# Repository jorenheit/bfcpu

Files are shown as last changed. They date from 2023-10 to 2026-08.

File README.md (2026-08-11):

# Synapse-191: A Native Brainf*ck Computer 
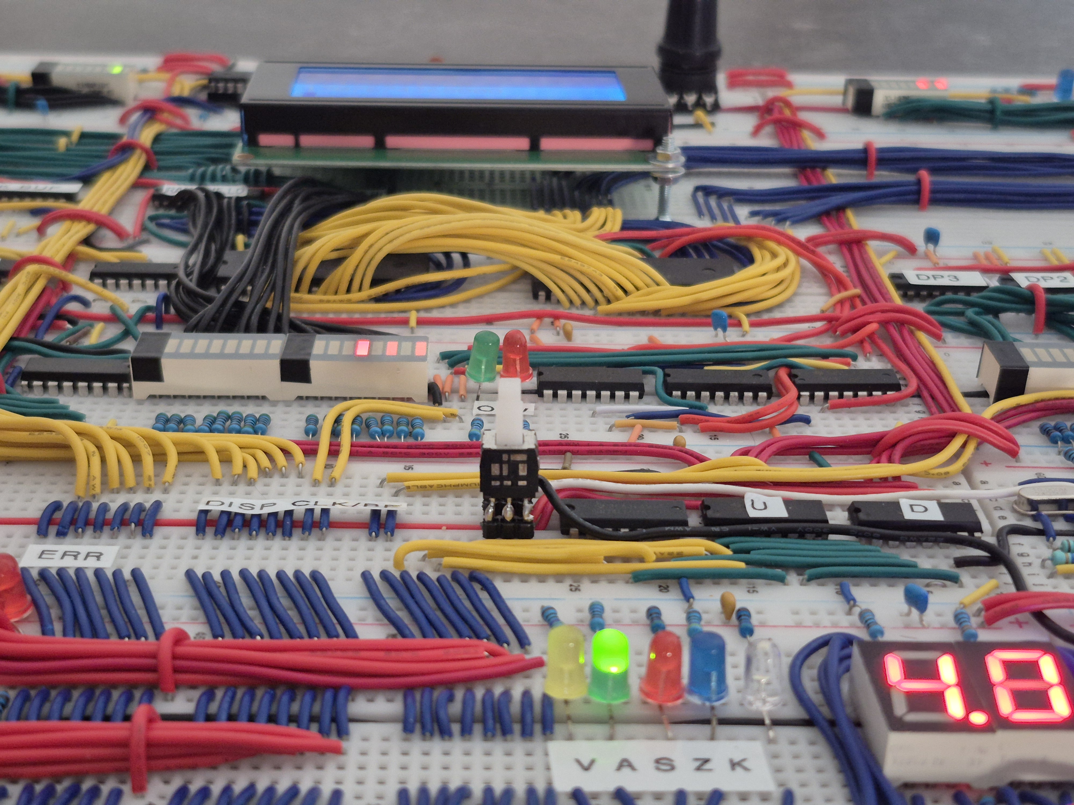
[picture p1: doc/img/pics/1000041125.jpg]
<p align="center"><kbd></kbd></p>

## Overview

**Synapse-191** is a fully functional 8-bit computer that executes Brainf\*ck (BF) programs *natively* on a breadboard CPU built entirely from TTL logic. The system is capable of running canonical Brainf*ck code directly from ROM and includes a supporting toolchain, including:
1. a compiler backend (Acus) for generating BF,
2. a microcode compiler (Mugen) for generating microcode ROM images,
3. a ROM flash utility and Arduino firmware to flash specifically the AT28C64B EEPROM chips.

For detailed design information, schematics, and background, refer to the accompanying document or website:
- **[Full Project Report (PDF)](./doc/synapse.pdf)**
- **[Web version of the report](https://jorenheit.github.io/bfcpu)**

The documentation is split in two parts: 
1. Part 1 is about building Synapse-191, including parts of the software toolchain that made this possible or easier (like the flashing utility and microcode generator). 
2. Part 2 is specifically about Acus: the software library that was developed to serve as a compiler backend for a - yet to develop - frontend. This part goes into detail about all the layers of abstraction that were developped in order to translate high-level programming concepts into the raw BF instructions.

---

## Project Goals

### Goals for Synapse-191
The initial goal of this project was to implement a working CPU that runs Brainf*ck programs *directly in hardware* — without any compilation or interpretation layers — using only discrete logic components.

- Implemented on **solderless breadboards**.
- Built entirely from **74LS-series TTL logic**.
- Only one **microcontroller** (Atmega328P) is used — exclusively for **I/O management** (LCD, keyboard, RNG).
- **Minimal preprocessing:** each Brainf*ck instruction maps directly to a hardware opcode; additional non-BF instructions generated by the assembler are used only for **initialization and system control** (NOP, INIT, WAIT\_EXT, ERR, HLT).
- **No loop-address preprocessing:** loop behavior is handled natively by the CPU logic.

### Goals for Acus
After Synapse-191 was built, a new project to build a BF compiler arose. Rather than inventing a new language and build a compiler for it, the project aimed to build a backend only. This allows for vastly different frontend implementations to re-use the same backend. The backend therefore has to be versatile and flexible. These were its design goals:

- Suitable for statically typed programming languages, supporting 8 and 16 bit signed and unsigned integers, strings and user-defined structs.
- Support for arrays of (arrays of) any of the above. Arrays must be indexable with runtime indices.
- Functions (including recursive ones).
- Pointers and function pointers.
- Global data.

**[Visit the Acus repository here.](https://github.com/jorenheit/acus)**

---

## System Features

- Supports up to **16K Brainf*ck instructions** in program memory.
- **64K-cell data tape** with **256-byte stack** for loop-address storage.
- **Advanced I/O system** supporting:
  - Keyboard input and LCD output.
  - Random number generation.
  - Multiple output and input modes (ASCII, hexadecimal, etc).
- **Adjustable clock** frequency from single-step to ~250 kHz.
- **Live frequency display** showing both clock rate and executed BF instructions per second.

<p align="center"><kbd></kbd></p>

---

## Repository Contents

### Core Tools

| Tool | Description |
|---|---|
| **bfasm** | Assembler for Brainf*ck programs. Translates BF source code into a binary image for the Synapse-191 CPU. |
| **bflash\.py** | EEPROM programming utility used to flash assembled binaries onto physical ROM chips; communicates over serial with an Arduino Nano. |
| **programmer firmware** | Firmware for the Arduino Nano that is used to program the EEPROM chips; communicates over serial with the **bflash\.py** script. |
| **io firmware** | Firmware for the Atmega328P-based I/O module. Handles the LCD display, PS/2 keyboard, random number generation, and I/O protocol. |

### External Repositories

| Repository | Description |
|---|---|
| **[Rinku](https://github.com/jorenheit/rinku)** | C++ library used to emulate and test hardware modules and microcode logic during development. |
| **[Mugen](https://github.com/jorenheit/mugen)** | Microcode compiler used to generate the control ROM images for the CPU. These are programmed once during construction. |
| **[Acus](https://github.com/jorenheit/acus)** | Compiler backend for generating BF (under construction). |

---

## Typical Workflow

1. Write a program in Brainf*ck (`.bf` file).
2. Assemble it using **bfasm** to produce a binary image.
3. Flash the binary to a ROM chip (using **bflash** or any other utility to program EEPROM chips).
4. Insert the ROM into the computer and execute the program.

### Watch the Process
Click to watch (https://www.youtube.com/watch?v=KEQ2o_t6Cj4)
---

© 2025 Joren Heit — Synapse-191 Project

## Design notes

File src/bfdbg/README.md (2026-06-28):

# `bfdbg` — terminal Brainfuck debugger

`bfdbg.py` is a self-contained Python terminal application for running and debugging Brainfuck programs. It uses the standard-library `curses` module, so on Linux/macOS it does not need extra packages.

```bash
python3 bfdbg.py program.bf
```

On Windows, install the `windows-curses` package first or run it inside WSL.

## Layout

The interface has four panes:

1. **Program** — a horizontally scrolling instruction tape. The centered instruction is highlighted, and the current instruction pointer is marked with `IP`.
2. **Memory tape** — a horizontally scrolling sparse tape with decimal, hex, and printable-character views.
3. **Output** — a virtual output screen with scrollback and ASCII/hex/decimal modes.
4. **Input terminal** — a line-buffered input pane. Lines submitted here are queued for Brainfuck `,` instructions.

## Main keys

### Execution

| Key | Action |
|---|---|
| `Right`, `Space`, `n` | Step forward one Brainfuck instruction |
| `Left`, `Backspace` | Reverse one executed instruction or cell edit using the undo log |
| `r` | Animated debug-run; redraws while running and logs compact per-instruction undo records |
| `R` | Cooperative fast-run until halt, input, or limit; redraws periodically and still logs compact per-instruction undo records |
| `x` | Reset program state: `ip=0`, `dp=0`, memory/output/input queue cleared, undo history cleared |
| `q` | Quit |
| `R` or `Esc` while running | Pause a cooperative run |
| `?` | Show help overlay |

Fast run is much quicker because it avoids redrawing after every instruction. It now yields to curses periodically, so output is flushed during long runs and keys such as `R`/`Esc`, `q`, `x`, `v`, and output scrolling remain responsive. It still records a compact inverse operation for every executed instruction, so pressing `Left` after a fast run rewinds one Brainfuck instruction at a time rather than jumping over the whole run.

### Run-to-bracket and run-to-I/O

| Key | Action |
|---|---|
| `o` | Debug-run until the next opening bracket `[` is about to execute |
| `O` | Cooperative fast-run until the next opening bracket `[` is about to execute |
| `c` | Debug-run until the next closing bracket `]` is about to execute |
| `C` | Cooperative fast-run until the next closing bracket `]` is about to execute |
| `b` | Debug-run to the current loop boundary when the instruction pointer is on `[` or `]` |
| `B` | Cooperative fast-run to the current loop boundary when the instruction pointer is on `[` or `]` |
| `.` | Debug-run until the next output instruction `.` is about to execute |
| `>` | Cooperative fast-run until the next output instruction `.` is about to execute |
| `,` | Debug-run until the next input instruction `,` is about to execute |
| `<` | Cooperative fast-run until the next input instruction `,` is about to execute |

Both debug and fast run-to commands keep compact per-instruction undo records. Debug commands redraw after each instruction and use the smaller `--run-limit`. Fast commands use the larger `--fast-run-limit` and redraw only at chunk boundaries, which keeps them responsive without destroying the speed-up.

### Program view

These are source-navigation controls; they move the program view, not the execution state.

| Key | Action |
|---|---|
| `[` | Jump view to the next opening bracket `[` |
| `]` | Jump view to the next closing bracket `]` |
| `m` | Jump view to the matching bracket, when centered on `[` or `]` |
| `{` / `}` | Scroll program view left/right by one instruction |
| `(` / `)` | Scroll program view left/right by ten instructions |
| `p` | Recenter and follow the current instruction pointer |

### Memory tape

| Key | Action |
|---|---|
| `h` / `l` | Scroll memory left/right by one cell |
| `H` / `L` | Scroll memory left/right by ten cells |
| `g` | Go to a memory address; accepts decimal or `0x...` |
| `d` | Jump back to the data pointer and follow it |
| `f` | Toggle automatic data-pointer follow |
| `e` | Edit the centered memory cell |

### Output and input

| Key | Action |
|---|---|
| `v` | Cycle output mode: ASCII, hex, decimal |
| `PgUp`, `u` | Scroll output history up |
| `PgDn`, `j` | Scroll output history down |
| `End` | Follow the bottom of the output |
| `i` | Enter input mode |
| `Enter` in input mode | Queue the current line plus a newline |
| `Esc` in input mode | Cancel input mode |

## Command-line options

```bash
python3 bfdbg.py program.bf --delay 0.01 --run-limit 100000 --fast-run-limit 10000000
```

| Option | Meaning |
|---|---|
| `--cell-bits N` | Cell width in bits. Default: `8`. Use `0` for unbounded integer cells. |
| `--delay SECONDS` | Delay between instructions during animated debug-run. Default: `0.02`. |
| `--run-limit N` | Safety cap for one debug run-to-bracket command. Default: `100000`. |
| `--fast-run-limit N` | Safety cap for one fast run command. Default: `10000000`. |

## Notes

- The Brainfuck source is filtered to the eight command characters `><+-.,[]`; comments and whitespace are ignored.
- Cells wrap at 8 bits by default. Use `--cell-bits 0` for unbounded integer cells, or another positive bit width for a different wrapping size.
- The tape is sparse and supports negative addresses, which is convenient while debugging programs that move left of zero.
- Reverse stepping uses compact per-instruction undo records rather than full snapshots. Each record stores the previous `ip`, `dp`, status flags, tick count, and only the tiny piece of state changed by the command: at most one cell value, one emitted output byte, or the input line source used by a `,`.
- Fast mode no longer creates undo gaps. It is fast because it avoids per-instruction screen redraws, not because it skips history. During long fast runs, the UI redraws periodically and polls keys, so output keeps appearing and the run can be paused or reset.
- Reset with `x` clears the machine state and undo history. It does not reload the file from disk; it restarts the already-loaded filtered program.
- Rewinding over an input command `,` treats terminal input as interactive: it restores the machine state before the command, then discards the queued line that supplied the consumed byte. This prevents a rewound `,` from silently receiving the same input again.

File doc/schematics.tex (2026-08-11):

\chapter{Schematics} \label{sec:appendix:schematics}

This appendix contains the full hardware schematics for the Synapse-191 computer. Each schematic corresponds to a specific module described in Chapter \ref{sec:implementation} of this report, including the Control Unit, Register Driver, IO Module, and various registers and memory components.

The schematics have been included as full pages for clarity and resolution. They provide a detailed view of the wiring, chip connections, and signal routing used in the physical implementation, but often do not include things like decoupling capacitors or LED indicators. The diagrams are intended to complement the modular descriptions in the main text and serve as a reference for replication, debugging, or further development.

All schematics were created during the final build phase and reflect the working configuration of the system as tested.

\includepdf[landscape=true]{schematics/masterclock.pdf}
\includepdf[landscape=true]{schematics/frequencydisplay.pdf}
\includepdf[landscape=true]{schematics/registerdriver.pdf}
\includepdf[landscape=true]{schematics/datapointerregister.pdf}
\includepdf[landscape=true]{schematics/dataregister.pdf}
\includepdf[landscape=true]{schematics/instructionpointerregister.pdf}
\includepdf[landscape=true]{schematics/stackpointerregister.pdf}
\includepdf[landscape=true]{schematics/loopskipregister.pdf}
\includepdf[landscape=true]{schematics/flagregisters.pdf}
\includepdf[landscape=true]{schematics/rammodule.pdf}
\includepdf[landscape=true]{schematics/controlunit.pdf}
\includepdf[landscape=true]{schematics/iomodule.pdf}
\includepdf[landscape=true]{schematics/eeprom_programmer.pdf}

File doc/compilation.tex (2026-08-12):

\chapter{Introduction to Acus}
\label{sec:compilation:introduction}

\section{What This is Not}
\label{sec:compilation:not}
Acus\footnote{Latin for \emph{needle}, referring to the pointer in the BF computation model.} is not a BF compiler: it is a C++ library for the development of such compilers. This chapter is \emph{not} a guide on how to use Acus. For examples and extensive API details, please visit the GitHub repository at \cite{acus}. Instead, this chapter goes through the most important concepts, methods and abstractions that allow for the translation of high-level programming concepts (like function calls and flow control) into BF.

\begin{figure}[H]
  \centering
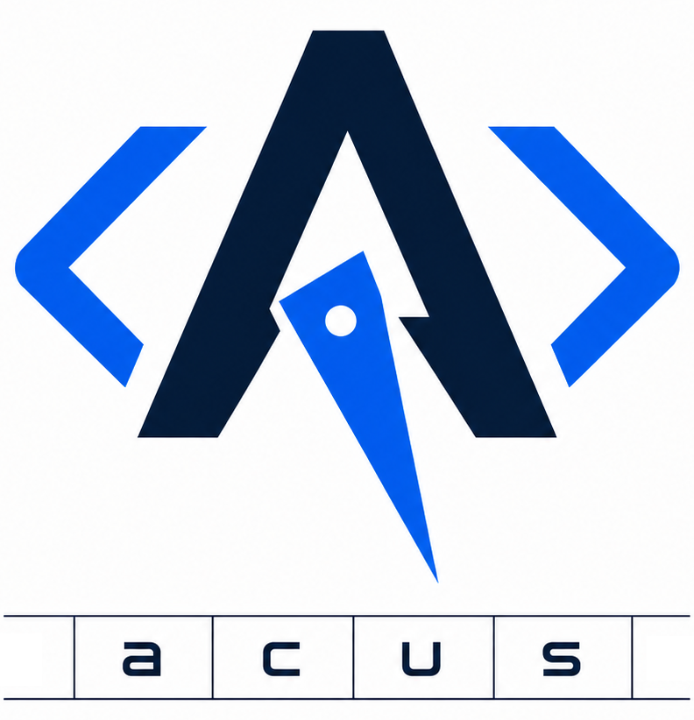
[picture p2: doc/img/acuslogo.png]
  
\end{figure}

\section{Motivation and History}
\label{sec:compilation:motivation}
Up to this point, almost every BF program used to test the computer was found online and used verbatim. On some occasions, simple BF routines were written to test very specific functions of the computer, but these were borderline trivial to produce. The next goal, therefore, was to create a compiler that takes human-readable source code and turns that into BF, which in turn can be assembled into the binary format understood by Synapse-191.

The author has attempted to create such a language and compiler in the past: \emph{BrainFix} \cite{brainfix} is a compiler that takes a C-style language and turns it into BF. This compiler works reasonably well but has some serious limitations:
\begin{itemize}\itemsep0em 
\item No (true) function calls: all functions are inlined. Recursion is therefore \emph{not} possible.
\item Dynamic array accesses were implemented in a way that limits the maximum array size to 256 elements.
\item Only 8-bit numbers are supported (assuming the BF tape stores 8-bit integers in its cells).
\item No signed integers.
\item No pointers or function pointers.
\end{itemize}
%
These limitations derive from naive choices during early development of the compiler, where the focus was on parsing and language design: features were bolted on rather than planned for in the early stages of development. In this second, more mature attempt to build a compiler, we started out by building a backend rather than a full compiler: \emph{Acus}. Acus is a C++ library that exposes a set of elementary assembly-like instructions (like arithmetic operations, conditional expressions and jumps) that are compiled into BF. Acus is meant to be used as a compiler backend: a layer that accepts higher-level operations and emits BF code. A frontend can then link with Acus, parse an actual programming language, call the necessary Acus functions and produce the corresponding BF. Acus can also be used on its own, since its library functions were designed to feel a bit like an actual language, as can be seen from the \emph{Hello World} snippet of Listing \ref{lst:acushello}\footnote{Note that using Acus in this way is unintended and inconvenient: the resulting binary is a program that, when run, prints a string of BF commands to the output. That string of commands then has to be written to a file, which can then be executed by a BF computer or interpreter. When the program is modified, the C++ source has to be recompiled and the resulting executable rerun to produce the updated BF source.}

\begin{lstfloat}[H]
  \begin{lstlisting}[style=cpp]
    #include <iostream>
    #include "acus/assembler/assembler.h"
    using namespace acus;

    int main() {
      Assembler a;

      a.program("hello", "main").begin(); {

        a.function("main").begin(); {
          a.print(literal::string("Hello, World!\n"));
          a.returnFromFunction();
        } a.endFunction();

      } a.endProgram();
      
      std::cout << a.brainfuck("hello") << '\n';
    }
  \end{lstlisting}
  \caption{C++ code that calls into the Acus-library to produce an executable that outputs BF source code for a \emph{Hello World} program.}
  \label{lst:acushello}
\end{lstfloat}

\section{Challenges and Design Goals}
\label{sec:compilation:designgoals}
The main goal was to make Acus capable enough that a frontend for a language like C would have no problem implementing most of its features. These include:
%
\begin{enumerate} \itemsep0em 
\item 8-bit and 16-bit integer data types;
\item signed integers (both 8-bit and 16-bit);
\item arrays and strings;
\item user-defined structured types (structs);
\item arithmetic operators (\texttt{+, -, *, /, \%});
\item logic operators (\texttt{and, or, not, xor});
\item function calls and recursion;
\item pointers and pointer arithmetic;
\item labels and conditional jumps (\texttt{goto});
\item global data.
\end{enumerate}
%
Familiar features that were \emph{not} implemented include:
\begin{enumerate} \itemsep0em 
\item floating/fixed-point numbers;
\item bitwise operators;
\item member functions;
\item control-flow mechanisms like \texttt{for, while, switch, if}.
\end{enumerate}
%
Many of the above can be implemented in terms of the features provided by Acus; it was a deliberate choice not to make these part of the library in order for the library to remain as fundamental as possible.

\chapter{Acus Program Model}
\label{sec:compilation:programmodel}

\section{Basic Block Scheduling}
\label{sec:compilation:program}
In the Acus model, a program consists of a series of basic blocks, sequences of code that are always executed in order, and jumps between those blocks. Each basic block ($B_i$) is compiled into its corresponding BF instructions and wrapped in a BF loop pair (i.e.~between \texttt{[} and \texttt{]}) whose entry is controlled by generated guard code $G_i$. The complete sequence of blocks is enclosed in a main loop, conditional on the value in a special BF cell, the \emph{Run} cell, which can be reset by any block when the program should be terminated. Prior to entering the main loop, a \emph{head} section $H$ is responsible for the initial setup of the data tape and the tail code $T$ is responsible for resetting the pointer to the \emph{Run} cell before the closing bracket of the main loop is encountered:

\begin{center}
  
\end{center}

The aforementioned guard code $G_i$ compares the block index $i$ to the value stored in another predefined cell: the \emph{TargetBlock} cell. Only when this cell contains the exact index of the block \emph{and} the \emph{Run} cell is still nonzero is the loop entered and its code executed. Therefore, each block should at some point set the index of the next block to be executed to keep the program going (not setting a different \emph{TargetBlock} will cause the same block to be executed ad infinitum). This approach basically implements a state machine that can be expressed in pseudocode as shown in Listing \ref{lst:acusprogram}. Note that, on each iteration of the main loop, all blocks are scanned until the scheduled block is encountered. In a worst-case scenario, when block \texttt{i} is scheduled by block \texttt{i+1} (the currently executed block), the system will first need to check all blocks from \texttt{i+2} up to \texttt{N} before looping back to block 1 and eventually block \texttt{i}.

\begin{lstfloat}[H]
  \begin{lstlisting}[style=pseudocode]
    B = {B1, B2, ..., Bn}

    Run = 1
    TargetBlock = 1 # not necessarily block 1

    while Run:
      for i = 1 ... N:
        if Run AND TargetBlock == i:
          execute B[i] 
  \end{lstlisting}
  \caption{Pseudocode of an Acus-generated program.}
  \label{lst:acusprogram}
\end{lstfloat}

\section{Frames and Initialization}
\label{sec:compilation:framesinit}
Each function has its own chunk of memory that it operates on, called a frame. Calling a function has the effect of advancing the data pointer one cell beyond the end of the current function's frame. When a BF program is executed, the pointer starts at cell 0 in frame 0, which is dedicated to holding the global data (Section \ref{sec:compilation:globalframe}). Frame 1 starts just beyond the end of frame 0; the exact offset depends on the number of global variables and their sizes. The initialization code that runs prior to entering the main loop needs to set up both frame 0 and frame 1:
%
\begin{enumerate}
\item Set a marker (the \texttt{SeekMarker}, Section \ref{sec:compilation:seekmarker}) at the start of the data-tape (cell 0). This marker can be used as a stop-sign during dynamic pointer movements to locate the start of the global data frame (and to prevent the pointer from moving into the (undefined) negative address-space).
\item Set another marker (the \texttt{FrameMarker}) that marks the start of frame 0 (the global data frame, Section \ref{sec:compilation:globalframe}). This might seem redundant as we already marked the start of this frame with a \texttt{SeekMarker}, but since every frame has a \texttt{FrameMarker}, the global frame needs it as well for generalized algorithms to work.
\item Calculate the size of frame 0 and move the pointer to the start of frame 1 (the frame that will be used by the function that is set as the entrypoint for the program). 
\item Mark the start of frame 1 by setting the \texttt{FrameMarker} here as well.
\item Move the data pointer to the \emph{Run} cell of frame 1 and set its value to 1.
\item While the data pointer points to the \emph{Run} cell of frame 1, open the main loop (guaranteed to be entered as we just set this cell to 1).
\end{enumerate}

\section{Block Guards}
\label{sec:compilation:blockguards}
The guards $G_i$ compare the value stored in the \texttt{TargetBlock} cell to their index and check if the \emph{Run} flag is still set. The results of these comparisons are ANDed together and used as the loop condition for the block that follows immediately after. Because the block index is known at compile time, it can simply be subtracted from (a copy of) the \texttt{TargetBlock} value. If the result is 0, this means we should enter the block given that the \emph{Run} cell contains a nonzero (true) value. The logic necessary to implement these checks is discussed in more detail in Section \ref{sec:compilation:logic}. A simplified BF algorithm that implements this logic could look like the snippet of Listing \ref{lst:guard}; the real algorithm is more complicated because it needs to support 16-bit block indices (otherwise each program would be limited to only 255 code blocks), which requires 16-bit arithmetic and logic routines (Section \ref{sec:compilation:arithmetic}).

\begin{lstfloat}[H]
\begin{lstlisting}[style=brainfuck]
  # Guard code G3: computes ``r AND i == 3''
  # r: cell that contains a copy of the run-flag
  # i: cell that contains a copy of the target-index
  # f: cell that will contain the guard-flag (result of r AND i == 3)

  f [-]                  # reset f
  r [                    # if run
    f +                  # set guard-flag to 1
    i --- [              # subtract 3 from i, check if nonzero
      f -                # still nonzero -> set flag to zero
      i [-]              # exit i-loop
    ]
    r -                  # exit r-loop
  ]

  # At this point, f is set only when r was set and i == 3  
  f [                    # move pointer to guard-flag
    ...                  # user code (block 3)
  ]

\end{lstlisting}
\caption{Simplified guard code for block 3 ($G_3$). The contents of block 3 will be executed only if \texttt{f} is nonzero.}
\label{lst:guard}
\end{lstfloat}

\section{Example: Fibonacci}
\label{sec:compilation:fibonacci}
To illustrate how a program is divided into basic blocks, a simple Fibonacci number generator is shown in Figure \ref{fig:fibexample}. It consists of three functions, each of which contains multiple basic blocks. The block IDs are shown in square brackets at the start of each block. Blocks end at control boundaries, i.e.~places in the code where potential jumps take place, or explicitly at predefined labels.

The program starts execution in block 10, which is set as the entry point by the initialization code (note that the initialization code of Listing \ref{lst:acusprogram} sets the entry point to block 1; the specific example below requires the initialization sequence to set this value to 10 instead). A function call is immediately encountered, ending the current block. After initializing a new stack frame (this will be covered later, in Section \ref{sec:compilation:frames}), the \emph{TargetBlock} is set to block 1: the entry block index of the callee. This will cause control flow to skip over block 11 and loop back to block 1, which will then be entered. When control hits the conditional statement of block 3, either block 4 or 5 will be set as the next target block, depending on the result of evaluating \texttt{i < n}. In this case, both the \texttt{if} and \texttt{else} bodies contain only a single block that immediately terminates in a jump. When control eventually reaches the end of \texttt{main}, the \emph{Run} cell is set to zero, causing flow to exit the main loop and terminate the program.

\begin{figure}[H]
  \centering
  \begin{subfigure}{0.4\linewidth}
    \centering
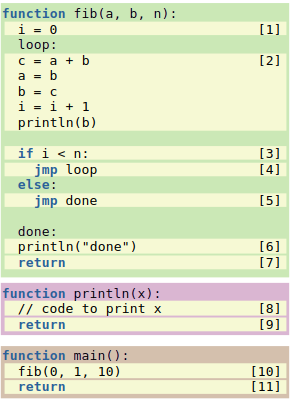
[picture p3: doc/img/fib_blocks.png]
    
    \caption{Fibonacci program}
    \label{fig:fibblocks}
  \end{subfigure}
  \hspace{1cm}
  \begin{subfigure}{0.4\linewidth}
    \centering
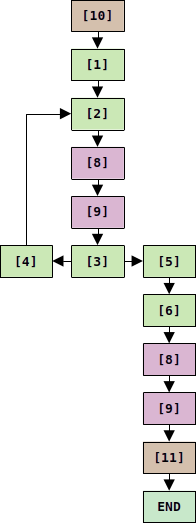
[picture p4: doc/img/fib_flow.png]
    
    \caption{Control flow}
    \label{fig:fibflow}
  \end{subfigure}
  \caption{Figure (a) shows a simple Fibonacci program (unspecified syntax) and how that program is split into blocks. Figure (b) shows how control flows from one block to another.}
  \label{fig:fibexample}
\end{figure}

\chapter{Tape Abstractions}
\label{sec:compilation:tape}
\section{Overview}
\label{sec:compilation:tapeoverview}
The data-tape is considered a stack, where each function owns a stack frame. Each frame is composed of slots: a return-slot (if the function returns a value), argument-slots (if the function takes arguments) and local data-slots (variables and temporaries used in the function). A slot is a series of (logical) cells that contains a variable of some data-type, used by the function. The size of a slot depends on the number of cells required to represent the type of the variable. Instead of using single BF-cells to compose slots, logical cells or macro-cells are used. Each macro-cell contains 9 actual BF-cells, referred to as \emph{fields} from now on, each of which serves a different purpose.
\[
\text{BF Cell}
\longrightarrow
\text{MacroCell}
\longrightarrow
\text{Slot}
\longrightarrow
\text{Frame}
\longrightarrow
\text{Tape}
\]
A macro-cell contains the following fields (in arbitrary order), each of which will be discussed in more detail in Section \ref{sec:compilation:macrocells}.
\begin{enumerate}\itemsep0em 
\item \texttt{Value0}: Low-byte of the semantic value of the macro-cell.
\item \texttt{Value1}: High-byte of the semantic value of the macro-cell.
\item \texttt{Scratch0}: General-purpose scratch-cell.
\item \texttt{Scratch1}: General-purpose scratch-cell.
\item \texttt{Payload0}: Low-byte of a payload (or another scratch-cell).
\item \texttt{Payload1}: High-byte of a payload (or another scratch-cell).  
\item \texttt{Flag}: Dedicated flag cell to guard BF-loops.
\item \texttt{FrameMarker}: Dedicated cell to mark the start of a new frame.
\item \texttt{SeekMarker}: Dedicated cell to mark arbitrary locations on the tape.
\end{enumerate}

Central to the macro-cells are the two value-fields that hold the actual value of the logical cell. By having two value fields, we allow for 16-bit data types to be implemented within the same logical-cell, rather than having to allocate two macro-cells for a single 16-bit variable. The other fields hold temporary data or metadata required to perform higher level functions like arithmetic, flow control and dynamic pointer movement. When the compiler needs to generate code that moves the BF-pointer to location known only at runtime (for example when dereferencing pointers or accessing array elements by a dynamic index), these fields can hold temporary values or metadata necessary to perform the move. Other non-value fields include temporary scratch-pads (heavily used when performing arithmetic operations), payload-fields (used to transport data to locations known only at runtime) and a flag cell that is dedicated to the evaluation of loop-conditions. Having all these fields near one another on the BF-tape has the nice consequence of BF-algorithms being relatively short due to tight pointer-move-sequences.

\subsection*{Example: Fibonacci (continued)}
Figure \ref{fig:tapehierarchy} shows the tape hierarchy described above, applied to the Fibonacci example from before and evaluated immediately after \texttt{fib} was first called. Even though this program made no use of any global data, this frame is still depicted for completeness' sake. Zooming in on Frame 2, used by the \texttt{fib} function, we see how a frame starts with the slots we previously encountered in Section \ref{sec:compilation:program}: the \texttt{TargetBlock} and \texttt{Run} slots, which are used to determine where to jump next and whether to continue execution at all. Since \texttt{fib} does not return anything, no return slot has been allocated to this frame. Instead, the local data immediately follows: first the arguments passed to the function (initialized by the caller), then the local data used within the function. Only the variables \texttt{c} and \texttt{i} have been explicitly allocated by the programmer, but temporary slots have been created by the compiler to store the result of \texttt{a + b} and \texttt{i < n}.

Zooming in further on two of the slots, we see that they both contain only a single macro-cell and its 9 constituents. The first slot of the frame (\texttt{TargetBlock}), which still holds ID 1 (the block-ID of the first block of the function) in its value-field, also has its \texttt{FrameMarker} field set, indicating that this is where a new frame starts on the data-tape. The \texttt{b}-slot has its value-field set to 1 as well, corresponding to the value of \texttt{b} that was passed to \texttt{fib} from \texttt{main}. 

The sections below go into more detail about each of the layers of abstraction.

\begin{figure}[H]
  \centering
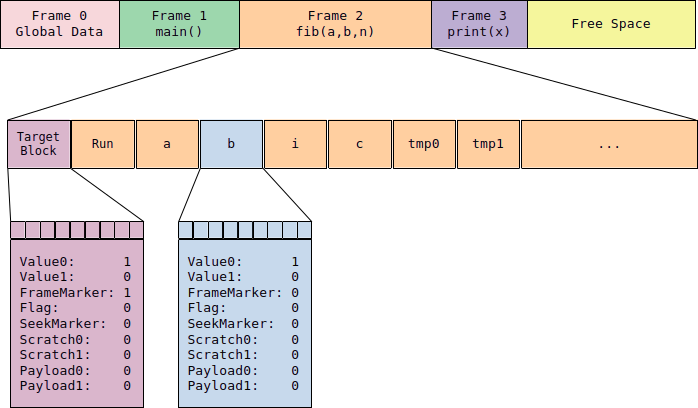
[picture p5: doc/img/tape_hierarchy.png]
  
  \caption{Acus tape hierarchy: the tape is divided into frames, which are divided into slots, which consist of macro-cells containing 9 fields (BF-cells).}
  \label{fig:tapehierarchy}
\end{figure}

\section{Cells and Macro-Cells}
\label{sec:compilation:macrocells}
BF operates on the most fundamental level of raw cells. Each consecutive sequence of 9 such cells constitutes a logical macro-cell as mentioned before in Chapter \ref{sec:compilation:tape}. In this section, we will cover each of the 9 fields of a macro-cell in more detail and cover some of their use cases.

\subsection{\texttt{Value0} and \texttt{Value1}}
\label{sec:compilation:valuefields}
The value fields together hold the semantic value of the macro-cell. The \texttt{Value0} field contains the low byte and the \texttt{Value1} field holds the high byte of an integer of at most 16 bits. Acus implements four integer data types using these two fields: unsigned 8-bit (\texttt{u8}), unsigned 16-bit (\texttt{u16}), signed 8-bit (\texttt{s8}) and signed 16-bit (\texttt{s16}). When referring to 8-bit values, the \texttt{Value1} field is simply ignored. Signed integers are represented using two's complement; some algorithms need to do some additional work (like evaluating the sign bit) before applying the usual operations.

\subsection{\texttt{Scratch0} and \texttt{Scratch1}}
\label{sec:compilation:scratchfields}
Many BF algorithms need temporary cells as scratch-pads. These cells can be temporarily claimed by an algorithm and must be left behind empty for the next algorithm to use. An example of a simple algorithm that makes use of these values is the non-destructive addition. Say we want to add the contents of cell \texttt{x} to those of cell \texttt{y} without destroying \texttt{x} in the process. We can achieve this by decrementing \texttt{x} while at the same time incrementing \texttt{y} until \texttt{x} becomes zero. However, in order to restore \texttt{x} to its original value, we need to use a scratch-pad to construct a copy of \texttt{x} which is moved back after the addition has been completed. This algorithm is shown in Listing \ref{lst:bfadd}, where instead of denoting pointer-movement with sequences of \texttt{<} and \texttt{>}, we simply write the name of the variable/slot to indicate a move to that (known) location on the tape.

\begin{lstfloat}[H]
\begin{lstlisting}[style=brainfuck]
  # Algorithm for y += x
  # tmp is a scratch-cell assumed 0

  # Step 1: add x to both y and tmp, destroying x
  x[- y+ tmp+ x]

  # Step 2: add tmp back to the now empty x
  tmp[- x+ tmp]
\end{lstlisting}
\caption{Non-destructive addition of one cell to another, using a temporary scratch cell.}
\label{lst:bfadd}
\end{lstfloat}

\subsection{\texttt{Flag}}
\label{sec:compilation:flag}
The \texttt{Flag} field is reserved to store a value that determines whether or not a BF-loop should be entered. An algorithm can store an intermediate, temporary, value in the flag-cell and use that as a branch or loop-condition. Whereas scratch-cells are general purpose temporary storage locations, the flag-cell is meant to be used for this purpose alone to avoid confusion. The subsection below includes an example that also utilizes this field in Listing \ref{lst:bfseekframe}.

\subsection{\texttt{FrameMarker}}
\label{sec:compilation:framemarker}
The \texttt{FrameMarker} field is only set when the macrocell marks the start of a new frame. When performing dynamic pointer movements, a marker like this (the \texttt{SeekMarker} is used in a similar way) can be used to move from a still unknown to a known location on the tape. Let's say we know the data-pointer is somewhere in Frame 2, but we don't know where because we just performed some (dynamic) movement (i.e. an algorithm that moves the pointer by an amount that depends on runtime data). We know that the start of the frame is to the left of the current position, so we can perform the algorithm below and be sure that we're pointing at the start of the frame when the algorithm is finished. This algorithm is shown in the pseudo-BF of Listing \ref{lst:bfseekframe}. This works because every macro-cell has the same width and because exactly one FrameMarker is set at the start of the active frame.

\begin{enumerate}
\item Move the pointer to the \texttt{FrameMarker} field of the current cell. Even though the current offset is unknown, the current field \emph{is} known so we are able to switch between fields reliably.
\item Construct the logical \texttt{NOT} of the \texttt{FrameMarker} and store the result in the \texttt{Flag} field, then move the pointer to the \texttt{Flag} field.
\item Enter a loop, conditioned on the flag, where the pointer is moved 9 cells to the left on each iteration until a non-zero \texttt{FrameMarker} is encountered. In each iteration, the logical \texttt{NOT} has to be constructed and stored in the \texttt{Flag} field as before. Note that when inside a loop (meaning the flag was nonzero), the flag needs to be cleared before moving to the adjacent cell.
\end{enumerate}

\begin{lstfloat}[H]
  \begin{lstlisting}[style=brainfuck]
    # Algorithm to move the pointer back to the start of the frame
    # Current macro-cell offset is unknown; all moves are relative
    # field-switches within the same macro-cell, except for the
    # 9 left-moves, which take us exactly one macro-cell to the left.

    # Assumed: there are already implementations for assignment and
    #          the logical NOT operator.
    
    ASSIGN(Flag, NOT(FrameMarker))
    Flag [-                            # Reset flag before moving away from it
      FrameMarker  <<<<<<<<<           # Move to the frame-marker field of
                                       #   neighboring macro-cell
      ASSIGN(Flag, NOT(FrameMarker))   # Compute exit-condition
      Flag                             # Check exit-condition
    ]

    # Out of the loop: pointer is at the start of the frame
  \end{lstlisting}
  \caption{Algorithm to seek left to the start of the current frame from an unknown initial position.}
  \label{lst:bfseekframe}
\end{lstfloat}

\subsection{\texttt{SeekMarker}}
\label{sec:compilation:seekmarker}
The purpose of the \texttt{SeekMarker} field is very similar to that of the \texttt{FrameMarker} field, in the sense that it is used to mark certain cells to make dynamic movement possible. For example, a known location can be marked before performing a dynamic move, in order to be able to move back to that known location using an algorithm similar to that of Listing \ref{lst:bfseekframe}. Also, when a dynamic move has been completed, its location can be marked to make future excursions to this location more efficient. Contrary to the \texttt{FrameMarker}, which is specifically used to mark the start of a frame, the \texttt{SeekMarker} field may be set for any macro-cell on the tape.

\subsection{\texttt{Payload0} and \texttt{Payload1}}
\label{sec:compilation:payloadfields}
The payload fields are used to store values that need to be transported along to dynamically determined locations. Algorithms that move the pointer to such locations can be trivially extended to move data along using these fields: one for the low byte and one for the high byte of the value. Additionally (but this is not the intended use-case), a payload cell may be used as a scratch-pad (when an algorithm has exhausted the available scratch cells), provided it is not being used to transport any values at that time.

\section{Slots}
\label{sec:compilation:slots}
A slot is a storage location for one object. Single 8 or 16-bit integers occupy a single macro-cell, while larger objects like arrays or structs occupy a sequence of macro-cells. A slot is bound to a stack frame; its offset is defined as the index of its first macro-cell with respect to the start of the frame, not the start of the actual BF data-tape.

In addition to a name and offset, a slot holds information about its scope (to determine access, allow for name-shadowing and keep track of lifetime) and its \emph{kind}. Most slots are of the \emph{local} kind, representing data local to the current function, but slots can also be tagged \emph{global}, \emph{available} (representing a free block of memory that was previously occupied), \emph{temp} (for temporary slots that should be freed after use) and \emph{cache} (Chapter \ref{sec:compilation:cache}). Figure \ref{fig:slots} shows a section of a frame and how local slots could be organized given their data-types and sizes. Note that the size of a slot is expressed in terms of the number of macro-cells rather than raw BF cells.

\begin{figure}[H]
  \centering
  
  \caption{Slots represent variables, which may span multiple macro-cells.}
  \label{fig:slots}
\end{figure}

\subsection{Data Types}
\label{sec:compilation:datatypes}
Slots reserve space on the tape, but the compiler also needs to know how that space should be interpreted. This is the role of data types. A data type determines how many macro-cells are needed to store a value, which sub-slots exist inside that value, and which algorithms may be used to copy, compare, increment or otherwise manipulate it.

Primitive integer types (such as \texttt{u8} or \texttt{s16}) are stored directly in the value fields of a single macro-cell (even 16-bit integers fit in a single logical cell). Compound types (arrays and structures) are constructed from these primitives. An array is represented as a sequence of equally sized elements, while a structure is represented as a sequence of fields at fixed offsets. As a result, the compiler can compute the size of every type and the offset of every field at compile-time.

\begin{table}[H]
\centering
\begin{tabularx}{\textwidth}{r c X}
\hline
\textbf{Type} & \textbf{Size (\# macro-cells)} & \textbf{Description} \\
\hline
\texttt{u8} &
1 &
Unsigned 8-bit integer stored in one value field. \\

\texttt{s8} &
1 &
Signed 8-bit integer, stored using the same physical layout as \texttt{u8}. \\

\texttt{u16} &
1 &
Unsigned 16-bit integer stored across both value fields of a macro-cell. \\

\texttt{s16} &
1 &
Signed 16-bit integer, stored using the same physical layout as \texttt{u16}. \\

\texttt{array<T, N>} &
$N \cdot \mathrm{sizeof}(T)$ &
Fixed-size sequence of \texttt{N} values of type \texttt{T}, stored contiguously. \\

\texttt{string<N>} &
$N$ &
Fixed-size character buffer, equivalent in layout to an array of \texttt{N} byte-sized characters. \\

\texttt{ptr<T>} &
2 &
Pointer to a value of type \texttt{T}. The type parameter determines how dereferenced storage is interpreted. The first cell contains the \texttt{FrameDepth} of the pointer, i.e. how many frames back the pointee is actually stored. The second cell stores the offset of the pointee within its frame. Refer to Section \ref{sec:compilation:pointers} for more details on pointers. \\

\texttt{struct}-defined type &
sum of field sizes &
User-defined aggregate type. Fields are stored consecutively at statically known offsets. \\
\hline
\end{tabularx}
\caption{Overview of the data types supported by Acus. Sizes are measured in macro-cells rather than raw Brainfuck cells.}
\label{tab:acus-types}
\end{table}

\subsection{Slot Proxies and Materialization}
\label{sec:compilation:slotproxies}
Most expressions encountered by the compiler can be resolved directly into a slot. For example, assume \texttt{x} is an array of structs that contain an \texttt{age} field, e.g. 

\begin{lstlisting}
  struct Person {
    id:  u16
    age: u8
  };

  let x: array<Person, 5>;
\end{lstlisting}

In this context, the expressions \texttt{x}, \texttt{x[2]} and \texttt{x[2].age} all refer to known slots or sub-slots (assuming square brackets represent array indexing and a dot represents field access for struct objects). The compiler knows in which slot the array \texttt{x} is stored, how to find the offset of element 2 and how to find the offset of the \texttt{age} field.

However, when the index is not a compile-time constant, things change. The expression \texttt{x[i].age} has the same shape as \texttt{x[2].age} (they might even refer to the same data), but now the compiler has no way to compute the desired offset at compile-time. At this point, the expression can no longer be represented by a single statically known slot. The array itself still has a known base location, and the layout of each \texttt{Person} object is still known, but the particular element that should be accessed depends on a value computed at runtime. In Brainfuck terms, the compiler must now generate code that moves through the tape dynamically, using the value of \texttt{i} to reach the correct element before applying the fixed offset of the \texttt{age} field.

This is where Acus introduces the notion of a \emph{slot proxy}. A slot proxy is not necessarily a slot by itself, but a description of how a value can be accessed. Some proxies are direct: they simply refer to an already known slot. Others are indirect: they describe an access path that must be resolved at runtime. The expression \texttt{x[2].age} can be reduced to a direct sub-slot, while \texttt{x[i].age} becomes a proxy that says, in effect: start from the slot occupied by \texttt{x}, use the runtime value of \texttt{i} to select an element, and then access the \texttt{age} field within that element. In general, modifications made to that element (e.g. \texttt{x[i].age += n}) will need a read-modify-write cycle where the element is first \emph{materialized} into a known, temporary slot (much like a hardware register), modified and written back using a dynamic write-algorithm. This process of materialization and write-back is shown conceptually in Figure \ref{fig:materialization}.

\begin{figure}[H]
  \centering
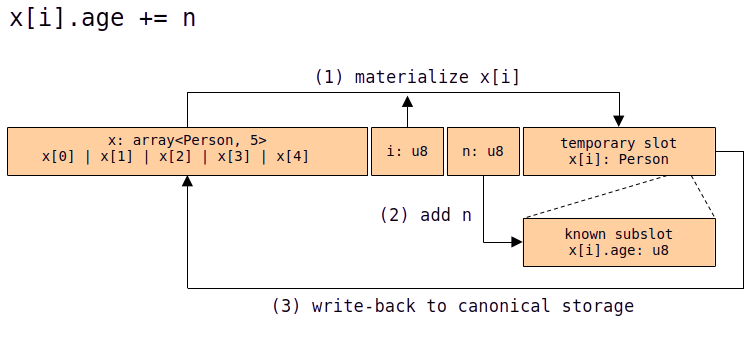
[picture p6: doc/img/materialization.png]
  
  \caption{Materialization process for a modification to a dynamically indexed array.}
  \label{fig:materialization}
\end{figure}

The distinction between actual slots and proxies that represent them allows the compiler to treat simple variables, struct fields, array elements and pointer dereferences in a uniform way. Code that needs to read from or write to an expression does not have to know immediately whether the target is a fixed slot or a dynamically computed location. It can ask the proxy to materialize the value into a concrete slot, or to write a concrete value back through the described access path.

For the purposes of this chapter, slot proxies should therefore be understood as compiler-level access paths. They bridge the gap between the static memory layout known at compile-time and the dynamic addresses that sometimes have to be computed at runtime. This idea becomes especially important in the caching system (Chapter \ref{sec:compilation:cache}), which is designed to limit unnecessary materialization and synchronization events.

\subsection{Local Memory Management}
\label{sec:compilation:localmemory}
Declaring a local variable means reserving a slot inside the current function frame. The slot is assigned a type, a size and an offset relative to the start of the frame. From that point onward, the variable name refers to this slot until it goes out of scope. Since the offset is fixed, accessing a local variable does not require a runtime search through the tape.

Temporary slots are allocated in the same frame when the compiler needs short-lived storage. This happens, for example, when evaluating intermediate expressions, materializing a slot proxy, or running algorithms that require additional scratch space. Unlike named locals, temporaries are not part of the source-level program and may be released as soon as the generated code no longer depends on their contents.

When a slot is freed, either because a local variable leaves scope or because a temporary can be dismissed, its region is marked as available. The contents of the underlying macro-cells are not necessarily cleared immediately; freeing a slot only means that the compiler is allowed to reuse that region for later storage. When a new slot is allocated, a sufficiently large available region may be split into an occupied part and a smaller remaining available part. Conversely, when a slot is freed, neighbouring available regions are merged back together. This prevents the local frame from becoming unnecessarily fragmented and allows larger slots to be allocated later when enough adjacent macro-cells have become free. This management system is discussed in more detail in Chapter \ref{sec:compilation:memorymanagement}.

\section{Frames and Calls}
\label{sec:compilation:frames}
A frame groups all data belonging to one function activation. Each frame contains the local control cells, optional return storage, arguments, named locals and compiler-generated temporaries (and cached values). Function calls can then be viewed as transitions between frames: the caller prepares the callee frame, moves the data-pointer to the start of the frame and sets the \texttt{TargetBlock} value to the callee's entry block. When a function returns, the data-pointer is moved back to the caller's frame and execution continues at the first block beyond the call. Each of these steps will be described in more detail in the sections below.

\subsection{Reference Frames}
\label{sec:compilation:referenceframes}
Each stack frame acts as a frame of reference, or coordinate system, to the data-pointer. Since function calls happen dynamically, stack frames are allocated dynamically as well. This means that the compiler has no way of knowing where the data-pointer is located in an absolute sense (i.e. with respect to the start of the BF-tape). Instead, it keeps track of the pointer-location with respect to the start of the current frame. Pushing a new frame on top of the stack and moving the pointer to the start of this frame can then be seen as performing a coordinate transformation---or rebase---of the pointer: the origin is now in the frame of the callee rather than the caller.

\subsection{Global Data Frame}
\label{sec:compilation:globalframe}
Global data is allocated in its own frame at the very start of the data-tape, i.e. frame 0. This frame is not owned by any function and is accessible from any other frame to fetch data from or write to. Like dynamic array accesses or pointer dereferences, a global slot is accessed through a slot-proxy and will be materialized locally before any work can be done on it. This introduces synchronization issues across call boundaries, which will be addressed in Chapter \ref{sec:compilation:cache}. In the sections below, the concept of (stack) frames refers to frames actually tied to the functions being executed, not the global frame.

\subsection{Frame Layout}
\label{sec:compilation:framelayout}
The exact layout of a frame depends on the nature of the function that it belongs to, depending on the return-type and number of arguments it takes. However, each instance of a function-call will cause an identical frame-layout to be generated as a result. In general, a frame is laid out as follows (in terms of macro-cells):
\begin{enumerate}
\item \texttt{TargetBlock}: a macro-cell whose \texttt{Value} fields are set to the index of the next block scheduled for execution and whose \texttt{FrameMarker} is set to 1, indicating the start of a new frame.
\item \texttt{Run}: a macro-cell dedicated to storing a local copy of the program's \emph{run}-state. As soon as this flag is set to 0 (from any frame), none of the blocks will execute and the main loop will be aborted.
\item \texttt{ReturnSlot}: Depending on the return-type of the function, a slot is allocated to hold the return-value. Note that this slot is located at a fixed offset, so it can be reached easily even from within the caller's frame in order to fetch the return-value. If the function returns \texttt{void}, this slot does not exist at all.
\item \texttt{Locals}: Data local to the frame, which can be categorized further:
  \begin{enumerate}
  \item local variables (including function arguments), organised in slots as discussed before in Section \ref{sec:compilation:slots}.
  \item compiler-generated temporaries
  \item cached materializations
  \end{enumerate}
\end{enumerate}

\subsection{Calls, Returns and Meta-Blocks}
\label{sec:compilation:metablocks}
\paragraph{Calls} To call a function, the caller has to perform the following actions:
\begin{enumerate}
\item Set the caller's \texttt{TargetBlock} to the ID of a compiler-generated meta-block. This is the continuation that will run after the callee returns (described in the next paragraph).
\item Copy or materialize the function arguments into the argument slots of the next frame. The offsets are known relative to the caller's frame, so this does not require a runtime search.
\item Initialize the control cells of the callee frame: its \texttt{Run} cell is set and its \texttt{TargetBlock} is set to the callee's entry block.
\item Move the data pointer to the start of the callee frame and treat this position as the new origin.
\end{enumerate}
After these steps, the runtime naturally dispatches to the block whose ID is now stored in the \texttt{TargetBlock} cell of the freshly initialized stack frame.

\paragraph{Meta-blocks} These are compiler-generated code-blocks that are scheduled at the time of the call, while still in the caller's frame. When the pointer is popped back to this frame after the callee returns, this is the value that is observed and used to determine the next block to be executed. This block is then responsible for making sure that
\begin{enumerate}
\item the return value is fetched from the callee's frame and copied into the return-slot of the caller (if provided; it may also be ignored),
\item the state of the \emph{run}-flag is copied back into the caller's frame (to propagate its state in case the callee changed it), and 
\item the \texttt{TargetBlock} cell is set to the ID of the block following the call.
\end{enumerate}

Propagating the \emph{run}-flag like this makes early termination compositional: if a callee stops the program, the caller observes the same stopped state after the return metablock has run. This allows a (builtin) function like \texttt{abort()} to be implemented.

\paragraph{Returns} To return control to the caller, we only need to make sure that the return-slot is populated appropriately and pop the data-pointer back to the frame below. The meta-block has already been scheduled and will take control immediately, finishing the transaction as described above.

Figure \ref{fig:call_return} shows data transfers and the setup that occurs while performing a call and returning from it. At the call-site, the target-blocks are set and arguments are copied over to the next frame. When returning and control has been passed to the meta-block, return-data is copied back from the callee's frame into the current one.

\begin{figure}[H]
  \centering
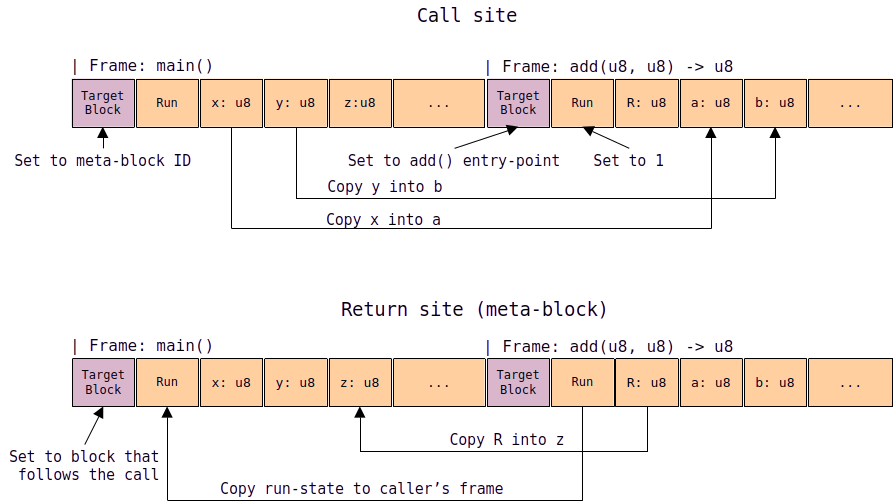
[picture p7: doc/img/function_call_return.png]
  
  \caption{Conceptual overview of data-tape manipulations that occur when calling a function and returning from it. This graphic assumes that in between these two moments, the \texttt{add} function has populated the return-slot (\texttt{R}).}
  \label{fig:call_return}
\end{figure}

Notice that the return address is not stored on a hardware stack. It is encoded as a block ID in the caller’s \texttt{TargetBlock} cell. Returning to the caller therefore means restoring the caller frame; the scheduler will then execute the metablock whose ID was already waiting there.

\chapter{Memory Management}\label{sec:compilation:memorymanagement}
\section{Overview}
Whenever a variable is declared in Acus, the allocator will look for available space in the current stack-frame. From the allocator's point of view, named locals, compiler temporaries and cache slots are all typed slots inside the current frame. They differ only in who requests them and when they are released.

This allocation can always succeed in the compiler model, because Acus assumes an unbounded Brainfuck tape and therefore allows frames to grow as needed. Frame sizes are only evaluated when the program has been fully defined and algorithms are retroactively adjusted to fit the final configuration. However, slots may also be recycled to keep the frames as tightly packed as possible; this is important to reduce the number of pointer movements. To accomplish this, the management system provides the following features:

\begin{enumerate}\itemsep0em
\item Freed slots are marked \texttt{Available} and can be reused.
\item Declarations can be scoped to reduce the lifetime of variables. Variable slots will become \texttt{Available} when the variable goes out of scope.
\item Temporary slots declared by the compiler are freed immediately after use.
\item Adjacent \texttt{Available} slots are merged to accommodate larger data types.
\item \texttt{Available} slots will split into smaller parts when a variable with a size smaller than that of the slot is allocated to it.
\end{enumerate}

\subsection{Relative Offsets}
The memory management system assigns each slot an offset relative to the start of its stack-frame. Absolute tape positions are not known at compile-time, because the same function frame may appear at different runtime locations on the tape. The compiler only needs to know the layout of one frame; generated movement algorithms are later adjusted to the final frame size.

\subsection{Free vs Clear}
When a slot is freed, its contents are not cleared. This means that no algorithm may assume that a newly allocated slot contains zero, even if that slot has just been created from previously available space. In particular, the \texttt{Value} fields of a slot must be treated as unknown until explicitly initialized. Freeing a slot is therefore purely a compiler-side bookkeeping operation and does not incur any runtime cost.

\subsection{Heap Allocation}
While technically possible, Acus does not support heap allocation. This would require a separate heap frame and a runtime system that keeps track of the memory layout in that frame (including deallocation, block splitting and block merging). The runtime overhead that would arise from managing the heap at runtime would be so costly that it was decided not to implement this as a feature. However, a front-end might emulate heap allocation using the global frame. One could certainly write algorithms on top of Acus to reserve a specific amount of raw data in the global frame and manage it using existing features.

\section{Splitting and Merging}
\subsection{Slot Splitting}
When a variable of type \texttt{T} is allocated, Acus looks for the first slot that is marked \texttt{Available} and is of size $\ge$ the size of \texttt{T} (first fit strategy, \cite{firstfit}). If the sizes match perfectly, the process ends here. If the available slot's size exceeds the variable size, the remaining part of the slot is split off into its own available slot (Figure \ref{fig:splitting}). If no available slots can be found at all, a new slot is allocated at the end of the current frame (increasing the eventual frame-size).

 \begin{figure}[H]
  \centering
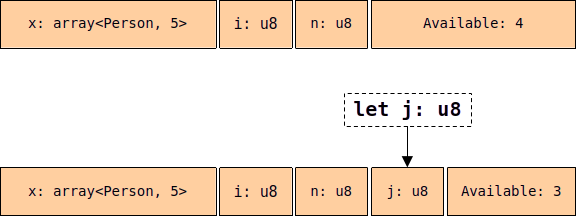
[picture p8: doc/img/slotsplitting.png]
  
  \caption{Available slots are split when a smaller variable is allocated to them.}
  \label{fig:splitting}
\end{figure}

\subsection{Slot Merging}
Named local variables live until the end of their lexical scope. Temporaries usually live only for the duration of one generated algorithm. Cache slots live until their cache entries are flushed, invalidated, or discarded at a boundary. All three are returned to the same pool of available slots. In each of these scenarios, the slot is marked \texttt{Available} by the memory management system and can be used to accommodate other data. Often, this will result in adjacent \texttt{Available} slots, which can be merged as shown in Figure \ref{fig:merging}.

\begin{figure}[H]
  \centering
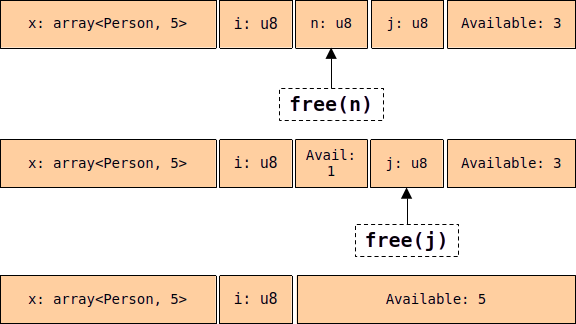
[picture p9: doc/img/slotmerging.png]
  
  \caption{Adjacent available slots are merged.}
  \label{fig:merging}
\end{figure}

\chapter{Code Generation}
\label{sec:compilation:codegen}
Before discussing larger compiler structures such as caching and dynamic access, it is useful to look at the small Brainfuck idioms from which Acus builds its generated code. Many of the algorithms in this chapter are simple in isolation, but together they form the vocabulary used to express higher-level operations on the tape. Moving or copying values, constructing constants or adding numbers together are all small patterns that appear repeatedly in the generated output.

This chapter is therefore not meant to be a complete catalogue of every algorithm implemented by Acus. Instead, it presents a representative selection: the basic destructive operations that make Brainfuck programming work, a few arithmetic operations, and the dynamic pointer-movement techniques that are most specific to compiling higher-level code to Brainfuck. 

\section{Clearing, Moving and Copying Values}
\label{sec:compilation:movecopy}
One of the simplest useful BF idioms is destructive movement: consume one cell while adding its value somewhere else. From that, one can build addition and non-destructive copying by introducing temporary storage. Basically all other algorithms rely on repeated applications of these idioms.

\subsection{Clearing Cells}
A cell can be cleared simply by moving the pointer onto it and repeatedly decrementing its value until it becomes zero: \texttt{[-]}. If the value is known to be larger than 128, \texttt{[+]} may be faster at runtime, since the cell reaches zero by overflowing rather than by decrementing all the way down.

\subsection{Moving Data}
The contents of a cell can be moved to another by decrementing its contents while incrementing that of the other. For example, to move the contents of cell \texttt{x} into cell \texttt{y} (leaving \texttt{x} empty):

\vspace{0.5cm}\noindent\begin{minipage}{\textwidth}
\begin{lstlisting}[style=brainfuck]
  # MOVE(x, y)
  y[-]
  x[- y+ x]
\end{lstlisting}
\end{minipage}

\subsection{Copying Data}
When the contents of a cell must be copied rather than moved, we need a temporary cell. The value stored in \texttt{x} is then simultaneously moved into both \texttt{y} and the temporary scratch cell \texttt{s}. When the move completes, \texttt{s} is moved back into \texttt{x} to restore its value. The scratch cell \texttt{s} is assumed to be zero before and after the operation.

\vspace{0.5cm}\noindent\begin{minipage}{\textwidth}
\begin{lstlisting}[style=brainfuck]
  # COPY(x, y)
  # Assumes s is an empty scratch cell
  
  y[-]
  x[- y+ s+ x]
  s[- x+ s]
\end{lstlisting}
\end{minipage}

\section{Constant Factories}
\label{sec:compilation:constants}
Constructing known values is fundamental to creating meaningful programs. Even a simple \emph{Hello World} requires the compiler to construct those characters somewhere in memory. The simplest and most naive way of setting a BF cell to some known value, e.g. \texttt{n}, is to concatenate \texttt{n} plus-commands. For example, the expression \texttt{x = 20} can be compiled to:
\begin{lstlisting}[style=brainfuck]
  # SET(x, 20)
  x [-] ++++++++++ ++++++++++ # 23 characters + initial move sequence
\end{lstlisting}
Notice that the cell containing \texttt{x} is first cleared using \texttt{[-]}, since we generally cannot assume that it already contains zero (even if it was freshly allocated). This particular example adds 23 characters to the generated BF output (excluding the initial move); larger values obviously produce more characters. The number of characters needed to set a cell to some constant value $c$ is simply:
\begin{align}
  N_1(x\leftarrow c) = 3 + c + m(x)
  \label{eq:n1}
\end{align}
where $m(x)$ is the number of move-commands necessary to reach the slot of \texttt{x} from the current pointer position.

To reduce code-size, we can use a scratch-cell to implement a multiplication of two smaller numbers instead. For example, instead of a series of 20 plus-commands, we can have the compiler multiply 4 and 5 to get the same result at the expense of having to use a scratch-cell \texttt{s}. Since scratch cells are allocated in a known-zero state and restored to zero after use, there is no need to clear \texttt{s} before this sequence.

\vspace{0.5cm}\noindent\begin{minipage}{\linewidth}
\begin{lstlisting}[style=brainfuck]
  # SET(x, 20)
  # Assumes s is an empty scratch cell
  
  x [-]         
  s ++++ [      
    x +++++     
    s -        
  ]
\end{lstlisting}
\end{minipage}
%
Instead of 23 characters, this algorithm adds only 15 non-movement characters to the program. In general, when $c$ can be factored into $a$ and $b$, the number of BF characters necessary to construct this value is:
\begin{align}
  N_2(x\leftarrow ab, s) = 6 + a + b + m(x) + 3m(x, s)
  \label{eq:n2}
\end{align}
where $m(x,s)$ is the number of move-commands necessary to move between the scratch-cell \texttt{s} and the target cell \texttt{x}. This value depends on the exact layout of a macro-cell but can be as low as 2 when the scratch-fields are right next to the value-fields. In the case where $m(x,s)=2$, the difference between both methods for this specific example is
\begin{align}
  N_1 - N_2 &= 3 + 20 + m(x) - (6 + 4 + 5 + m(x) + 3\cdot 2) \\
            &= 23 - 21 = 2.
\end{align}
In this small example the saving is only two characters, while the runtime cost increases because the generated loop must be executed. Luckily the benefit from the second method increases along with the value of $c$. Acus has a precomputed table of factors for all numbers up to 128 (listed in Appendix \ref{sec:appendix:factorytable}). Larger values can be reached by decrementing using the minus command to come down from 255 rather than up from 0 (BF cells wrap around after being decremented beyond 0). Each factorization $a\times b$ is chosen in such a way that it minimizes the sum $a+b$ (and consequently the number of output characters). In some cases (e.g. when $c$ itself is prime), it is better to factor a number close to $c$ and correct for the difference after doing the multiplication. For example, the optimal way to construct the value 31 is to first construct 30, then add 1, i.e. $31 = 5\times6 + 1$ for a total cost of 24 characters (as opposed to 34) for a gain of 10 characters per construction. Figure \ref{fig:constants} shows the number of characters generated for every constant up to 128 (the graph would be symmetric around this number when going from 129 to 255), for both methods. Acus implements both the naive and factorizing method and picks whichever produces the least amount of code.

\begin{figure}[H]
  \centering
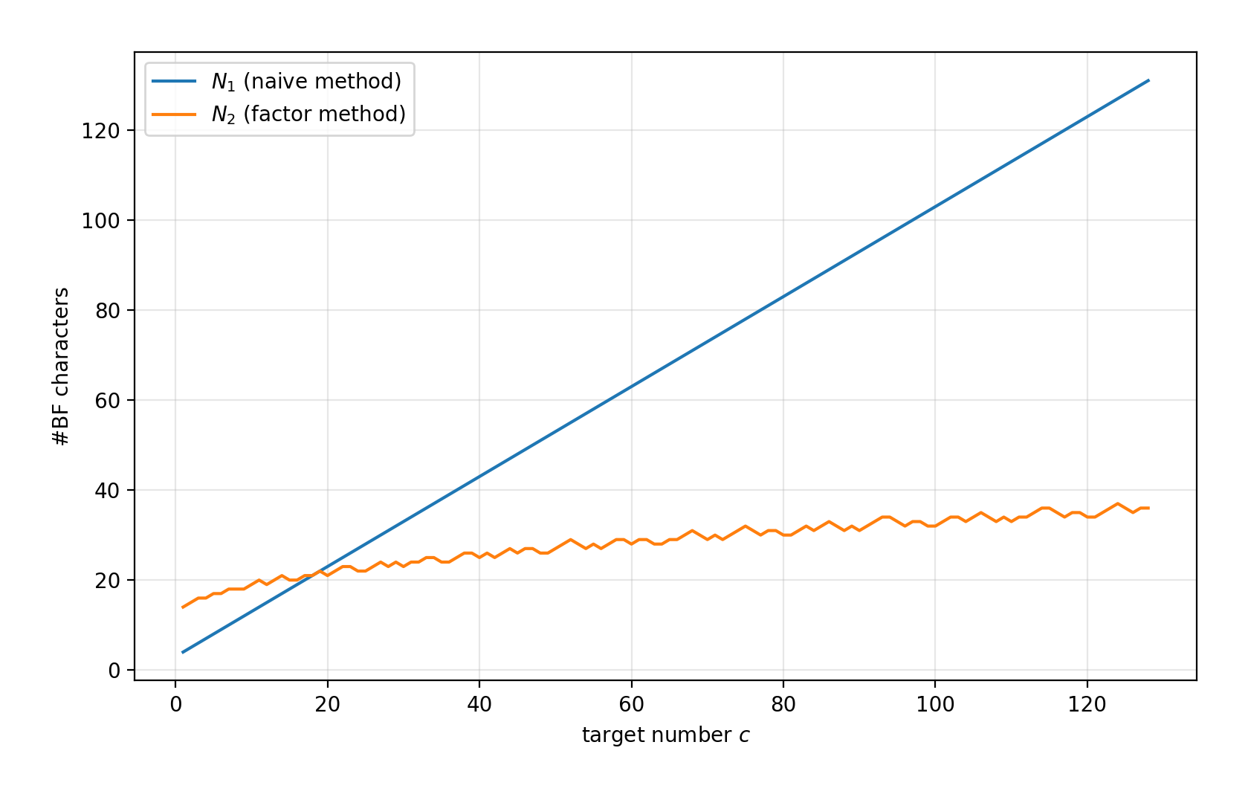
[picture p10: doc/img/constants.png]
  
  \caption{Cost of generating constants for both methods, expressed as the number of generated BF characters, as a function of their values. The common term $m(x)$ from equations \ref{eq:n1} and \ref{eq:n2} is set to zero for the purpose of this comparison.}
  \label{fig:constants}
\end{figure}

\section{Addition and Subtraction}
\label{sec:compilation:arithmetic}
\subsection{Addition (8-bit)}
\label{sec:compilation:add8}
The algorithm for addition is much like that of copying, the difference being that the target cell is never cleared in advance. When the right-hand side (rhs) of an expression of the form \texttt{x += y} may be destroyed, the algorithm is very short and efficient:

\vspace{0.5cm}\noindent\begin{minipage}{\linewidth}
\begin{lstlisting}[style=brainfuck]
  # DESTR_ADD_TO(x, y)
  y[- x+ y]
\end{lstlisting}
\end{minipage}
%
The non-destructive version requires a scratch cell to hold a copy of the rhs operand, which can then be destroyed in the process.

\vspace{0.5cm}\noindent\begin{minipage}{\linewidth}
\begin{lstlisting}[style=brainfuck]
  # ADD_TO(x, y), preserving y
  # Assumes s is an empty scratch cell
  
  COPY(y, s)
  DESTR_ADD_TO(x, s)
\end{lstlisting}
\end{minipage}

\subsection{Addition (16-bit)}
\label{sec:compilation:add16}
Adding 16-bit numbers together is much more involved and no BF pseudocode will be listed for this reason. Instead the higher-level pseudocode of Listing \ref{lst:16bitadd} illustrates the process. First, the low bytes are added together as usual. If the resulting value is less than its original value, this means that the cell has overflowed and we need to carry a 1 to the high byte. This requires multiple scratch-cells to hold temporary copies and helpers. Moreover, we need to be able to do a less-than comparison and branch on the result to carry if necessary. The implementation of this operator is discussed below in Section \ref{sec:compilation:less}.

\begin{lstfloat}[H]
\begin{lstlisting}[style=pseudocode]
  # 16-bit version of x += y
  xLowBefore = low(x)
  low(x) += low(y)          # normal 8-bit add
  if low(x) < xLowBefore:
    high(x) += 1            # carry on overflow
  high(x) += high(y)        # normal 8-bit add
\end{lstlisting}
\caption{High-level pseudocode for 16-bit addition with carry propagation.}
\label{lst:16bitadd}
\end{lstfloat}

\subsection{Subtraction}
\label{sec:compilation:subtraction}
The subtraction algorithms are symmetric to the ones for addition, where increments are substituted for decrement operations and instead of checking for overflow, we check for underflow in the 16-bit case (i.e. whether the result has grown after doing the 8-bit subtraction on the low byte).

\subsection{Signed Integers}
\label{sec:compilation:signedintegers}
For signed integers, no special algorithms have to be used at all. Since signedness is encoded using two's complement representation, addition and subtraction already work out of the box. Signedness becomes more important for comparisons, where the same bit pattern may represent a different ordering depending on how it is interpreted (as signed or unsigned).

\section{Multiplication and Division}
\label{sec:compilation:muldiv}
\subsection{Multiplication (8-bit)}\label{sec:compilation:mul8} Multiplication can be implemented in terms of repeated addition, much like we already did in the constant factory optimization. To evaluate the expression \texttt{x *= y}, we do the following:
\begin{enumerate}
\item Make a copy of the operand \texttt{x}.
\item Clear \texttt{x}.
\item Repeatedly decrease \texttt{y} while adding the original value of \texttt{x}, stored in the copy, to \texttt{x} itself.
\end{enumerate}
The steps above are the generalized version of the algorithm, which can be optimized further for edge cases where \texttt{y = 0}, \texttt{y = 1} or even for powers of 2.

\vspace{0.5cm}\noindent\begin{minipage}{\linewidth}
\begin{lstlisting}[style=brainfuck]
  # DESTR_MUL_BY(x, y)
  # Assumes s is an empty scratch cell
  
  COPY(x, s)
  x [-]
  y [-
    ADD_TO(x, s)
  ]
\end{lstlisting}
\end{minipage}
%
Like before, this algorithm destroys the rhs operand in the process. A non-destructive version can be written in terms of the destructive version:

\vspace{0.5cm}\noindent\begin{minipage}{\linewidth}
\begin{lstlisting}[style=brainfuck]
  # MUL_BY(x, y)
  # Assumes s is an empty scratch cell
  
  COPY(y, s)
  DESTR_MUL_BY(x, s)
\end{lstlisting}
\end{minipage}

\subsection{Multiplication (16-bit)}\label{sec:compilation:mul16} A naive 16-bit algorithm can simply follow the exact same procedure by relying on 16-bit addition. However, this leads to a lot of additions for large factors, which can slow down the runtime significantly. Instead, we can perform a small series of 8-bit multiplications and additions to get the same result, realizing that the 16-bit number is stored as a 2-digit base-256 number. That is, every 16-bit integer $x$ can be written as
%
\begin{align}
  x = x_0 + 256\cdot x_1,
\end{align}
%
where $x_0$ and $x_1$ are the low and high bytes of $x$ respectively. Multiplication then becomes:
%
\begin{align}
  z = x \times y &= (x_0 + 256x_1)(y_0 + 256y_1) \\
                 &= x_0y_0 + 256\cdot(x_1y_0 + x_0y_1) + 256^2\cdot(x_1y_1)
\end{align}
%
The final term only contributes to bits beyond the lowest 16 bits, so it can be discarded when the result is stored as a 16-bit value. This means that the low and high byte of the product $z$ can be expressed as
%
\begin{align}
z_0 &= x_0 y_0 \bmod 256 \\
z_1 &= \left(x_0 y_1 + x_1 y_0 + \left\lfloor \frac{x_0 y_0}{256} \right\rfloor \right) \bmod 256 
\end{align}
%
Therefore, the 16-bit product can be computed using three 8-bit multiplications. The low byte of the result comes from the low byte of $x_0y_0$, while the high byte receives the carry from this product together with the low bytes of the two cross-products.

\vspace{0.5cm}\noindent\begin{minipage}{\linewidth}
\begin{lstlisting}[style=pseudocode]
  p0 = low(x)  * low(y)
  p1 = low(x)  * high(y)
  p2 = high(x) * low(y)

  low(z)  = low(p0)
  high(z) = low(p1 + p2 + high(p0))
\end{lstlisting}
\end{minipage}

\subsection{Division (8-bit and 16-bit)}
\label{sec:compilation:division}
Unsigned division is implemented using repeated subtraction. Given two values \texttt{x} and nonzero \texttt{y}, the goal is to compute a quotient \texttt{q} and remainder \texttt{r} such that
%
\begin{align}
x = qy + r, \qquad 0 \leq r < y.
\end{align}
%
The simplest way to do this is to repeatedly subtract \texttt{y} from a running remainder until doing so would make it negative. The number of successful subtractions is the quotient, while the value left behind is the remainder.

For 8-bit unsigned values, this can be expressed by first copying the dividend into \texttt{r} and clearing \texttt{q}. Then, as long as \texttt{r} is greater than or equal to the divisor, the divisor is subtracted from \texttt{r} and \texttt{q} is incremented. In high-level pseudocode:

\vspace{0.5cm}\noindent\begin{minipage}{\linewidth}
\begin{lstlisting}[style=pseudocode]
  # unsigned 8-bit division: x / y
  q = 0
  r = x

  while r >= y:
    r -= y
    q += 1
\end{lstlisting}
\end{minipage}

The actual BF implementation cannot test \texttt{r >= y} directly. Instead, this comparison is implemented using scratch cells: temporary copies of \texttt{r} and \texttt{y} are decremented together until one of them reaches zero. If the copy of \texttt{y} reaches zero first or at the same time as \texttt{r}, the subtraction is safe and the loop may continue. If the copy of \texttt{r} reaches zero first, the next subtraction would underflow and the algorithm terminates. The original values must either be preserved during this test or reconstructed afterwards, which makes division considerably more expensive than addition or multiplication.

The same idea also applies to 16-bit unsigned division. The quotient is repeatedly incremented while the divisor is subtracted from a 16-bit remainder. The only difference is that the comparison and subtraction are now multi-byte operations, using the borrow and comparison mechanisms described earlier. This makes the algorithm correct but relatively slow for large quotients, since the number of loop iterations is proportional to the resulting quotient.

The generated implementation handles a zero divisor separately according to the rules in Section \ref{sec:compilation:divby0}.

\subsection{Signed Multiplication and Division}
\label{sec:compilation:signedmuldiv}
Signed multiplication and division are implemented as thin layers around the corresponding unsigned algorithms. First, the sign bit of the left-hand side is inspected. If it is set, the value is negated in place and a temporary flag is set to indicate that the final result should be negative. The right-hand side is copied into temporary storage before its sign is inspected, so the original divisor or multiplier does not have to be modified. If this copy is negative, it is negated as well and the result-sign flag is toggled. At this point, both operands have been converted to positive values, while the temporary flag records whether the original operands had opposite signs.

The actual multiplication or division can then be performed using the unsigned algorithm. After this operation has completed, the result-sign flag is checked. If it is set, the result is negated back into two's complement form. This approach avoids having to implement separate signed versions of the core multiplication and division algorithms; signedness is handled only by pre-processing the operands and post-processing the result.

When division also produces a remainder, Acus follows the same convention as C++ integer division: the quotient is truncated toward zero and the remainder has the same sign as the dividend. In other words, for \texttt{x / y} and \texttt{x \% y}, the generated code preserves the relation
%
\begin{align}
  x = (x / y)\cdot y + (x\%y),
\end{align}
%
where \texttt{x \% y} follows the sign of \texttt{x}. This convention was chosen because it is familiar from C++ and maps naturally onto the implementation: expressions evaluated at compile-time (constant-folding) using the C++ \texttt{\%} operator will therefore produce the same result as the runtime.

\subsection{Division by Zero}\label{sec:compilation:divby0}
To deal with division by zero, Acus will simply fill the result with the maximum value allowed by the width of the type: 255 for \texttt{u8} or 65535 for \texttt{u16} unsigned integers. For signed integers, the same bit-representation will be used, resulting in (a somewhat confusing) value of -1. The exception to this rule is when the numerator is 0 as well, in which case the result will become 0. Modulo operations where the denominator is 0 will always result in a value of 0.

\section{Boolean Operations}
\label{sec:compilation:logic}
All of the usual logic and comparison operators have been implemented in Acus, which allow the programmer to build complex logical expressions. Some of these logical building blocks will be explained below.

\subsection{Conversion to Bool}
\label{sec:compilation:boolconversion}
The simplest boolean conversion is one where an integer is transformed into either a 0 or 1, depending on its truth-value (any non-zero is considered \emph{true}). To accomplish this, the value of the operand \texttt{x} is moved into a scratch cell, leaving \texttt{x} empty. We then branch off the value of \texttt{s}: if non-zero, \texttt{x} is set back to 1. If the conditional block is not entered, \texttt{x} remains 0.

\vspace{0.5cm}\noindent\begin{minipage}{\linewidth}
\begin{lstlisting}[style=brainfuck]
  # BOOL(x)
  # Assumes s is an empty scratch cell
  
  MOVE(x, s)
  s [[-] x+ s]
\end{lstlisting}
\end{minipage}

\subsection{Logical Not}
\label{sec:compilation:logicalnot}
The not-operator does the exact opposite of a boolean conversion. It transforms its operand into 1 when its value equals 0 and vice versa for any non-zero values. The algorithm is almost identical to that of \texttt{BOOL(x)}: instead of setting \texttt{x} to 0 and incrementing it in the loop-block, we set it to 1 and decrement it inside the loop.

\vspace{0.5cm}\noindent\begin{minipage}{\linewidth}
\begin{lstlisting}[style=brainfuck]
  # NOT(x)
  # Assumes s is an empty scratch cell
  
  MOVE(x, s)
  x +
  s [[-] x- s]
\end{lstlisting}
\end{minipage}

\subsection{Logical And}
\label{sec:compilation:logicaland}
The \texttt{AND} operator is implemented using a nested BF-loop block. The operands are used to decide if those blocks should be entered. The result is then set in the inner loop, which can only be reached if both operands evaluate to \emph{true}.

\vspace{0.5cm}\noindent\begin{minipage}{\linewidth}
\begin{lstlisting}[style=brainfuck]
  # DESTR_AND(x, y)
  # Assumes s is an empty scratch cell

  MOVE(x, s)
  s [[-]
    y [[-] x+ y]
    s
  ]
\end{lstlisting}
\end{minipage}
%
Note that the algorithm above destroys the contents of \texttt{y} and replaces the original value of \texttt{x} by the result of the operation. A non-destructive version can be implemented simply by letting the destructive version operate on copies of the operands.

\subsection{Logical Or}
\label{sec:compilation:logicalor}
If we compare the logical \texttt{AND} algorithm to two switches wired in series, where current can only flow if both switches are turned on, the \texttt{OR} algorithm is its parallel counterpart. Each of the operands guards a loop and if either one of them is entered, the result is set to \emph{true}.

\vspace{0.5cm}\noindent\begin{minipage}{\linewidth}
\begin{lstlisting}[style=brainfuck]
  # DESTR_OR(x, y)
  # Assumes s is an empty scratch cell
  
  MOVE(x, s)
  s [[-]
    x+
    s
  ]
  y [[-]
    x[-]+
    y
  ]
\end{lstlisting}
\end{minipage}
%
Again, this algorithm destroys the rhs of the expression but this is easily managed by operating on a copy if necessary. Note as well that in the second loop, \texttt{x} has to be reduced to 0 first in case the first branch was entered as well (a short-circuiting algorithm would only increase the complexity and runtime rather than cutting down on it).

\subsection{Equality}
\label{sec:compilation:equality}
In testing for equality, we rely on the fact that $x-y=0$ when $x=y$ to implement a routine that calculates \texttt{NOT(x - y)}.

\vspace{0.5cm}\noindent\begin{minipage}{\linewidth}
\begin{lstlisting}[style=brainfuck]
  # EQ(x, y)
  
  SUB_FROM(x, y)
  NOT(x)
\end{lstlisting}
\end{minipage}

\subsection{Less Than}
\label{sec:compilation:less}
This operator was already used before in the implementation of 16-bit addition, to determine the value of the carry-bit. It is implemented by reducing both of its operands simultaneously, until either one of them reaches zero. If the rhs is still non-zero when this happens, the lhs must have been the smaller of the two. This turns out to be a pretty tedious algorithm when expressed in BF, so instead it is presented in pseudocode below. Other comparison operators are implemented similarly.

\vspace{0.5cm}\noindent\begin{minipage}{\linewidth}
\begin{lstlisting}[style=pseudocode]
  # LT(x, y)

  while x AND y:
    --x
    --y

  x = NOT(y)
\end{lstlisting}
\end{minipage}

\subsection{Signed Comparisons}
\label{sec:compilation:signedcomparisons}
Comparisons on signed integers cannot use the unsigned implementations discussed before. Instead, the exact form of the algorithm depends on the sign bits of both arguments. A runtime check has to be done to determine which one of four branches must be taken. For example, for the less-than operator, if its operands are both signed:

\begin{enumerate}
\item If both are nonnegative, use the unsigned algorithm.
\item If the lhs is negative and the rhs is positive (or zero), return 1 immediately.
\item If the lhs is nonnegative and the rhs is negative, return 0 immediately.
\item If both are negative, use the unsigned greater-than algorithm on their absolute values.
\end{enumerate}

This requires an algorithm to evaluate the sign of an integer and one to take its absolute value. To get the sign bit of an 8-bit value $x$ (1 if negative, 0 otherwise), we simply compute the result of $x >= 128$ (using the unsigned greater-equal operator). Values with bit patterns identical to unsigned values from 128 on are interpreted as negative numbers (i.e. have their highest bit set) in two's complement representation.

To calculate the absolute value of a signed integer, its sign bit is first calculated. If not set, the value can remain unmodified since it is already positive. If the sign bit \emph{is} set, it can be negated simply by subtracting it from 0.

\vspace{0.5cm}\noindent\begin{minipage}{\linewidth}
\begin{lstlisting}[style=pseudocode]
  # ABS(x)
  # Assumes s to be an empty scratch-cell

  if SIGN_BIT(x):
    # x = 0 - x
    SUB_FROM(s, x)
    MOVE(s, x)
\end{lstlisting}
\end{minipage}

\section{Pointer Movement}
\label{sec:compilation:pointers}
BF has no random memory access instruction; the only way to reach a cell is to move the data-pointer (simply referred to as the \emph{pointer} from now on) step by step, which requires the compiler to keep track of the pointer at all times. This poses a challenge for situations where the pointer has to move dynamically, i.e.~to tape-locations not known at compile-time. This occurs for example when dereferencing pointers or when interacting with runtime indices into arrays.

\subsection{Static Pointer Movement}
\label{sec:compilation:staticmove}
In most scenarios, when the source and destination locations are known at compile time, pointer movement is straightforward: emit the required number of \texttt{<} or \texttt{>} commands. This is the common case for local slot operations within a frame, where the compiler can keep track of the current pointer position relative to the frame origin.

\subsection{Dynamic Pointer Movement}
\label{sec:compilation:dynamicmove}
The most interesting pointer-movement algorithms are the ones where the target is not known until runtime. Examples include array access by a runtime index and pointer dereferencing. These algorithms rely on metadata stored in macro-cells: markers, counters and payload fields are used so that the BF pointer can search through structured tape data and stop at the correct logical cell. We can distinguish between two different classes of dynamic pointer movement: \emph{marker-based} and \emph{offset-based} moves. In marker-based moves, the pointer moves along the tape until it hits some pre-set marker. In offset-based moves, the offset is stored in the payload cells and dragged along with the pointer while being reduced; when the payload becomes zero, the destination has been reached.

\subsubsection{Marker-Based}
\label{sec:compilation:dynamicmove:marker}
This method relies on a marker-field, the \texttt{FrameMarker} or \texttt{SeekMarker}, being set beforehand. We can then move the pointer into the corresponding field of the current cell and move in some direction until the marker is hit.

\vspace{0.5cm}\noindent\begin{minipage}{\linewidth}
\begin{lstlisting}[style=brainfuck]
  # SEEK_LEFT()
  # Assumes s to be an empty scratch-field

  COPY(SeekMarker, s)
  NOT(s)
  s [[-]
    <<<<<<<<<            # skip to left-adjacent macro-cell
    COPY(SeekMarker, s)
    NOT(s)
    s
  ]
\end{lstlisting}
\end{minipage}

Because the pointer ends up at some unknown location, we commonly set another marker that can be used to bring the pointer back afterwards.

\subsubsection{Offset-Based}
\label{sec:compilation:dynamicmove:offset}
The second class of dynamic pointer movement relies on a runtime value representing the offset being stored on the tape itself. For example, in the expression \texttt{x[i]}, \texttt{i} is a variable stored on the tape that contains the element index with respect to the start of the array \texttt{x}. This index is converted into a macro-cell offset based on the size of the element type. To reach a specific offset, the pointer is moved to the start of the array (known at compile-time) and the offset-value is copied or moved into its payload-fields (a single one for 8-bit values and both of them for 16-bit values). The pointer is then moved to the right while the payload is moved along and decremented. When the payload hits zero, the required offset has been reached.

\vspace{0.5cm}\noindent\begin{minipage}{\linewidth}
\begin{lstlisting}[style=brainfuck]
  # TO_OFFSET(b, i)
  # b = base address
  # i = macro-cell offset wrt base

  COPY(i, b.payload)
  b.payload [-
    MOVE(b.payload, 9)    # move payload one macro-cell to the right
    >>>>>>>>>             # follow with data-pointer
  ]
  # Pointer now points at the (empty) payload field of the target-element.
\end{lstlisting}
\end{minipage}

Note that, depending on the element-type of the array, the index does not always equal the actual offset in terms of the number of macro-cells. Some preprocessing needs to be done on arrays of type \texttt{T} when \texttt{sizeof(T)} is larger than 1, by multiplying the index by that size to get the actual offset.

\subsection{Payload Transport}
\label{sec:compilation:payloadtransport}
Dynamic writes are harder than dynamic reads because data has to be carried to a location that is not statically known. Acus solves this by moving values through designated payload fields. The payload travels along with the dynamic traversal and is deposited when the target macro-cell is found.

For marker-based movements, the payload can simply be moved along with the pointer because the payload fields are not used to perform the move itself. For offset-based movements, the payload fields already serve the purpose of containing the offset itself and cannot be used to transport the new value. Instead, the usual offset-based method described in Section \ref{sec:compilation:dynamicmove:offset} is used to find the element, where a marker is planted. Then, the marker-based method is used to move the payload to that position and overwrite its value field(s).

\chapter{Caching} \label{sec:compilation:cache}
Slot proxies (Section \ref{sec:compilation:slotproxies}) allow expressions to remain abstract until their value is needed. However, repeatedly materializing the same proxy can duplicate work. For example, accessing the same array element several times in a block should not require materializing the element locally each time. Instead, multiple accesses can be cached and a writeback occurs only when necessary, for example at control-flow boundaries.

\vspace{0.5cm}\noindent\begin{minipage}{\textwidth}
\begin{lstlisting}[style=pseudocode]
  let x: array<u8, 5>
  let i: u8
  ...

  let y: u8 = x[i]  # materializes x[i] in a local cache before assigning to y
  x[i] = 42         # operates on the same cached value and marks it dirty
  x[i] *= 2         # operates directly on the dirty entry
  let y: u8 = f(x)  # before passing x to f(), x[i] is written
                    # back to canonical storage
\end{lstlisting}
\end{minipage}

To implement this caching system, dependencies between proxies need to be carefully maintained. During compilation, a dependency graph is built and used to determine which cache entries have become dirty and which ones need to be flushed back into their actual storage location. This chapter will go over the different techniques and compromises that were made in their implementation.

\section{Cache Graphs}\label{sec:compilation:cachegraphs}
A cache entry connects a logical proxy to a concrete slot that currently holds its materialized value. Entries can be marked dirty when modified or invalidated/removed when there is no guarantee that their values still represent the actual referred-to data.

Figure \ref{fig:cachegraph} shows a simplified representation of a cache graph, where each entry (node) contains information about the proxy that it represents, the physical location of the cached slot, and its parent and child nodes. A proxy \texttt{A} is considered a parent of proxy \texttt{B} if the canonical storage location of \texttt{B} is a subset of that of \texttt{A}. For example, given the expression \texttt{x[i][j]}, the expression \texttt{x[i]} is represented by a proxy that itself will be cached (assuming \texttt{i} is not known at compile time). Therefore, to materialize the element \texttt{x[i][j]}, we first need to materialize \texttt{x[i]}, and their cache entries are in a parent-child relation: \texttt{x[i]} is the parent of \texttt{x[i][j]} because the storage slot of \texttt{x[i]} encloses that of \texttt{x[i][j]}.

In the example of Figure \ref{fig:cachegraph}, the $3\times 3$ matrix \texttt{x} is indexed by the index variables \texttt{i}, \texttt{j}, \texttt{k} and \texttt{l} through the expressions at the top. The first line causes the left branch of the tree to be generated: in order to materialize \texttt{x[i][j]}, its parent \texttt{x[i]} is materialized in a cache slot, which can be generated from the statically known starting address of its parent \texttt{x} (which does not have to be cached). In this example, \texttt{x[i]} is materialized right after its parent \texttt{x} (as can be confirmed from the offsets and size data) but this does not necessarily have to be the case.

The second expression causes a second cache-branch to be generated because the proxies \texttt{x[i]} and \texttt{x[k]} have different proxy-identities (even though they could be referring to the same objects at runtime, when \texttt{i == k}).

\begin{figure}[H]
  \centering
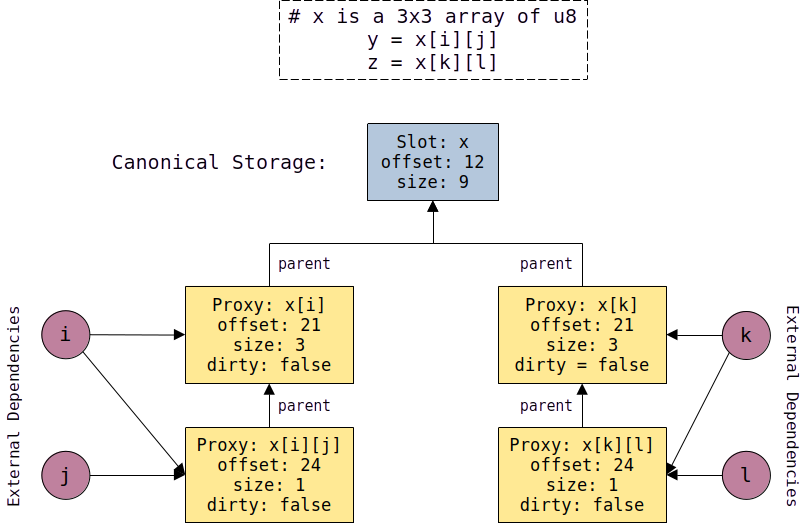
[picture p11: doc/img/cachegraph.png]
  
  \caption{Resulting cache graph after materializing \texttt{x[i][j]} and \texttt{x[k][l]}. The blue box represents the canonical slot containing \texttt{x}, whereas the yellow boxes represent cached subslots (at unknown offsets with respect to the canonical storage) that have been materialized in known locations.}
  \label{fig:cachegraph}
\end{figure}

\section{Flushing and Invalidation}
\label{sec:compilation:flushinvalidate}

\subsection{Dirty Entries}\label{sec:compilation:dirtyentries}
In the example of Figure \ref{fig:cachegraph}, all entries are \emph{clean} (i.e. not \emph{dirty}), since none of the expressions involving them modified their contents. The expression \texttt{x[i][j] = 3} would have the effect of writing the value 3 to the cache slot and marking its corresponding entry as dirty. Dirty entries must at some point be flushed into their parent to make sure that all changes applied to a cached object eventually propagate into canonical storage. 

\subsection{Flushing}\label{sec:compilation:flushing}
Flushing an entry means writing its contents back into its parent (either another cached slot or canonical storage). An entry needs to be flushed in the following scenarios:
%
\begin{enumerate}
\item The entry is marked \emph{dirty} and a parent somewhere up in the cache hierarchy is materialized. If the dirty entry is multiple parents removed, this causes all intermediate parents to be flushed as well. For example, if \texttt{x[i][j]} is dirty and \texttt{x} is materialized, the dirty \texttt{x[i][j]} is flushed into \texttt{x[i]}, which then becomes dirty and is subsequently flushed into \texttt{x} itself. The entire path from \texttt{x[i][j]} to \texttt{x} is now clean.
\item Whenever a control-flow boundary is crossed. For example, at jumps or function calls, the entire cache is cleared by flushing all entries (starting at the deepest child nodes) back into their canonical storage. This makes sure that all flow paths see the correct data.
\item Whenever a pointer is dereferenced. Because pointers can refer to anything (of some type) at runtime, the entire cache is cleared to make sure that the pointee is up-to-date when fetched by the dereferencing algorithm.
\item Before cache invalidation. In scenarios where a cache entry is invalidated (removed from the tree), it is flushed back before doing so. Cache invalidation is discussed in more detail below.
\end{enumerate}

At a return boundary, local cache entries can be discarded because their frame is about to disappear. Entries referring to storage that outlives the frame, such as globals and dereferenced pointers, must first be flushed. Return values are transferred separately by the return mechanism described earlier.

\subsection{Invalidation}\label{sec:compilation:invalidation}
Entries can be invalidated when an external dependency or (indirect) parent is modified or freed by the memory management system. In the example of Figure \ref{fig:cachegraph}, the entries \texttt{x[i]} and \texttt{x[i][j]} have been materialized in cache using the value stored in slot \texttt{i} at that time. When the value of \texttt{i} is modified, the proxy refers to a new object and the entry has become invalid. When this is about to happen, the invalidated proxy has to be flushed (if dirty) \emph{before} modifying the dependency, after which it (and its descendants) can be removed from the cache tree.

\subsection{Writes}
\label{sec:compilation:cachewrites}
Writing to a proxy will, as mentioned before, cause its cached entry to be marked \emph{dirty}. When the object is overwritten independently of its original value, there is no need to materialize that value at all. For example, when compiling the expression \texttt{x[i][j] = 3}, the value stored initially in \texttt{x[i][j]} is completely irrelevant. In such cases, a new entry for the proxy \texttt{x[i][j]} is created and marked dirty immediately and no materialization algorithm has to be executed.

\subsection{Example}\label{sec:compilation:cacheexample} The listing below shows a more complete version of code that leads to the cache hierarchy of Figure \ref{fig:cachegraph}. At the lines marked \texttt{(a)} and \texttt{(b)}, the graph from Figure \ref{fig:cachegraph} is generated. Then, at line \texttt{(c)}, a new value is assigned to \texttt{x[i][j]}. This assignment expression will write the value \texttt{3} directly to the already cached slot for the proxy \texttt{x[i][j]} and mark this entry as \emph{dirty}. At the next expression (line \texttt{(d)}), a new proxy (\texttt{x[i][k]}) is materialized, which shares a parent (\texttt{x[i]}) with the now dirty entry \texttt{x[i][j]}. Therefore, before materializing \texttt{x[i][k]}, the dirty entry is flushed upwards into \texttt{x[i]}, after which its dirty state is cleared and \texttt{x[i][k]} can be materialized. Finally, at line \texttt{(e)}, the value of \texttt{i} is modified. All cache entries that depend on \texttt{i} (the left branch of the graph) therefore need to be invalidated. In this example, these entries have just been flushed and are still clean, so there is no need to flush them prior to deletion.

\vspace{0.5cm}\noindent\begin{minipage}{\textwidth}
\begin{lstlisting}[style=pseudocode]
  using Vec3 = array<u8, 3>
  using Mat  = array<Vec3, 3>
  let x: Mat

  # Indices (not known at compile-time)
  let i: u8
  let j: u8
  let k: u8
  let l: u8
  ...

  # Materialization and caching
  let y: u8 = x[i][j]    # (a)
  let z: u8 = x[k][l]    # (b)

  # Flushing and invalidating
  x[i][j] = 3            # (c)
  let q: u8 = x[i][k]    # (d)
  i = 0                  # (e)
  ...
\end{lstlisting}
\end{minipage}

\chapter{Other Optimizations}
The caching system is one of the optimizations used by Acus to try to somewhat limit the number of generated BF instructions, which tends to grow very fast for complex programs. Even though it was never a goal to produce highly optimized BF, several other optimizations have been implemented to fight the explosive nature of the generated output. Each of these techniques will be briefly outlined in this chapter.

\section{Move Semantics}
The algorithms for moving and copying BF cells are very similar: copying means we simultaneously move to the target cell and a scratch cell, only for the scratch cell to be emptied back into the source location. Obviously, we should move and avoid the full copy algorithm whenever possible. Therefore, if we can prove that the source is expendable, we can just move its contents out of it to a new location. Acus tries to find as many opportunities as possible to move instead of copy. For example, this is possible in the following situations:
\begin{enumerate}\itemsep0em
\item Assignment from a temporary expression. e.g. \texttt{x = y + z}, where \texttt{y + z} is a temporary which does not outlive the statement anyway. 
\item Flushing cache entries that are about to be deleted. When a cache tree is flushed prior to it being deleted, we can move instead of copy towards the root.
\end{enumerate}

\section{Literal Evaluation}
\subsection{Constant Folding}
While Acus does \emph{not} implement advanced constant-expression evaluation (it does not keep track of known values of runtime variables), it \emph{will} apply constant folding to literal expressions. For example, consider the expression \texttt{3 + 4}. In a naive implementation, the compiler might need to allocate 2 temporary slots for the literal expressions \texttt{3} and \texttt{4} and call a runtime algorithm on those slots to compute the value 7. Acus will simply collapse this to the literal expression \texttt{7} without generating any runtime code.

\subsection{Specialized Constant Algorithms}
All operators come in 2 flavors: one to apply its effect to two slots and one to apply its effect to a slot paired with a constant. For example, the expressions \texttt{x * y} and \texttt{x * 8} might be evaluated differently. In the latter case, the constant can be evaluated to determine if the algorithm can be simplified or optimized. Multiplication by 0 will instantly result in the cell being zeroed out, whereas multiplication by 1 can return without any modifications at all. Similar optimizations have been implemented for other arithmetic and logical operators.
\begin{enumerate}\itemsep0em
\item Addition and subtraction by 0 result in a no-op.
\item Multiplication by 0 results in immediate 0.
\item Multiplication by 1 results in a no-op.
\item Division by 0 rules are hard-coded (see \ref{sec:compilation:divby0}).
\item Unsigned comparisons to 0 only need to check if the value is 0 (can't be less than 0 anyway).
\item Signed comparisons to 0 can use the sign-bit algorithms.
\end{enumerate}

\section{Primitive and BF Merging}
\subsection{Merging Primitives}
Before generating actual BF characters, Acus will produce a series of primitives, each of which represents a relatively simple sequence of BF instructions on a slightly higher level (Table \ref{tab:primitives}). Sequences of primitives can sometimes be merged into shorter sequences or even no-ops. For example, if the primitive \texttt{MovePointerRelative(3)} is immediately followed by the primitive \texttt{MovePointerRelative(6)}, they can be merged into a single \texttt{MovePointerRelative(9)}. This leads to a series of merge-rules, listed in Table \ref{tab:mergerules}. By applying these rules iteratively to the generated sequence of primitives, the program can be shrunk significantly in post-processing.

\begin{longtable}{T{0.30\textwidth}|L{0.62\textwidth}}
  \hline
  \normalfont\textbf{Primitive} & \textbf{Description} \\
  \hline
  \endfirsthead
  \hline
  \normalfont\textbf{Primitive} & \textbf{Description} \\
  \hline
  \endhead

  \texttt{LoopOpen} & Open a BF loop, compiles to simply \texttt{[}. \\
  \texttt{LoopClose} & Close a BF loop, compiles to simply \texttt{]}. \\
  \texttt{MovePointerRelative(x)} & Move the pointer by \texttt{x} cells (positive means to the right). \\
  \texttt{ChangeValue(c)} & Change the current value by an amount \texttt{c}. \\
  \texttt{ZeroCell} & Set the current value to \texttt{0} using \texttt{[-]}. \\
  \texttt{ZeroCellPlus} & Set the current value to \texttt{0} using \texttt{[+]}. \\
  \texttt{ConstructConstant(c)} & Construct the value \texttt{c} in the current cell. \\
  \texttt{MoveData(x)} & Move the contents of the current cell to relative position \texttt{x}. \\
  \texttt{CopyData(x)} & Copy the contents of the current cell to relative position \texttt{x}. \\
  \texttt{Add(x)} & Add the value of the cell at relative position \texttt{x} to the value of the current cell. \\
  \texttt{Subtract(x)} & Subtract the value of the cell at relative position \texttt{x} from the value of the current cell. \\
  \texttt{Boolean} & Set the current cell to its boolean value. \\
  \texttt{Not} & Set the current cell to its logical not value. \\
  \texttt{Or(x)} & Set the current value to the logical OR of this value and the value inside the cell at relative offset \texttt{x}. \\
  \texttt{And(x)} & Set the current value to the logical AND of this value and the value inside the cell at relative offset \texttt{x}. \\
  \texttt{Xor(x)} & Set the current value to the logical XOR of this value and the value inside the cell at relative offset \texttt{x}. \\
  \texttt{Equal(x)} & Set the current value to 1 if it is equal to the value in the cell at relative offset \texttt{x}, 0 otherwise. \\
  \texttt{Less(x)} & Set the current value to 1 if it is less than the value in the cell at relative offset \texttt{x}, 0 otherwise. \\
  \texttt{LessOrEqual(x)} & Set the current value to 1 if it is less than or equal to the value in the cell at relative offset \texttt{x}, 0 otherwise. \\
  \texttt{Greater(x)} & Set the current value to 1 if it is greater than the value in the cell at relative offset \texttt{x}, 0 otherwise. \\
  \texttt{GreaterOrEqual(x)} & Set the current value to 1 if it is greater than or equal to the value in the cell at relative offset \texttt{x}, 0 otherwise. \\
  \texttt{Cmp(c)} & Set the current value to 1 if it is equal to the compile-time constant \texttt{c}, 0 otherwise. \\
  \hline
  \caption{Acus primitives.}
  \label{tab:primitives}   
\end{longtable}

\begin{longtable}{R{0.27\textwidth}|L{0.27\textwidth}|Q{0.34\textwidth}}
\hline
\textbf{Primitive} & \textbf{Followed By} & \textbf{Merged Into} \\
\hline
\endfirsthead
\hline
\textbf{Primitive} & \textbf{Followed By} & \textbf{Merged Into} \\
\hline
\endhead
\endlastfoot

\texttt{ZeroCell} & \texttt{ZeroCell} & \texttt{ZeroCell} \\
\texttt{ZeroCell} & \texttt{ZeroCellPlus} & \texttt{ZeroCell} \\
\hline

\texttt{ZeroCellPlus} & \texttt{ZeroCellPlus} & \texttt{ZeroCellPlus} \\
\texttt{ZeroCellPlus} & \texttt{ZeroCell} & \texttt{ZeroCellPlus} \\
\hline

\texttt{LoopClose} & \texttt{ZeroCell} & \texttt{LoopClose} \\
\texttt{LoopClose} & \texttt{ZeroCellPlus} & \texttt{LoopClose} \\
\hline
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

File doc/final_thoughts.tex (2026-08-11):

\chapter{Reflection} \label{sec:finalthoughts}

\section{Conclusion} \label{sec:conclusion}
This project set out as a ``What if?'' for which expectations were deliberately kept low. A functional system was the goal; not a fast one. We had no idea what kinds of speeds we could expect, how stable the system would be and frankly whether we would even end up with anything functional. The only goal was simply to get something going. Given those goals, this project has certainly delivered to an unexpected extent.
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

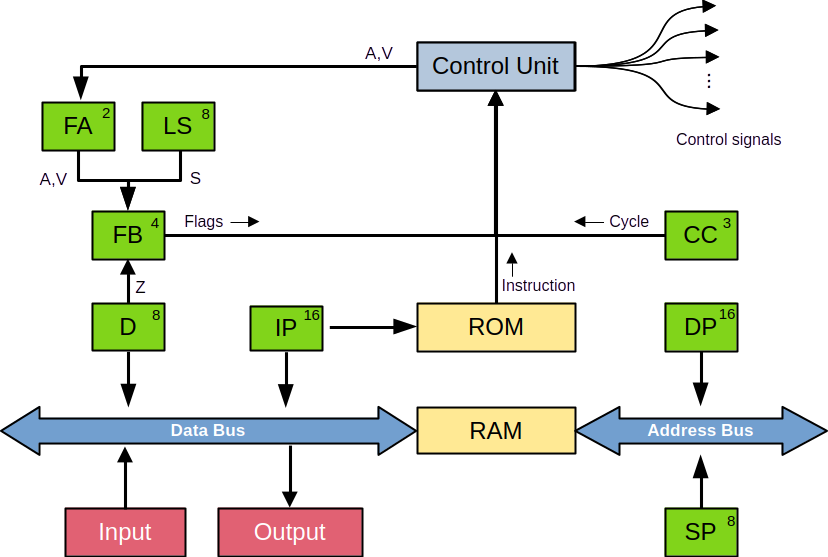
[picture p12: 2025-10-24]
doc/img/bfcpu_architecture.png

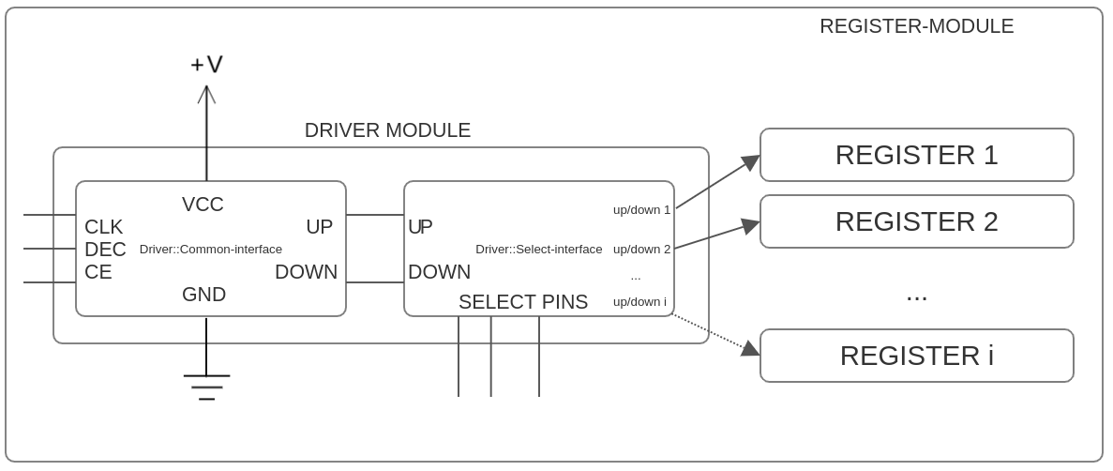
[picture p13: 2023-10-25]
doc/img/register_module_overview.png

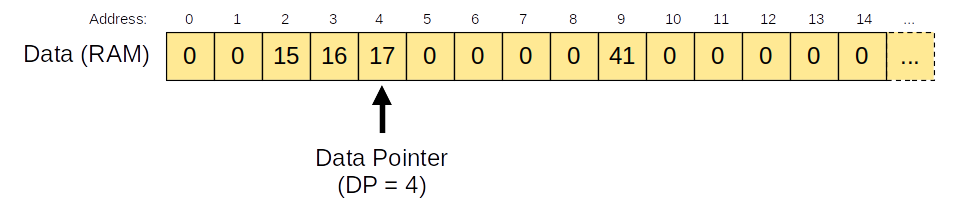
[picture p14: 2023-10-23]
doc/img/simple_representation.png

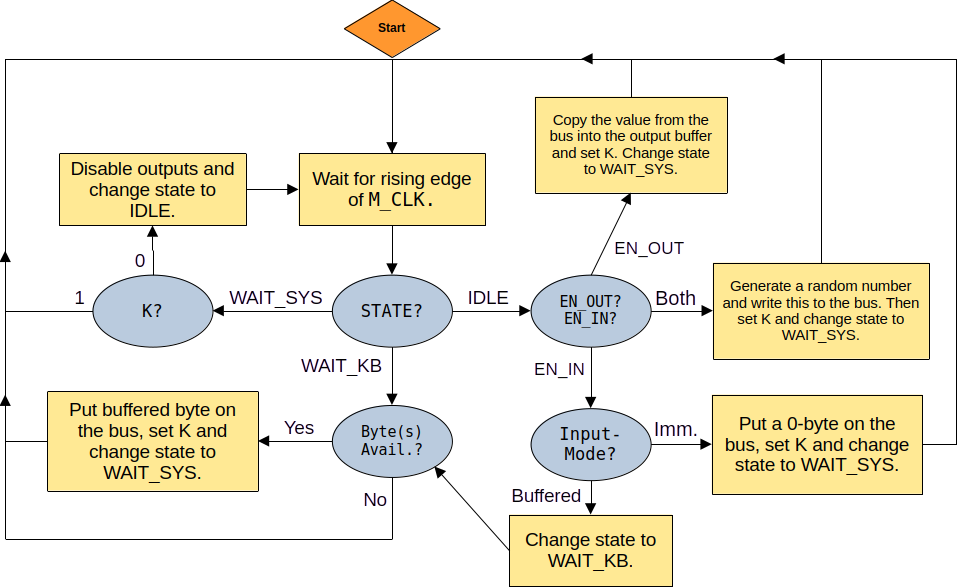
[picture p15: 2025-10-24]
doc/img/iomodule_flowchart.png

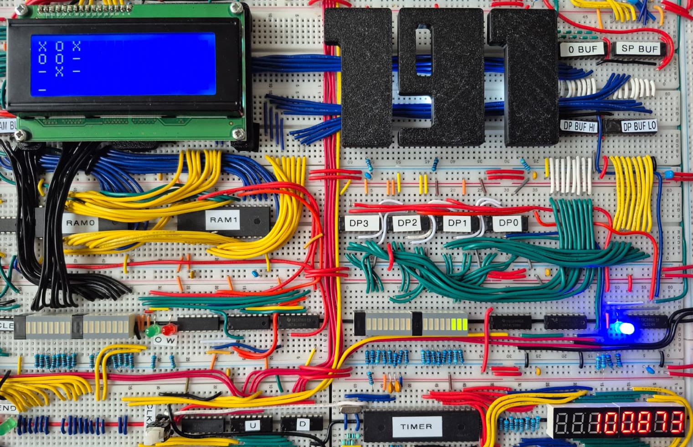
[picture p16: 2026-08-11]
doc/img/tictactoe.jpeg

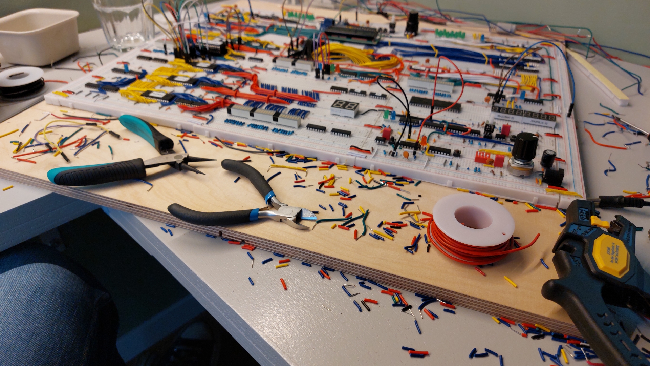
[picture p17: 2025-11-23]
doc/img/pics/IMG-20250208-WA0007.jpeg

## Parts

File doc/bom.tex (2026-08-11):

\chapter{Bill of Materials} \label{sec:bom}
The following chapter lists all components required to build the Synapse-191 computer, including
integrated circuits, passive components, and other hardware parts.  
The system was constructed entirely on solderless breadboards using standard through-hole
TTL logic and readily available electronic parts.  
Component quantities reflect the final, fully assembled configuration of the system,
including the control unit, data path, clock circuitry, and I/O modules.

Note that in several cases, alternative or suboptimal parts were used based on component
availability at the time of construction.  
These lists are therefore intended as a reference for replication and documentation purposes,
not as precise shopping lists.  
Anyone attempting to build a similar system should expect to keep a stock of spare parts and
make appropriate substitutions where necessary.

\section{Integrated Circuits}
\begin{table}[H]
  \centering
  \begin{tabular}{r|c|l}
    Part                     & Quantity & Description \\\hline
    74LS00                   & 3 & 4x NAND \\
    74LS02                   & 1 & 4x NOR \\
    74LS04                   & 6 & 6x NOT \\
    74LS08                   & 2 & 4x AND \\
    74LS14                   & 1 & 6x Schmitt-Trigger \\
    74LS32                   & 2 & 4x OR \\
    74LS48                   & 2 & 7-Segment Driver  \\
    74LS74                   & 1 & 2x D-Flip-Flop  \\
    74LS76                   & 1 & 2x JK-Flip-Flop  \\
    74LS86                   & 1 & 4x XOR  \\
    74LS123                  & 2 & 2x Monostable Multivibrator  \\
    74LS138                  & 2 & 3-to-8 Decoder  \\
    74LS157                  & 1 & 4-bit Data Selector \\
    74LS161                  & 2 & 4-Bit Counter  \\
    74LS173                  & 9 & 4-Bit Register  \\
    74LS193                  & 14 & 4-Bit U/D Counter  \\
    74LS245                  & 10 & 8-Bit Bus Transceiver  \\
    74HC595                  & 1 & 8-Bit Shift Register  \\
    MC14078B                 & 2 & 8-Input NOR  \\
    NE555                    & 4 & 555-Timer \\
    AT28C64B                 & 4 & 64-Kbit ($8\text{K}\times8$) EEPROM  \\
    AS6C4008                 & 2 & $512\text{K}\times8$ SRAM  \\
    ICM7226B                 & 1 & Frequency Timer  \\
  \end{tabular}
  \caption{ICs used in the project.}
  \label{tab:parts}
\end{table}

\section{Passive Components}

\begin{table}[H]
  \centering
  \begin{subtable}[t]{0.3\textwidth}
    \vspace{0pt}
    \begin{tabular}{r|l}
      Value                    & Quantity \\ \hline
      220 $\Omega$              & 1  \\
      330 $\Omega$              & 8  \\
      470 $\Omega$              & 80 \\
      1 $k\Omega$               & 5  \\
      2 $k\Omega$               & 1  \\
      4.7 $k\Omega$             & 10 \\
      5 $k\Omega$               & 3  \\
      10 $k\Omega$              & 5  \\
      100 $k\Omega$             & 2  \\
      220 $k\Omega$             & 1  \\
      470 $k\Omega$             & 1  \\
      10 $M\Omega$              & 2  \\
    \end{tabular}
    \caption{Resistors}
  \end{subtable}
  \hfill
  \begin{subtable}[t]{0.3\textwidth}
    \vspace{0pt}
    \begin{tabular}{r|l}
      Value                    & Quantity \\ \hline
      470 $\mu F$              & 1 \\    
      10 $\mu F$               & 1 \\    
      4.7 $\mu F$              & 1 \\    
      1 $\mu F$                & 3 \\    
      100 nF (104)             & 50\\    
      10 nF (103)              & 5 \\    
      2.2 nF (222)             & 1 \\
      1 nF (102)               & 4 \\
      470 pF (471)             & 1 \\
      220 pF (221)             & 1 \\
      100 pF (101)             & 1 \\    
      47 pF                    & 2  \\    
      22 pF                    & 2  \\    
    \end{tabular}
    \caption{Capacitors}
  \end{subtable}
  \hfill
  \begin{subtable}[t]{0.3\textwidth}
    \vspace{0pt}
    \begin{tabular}{r|l}
      Value                      & Quantity \\ \hline
      10 MHz crystal             & 1 \\    
      16 MHz crystal             & 1 \\
      10 k$\Omega$ potentiometer & 2 \\
      Toggle switch              & 2 \\
      DIP switch (x8)            & 1 \\
      Tactile button             & 5 \\
      20-22AWG wire              & ? \\
    \end{tabular}
    \caption{Other passive components}
  \end{subtable}

  \caption{Resistors, capacitors and other passive components used in the project.}
  \label{tab:rcbom}
\end{table}

\section{Other Parts}
\begin{table}[H]
  \centering
  \begin{tabular}{r|c|l}
    Part                     & Quantity & Description \\\hline
    Breadboard               & $\sim$25 & 830-hole  \\
    Single 7-Segment Display & 2 &    \\
    Quad 7-Segment Display   & 2 &    \\
    Single LED               & 15 & Various colors \\
    Bar LED strip            & 11 & 10 LEDs per strip  \\
    HD44780-Compatible LCD   & 1 & $20\times4$ characters  \\
  \end{tabular}
  \caption{Other parts used in the project.}
  \label{tab:otherparts}
\end{table}

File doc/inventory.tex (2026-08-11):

\section{Inventory} \label{sec:inventory}
For the creation of the processor we used a vast inventory of tools and elements, like resistors, LEDs, and capacitors. However, other components are, mostly, digital chips created by different manufacturers and have also been utilized. In this section, we provide the reader with an approximate list of all tools and components utilized or used during the process.

\subsection{Electronic components}
\begin{itemize}
	\item LEDs with different colors (white, yellow, red, blue, and green);
	\item Capacitors of a wide range (from 0.1~nF up to 4000~$\mu$F);
	\item Resistors of a wide range (from 10~$\Omega$ up to 1~M$\Omega$);
	\item Seven-segment displays;
	\item Ribbon cables;
	\item Diodes;
	\item Voltage sources (batteries and AC to DC converters);
	\item Arduino Uno/Nano;
	\item ESP32;
	\item NAND (00 series);
	\item NOR (02 series);
	\item NOT (04 series);
	\item AND (08 series);
	\item OR (32 series);
	\item XOR (86 series);
	\item Seven-segment display decoders (48 series);
	\item JK Flip-flops (76 series);
	\item 4-bit binary counters (74LS161);
	\item 4-bit registers (74LS173);
	\item 4-bit up/down counters (74LS193);
	\item 8-bit shift registers (595 series);
	\item 8-bit bus transceivers (245 series);
	\item 555 timers;
	\item 3-to-8 demultiplexers (138 series);
	\item Dual 4-input NAND gates (20 series);
	\item Dual 4-input AND gates (21 series);
	\item 8-to-1 multiplexers (151 series);
	\item ROM;
	\item RAM (AS6C4008);
	\item et cetera. 
\end{itemize}

\subsection{Tools and instrumentation}
\begin{itemize}
	\item wire cutters;
	\item pliers;
	\item multimeters;
	\item oscilloscope;
	\item probes;
	\item soldering iron;
	\item et cetera.
\end{itemize}

\subsection{Digital tools}
\begin{itemize}
	\item Linux (Fedora);
	\item Emacs;
	\item Logisim;
	\item Inkscape;
	\item TeXstudio;
	\item Git/GitHub;
	\item Visual Studio Code;
	\item C++ compilers (g++), C++ build tools (CMake);
	\item et cetera.
\end{itemize}

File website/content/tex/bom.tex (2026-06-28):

\chapter{Bill of Materials} \label{sec:bom}
The following section lists all components required to build the Synapse-191 computer, including
integrated circuits, passive components, and other hardware parts.  
The system was constructed entirely on solderless breadboards using standard through-hole
TTL logic and readily available electronic parts.  
Component quantities reflect the final, fully assembled configuration of the system,
including the control unit, data path, clock circuitry, and I/O modules.

Note that in several cases, alternative or suboptimal parts were used based on component
availability at the time of construction.  
These lists are therefore intended as a reference for replication and documentation purposes,
not as precise shopping lists.  
Anyone attempting to build a similar system should expect to keep a stock of spare parts and
make appropriate substitutions where necessary.

\section{Integrated Circuits}
\begin{table}[H]
  \centering
  \begin{tabular}{r|c|l}
    Part                     & Quantity & Description \\\hline
    74LS00                   & 3 & 4x NAND \\
    74LS02                   & 1 & 4x NOR \\
    74LS04                   & 6 & 6x NOT \\
    74LS08                   & 2 & 4x AND \\
    74LS14                   & 1 & 6x Schmitt-Trigger \\
    74LS32                   & 2 & 4x OR \\
    74LS48                   & 2 & 7-Segment Driver  \\
    74LS74                   & 1 & 2x D-Flip-Flop  \\
    74LS76                   & 1 & 2x JK-Flip-Flop  \\
    74LS86                   & 1 & 4x XOR  \\
    74LS123                  & 2 & 2x Monostable Multivibrator  \\
    74LS138                  & 2 & 3-to-8 Decoder  \\
    74LS157                  & 1 & 4-bit Data Selector \\
    74LS161                  & 2 & 8-Bit Counter  \\
    74LS173                  & 9 & 8-Bit Register  \\
    74LS193                  & 14 & 8-Bit U/D Counter  \\
    74LS245                  & 10 & 8-Bit Bus Transceiver  \\
    74HC595                  & 1 & 8-Bit Shift Register  \\
    MC14078B                 & 2 & 8-Input NOR  \\
    NE555                    & 4 & 555-Timer \\
    AT28C64B                 & 4 & 64K EEPROM  \\
    AS6C4008                 & 2 & 512K SRAM  \\
    ICM7226B                 & 1 & Frequency Timer  \\
  \end{tabular}
  \caption{IC's used in the project.}
  \label{tab:parts}
\end{table}

\section{Passive Components}

\begin{table}[H]
  \centering
  \begin{subtable}[t]{0.3\textwidth}
    \vspace{0pt}
    \begin{tabular}{r|l}
      Value                    & Quantity \\ \hline
      220 $\Omega$              & 1  \\
      330 $\Omega$              & 8  \\
      470 $\Omega$              & 80 \\
      1 $k\Omega$               & 5  \\
      2 $k\Omega$               & 1  \\
      4.7 $k\Omega$             & 10 \\
      5 $k\Omega$               & 3  \\
      10 $k\Omega$              & 5  \\
      100 $k\Omega$             & 2  \\
      220 $k\Omega$             & 1  \\
      470 $k\Omega$             & 1  \\
      10 $M\Omega$              & 2  \\
    \end{tabular}
    \caption{Resistors}
  \end{subtable}
  \hfill
  \begin{subtable}[t]{0.3\textwidth}
    \vspace{0pt}
    \begin{tabular}{r|l}
      Value                    & Quantity \\ \hline
      470 $\mu F$              & 1 \\    
      10 $\mu F$               & 1 \\    
      4.7 $\mu F$              & 1 \\    
      1 $\mu F$                & 3 \\    
      100 nF (104)             & 50\\    
      10 nF (103)              & 5 \\    
      2.2 nF (222)             & 1 \\
      1 nF (102)               & 4 \\
      470 pF (471)             & 1 \\
      220 pF (221)             & 1 \\
      100 pF (101)             & 1 \\    
      47 pF                    & 2  \\    
      22 pF                    & 2  \\    
    \end{tabular}
    \caption{Capacitors}
  \end{subtable}
  \hfill
  \begin{subtable}[t]{0.3\textwidth}
    \vspace{0pt}
    \begin{tabular}{r|l}
      Value                      & Quantity \\ \hline
      10 MHz crystal             & 1 \\    
      16 MHz crystal             & 1 \\
      10 k$\Omega$ potentiometer & 2 \\
      Toggle switch              & 2 \\
      DIP switch (x8)            & 1 \\
      Tactile button             & 5 \\
      20-22AWG wire              & ? \\
    \end{tabular}
    \caption{Other passive components}
  \end{subtable}

  \caption{Resistors, capacitors and other passive components used in the project.}
  \label{tab:rcbom}
\end{table}

\section{Other Parts}
\begin{table}[H]
  \centering
  \begin{tabular}{r|c|l}
    Part                     & Quantity & Description \\\hline
    Breadboard               & $\sim$25 & 830 hole  \\
    Single 7-Segment Display & 2 &    \\
    Quad 7-Segment Display   & 2 &    \\
    Single LED               & 15& Various colors \\
    Bar LED strip            & 11& 10 LEDs per strip  \\
    HD44780 Compatible LCD   & 1 & 4x20 Characters  \\
  \end{tabular}
  \caption{Other parts used in the project.}
  \label{tab:parts}
\end{table}

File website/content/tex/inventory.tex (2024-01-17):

\section{Inventory} \label{sec:inventory}
For the creation of the processor we used a vast inventory of tools and elements, like resistors, LEDs, and capacitors. However, other components are, mostly, digital chips created by different manufacturers and have also been utilized. In this section, we provide the reader with an approximate list of all tools and components utilized or used during the process.

\subsection{Electronic components}
\begin{itemize}
	\item LEDs with different colors (white, yellow, red, blue, and green);
	\item Capacitors of a wide range (from 0.1 (nano Farad) up to 4000 (micro Farad));
	\item Resistors of a wide range (from 10 Ohm up to 1M Ohm);
	\item Seven-segment displays;
	\item Ribbon cables;
	\item Diodes;
	\item Voltage sources (batteries and AC to DC converters);
	\item Arduino Uno/Nano;
	\item ESM32;
	\item NAND (00 series);
	\item NOR (02 series);
	\item NOT (04 series);
	\item AND (08 series);
	\item OR (32 series);
	\item XOR (86 series);
	\item Seven-segment display decoders (48 series);
	\item JK Flip-flops (76 series);
	\item 4-bit count registers (74LS161);
	\item 4-bit registers (74LS173);
	\item 4-bit registers with up/down (74LS193);
	\item 8-bit shift registers (595 series);
	\item 8-bit bus tranceivers (245 series);
	\item 555 timers
	\item 3-to-8 demultiplexers (138 series);
	\item 4-bit NANDs (20 series);
	\item 4-bit NORs (21 series);
	\item 3-to-8 multiplexers (151 series);
	\item ROM 
	\item RAM (AS6C4008);
	\item et cetera. 
\end{itemize}

\subsection{Tools and instrumentation}
\begin{itemize}
	\item wire cutters;
	\item pliers;
	\item multimeters;
	\item oscilloscope;
	\item probes;
	\item soldering machine;
	\item et cetera.
\end{itemize}

\subsection{Digital tools}
\begin{itemize}
	\item Linux (Fedora);
	\item Emacs;
	\item Logisim;
	\item Inkscape;
	\item TeXstudio;
	\item Git/Github;
	\item Visual Studio Code;
	\item C++ compilers (g++), C++ build tools (CMake);
	\item et cetera.
\end{itemize}

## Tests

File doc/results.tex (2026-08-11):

\chapter{Runtime Results} \label{sec:results}
In this chapter we show snapshots of the output during the execution of each of the BF programs listed in Appendix \ref{sec:appendix:testsuite}. Each of these programs was able to run successfully at the maximum clock speed of around 250~kHz ($5\times256=1280$ bytes of memory were initialized to 0). For each program, the following statistics have been collected in a modified version of the interpreter shown in Listing \ref{lst:bfint}:

\begin{itemize}
\item \emph{Program Size} - the number of BF commands in the program, i.e.~the number of bytes in the \texttt{.bf} file, not counting non-BF characters.
\item \emph{Stack Size Required} - size of the stack required to run the program, i.e.~the maximum nesting depth encountered while executing loops.
\item \emph{Memory Cells Required} - the minimum number of memory cells required to execute the program. In our case, this corresponds to the minimal amount of cells that needs to be zero-initialized at startup in order for the program to execute correctly.
\item \emph{Runtime Instructions} - the number of BF instructions that are executed when the program is run. Due to the existence of loops, this number differs (for most programs) from the program size.
\item \emph{Runtime Clock Cycles} - the number of clock cycles that elapsed over the course of execution.
\item \emph{Cycles per Instruction} - the average number of clock cycles needed to execute a single BF instruction. This value changes from program to program and depends on the structure of the program, the number of skipped loops, commonality of command sequences that leverage the A and V flags, etc. These values have been measured in the interpreter and have been (roughly) verified on the physical hardware.
\end{itemize}

\section{Stability}
Throughout development, the system was plagued by instabilities. At first, these could be traced back to bugs in the microcode, subtle architectural issues or even wrong connections that only sometimes caused problems. Then, the clock speed and overall stability were highly influenced by bad IO design. The IO module was connected to the system clock and expected to run its interrupt routine (ISR) within the time between two ticks; this left the module unresponsive at high clock speeds (there was almost no time between calls to the ISR to manage other functionality like polling the keyboard) and would sometimes cause bus contention if it could not reset its outputs in time. With a proper handshake implemented using the K-flag and a completely asynchronous setup where the IO module only polls its input at a very low frequency, leaving the rest of the microcontroller's capacity for handling the user interface, all these problems went away. New clock speeds were achieved to the point that it became stable up to the limits of the clock module itself. It has not been pushed any further at the time of writing, though that may very well be possible.

\section{Test Suite}
\subsection{\texttt{hello.bf}}

\begin{figure}[H]
  \centering
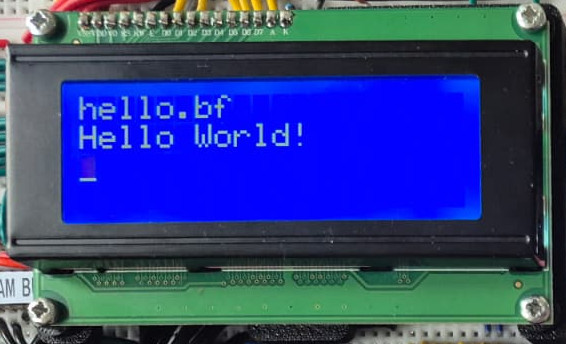
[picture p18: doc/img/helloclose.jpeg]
  
  \caption{\emph{Hello World}}
  \label{fig:hello}
\end{figure}

It should be obvious why \emph{Hello World} is the first program to test. The output is simply the string \emph{``Hello World!''} followed by a newline. This program performed as expected on any selected clock frequency within the supported range (and maybe even beyond). This program was taken straight from the Wikipedia page on Brainfuck \cite{hello}.

\begin{table}[H]
  \centering
  \begin{tabular}{r|c}
    Program Size & 112 \\
    Stack Size Required & 1 \\
    Memory Cells Required & 4 \\
    Runtime Instructions & 390 \\
    Runtime Clock Cycles & 1273 \\
    Cycles per Instruction & 3.3 \\
  \end{tabular}
  \caption{Properties of \texttt{hello.bf}, see Appendix \ref{sec:appendix:testsuite:hello}}
  \label{tab:hello}
\end{table}

\subsection{\texttt{euler.bf}}

\begin{figure}[H]
  \centering
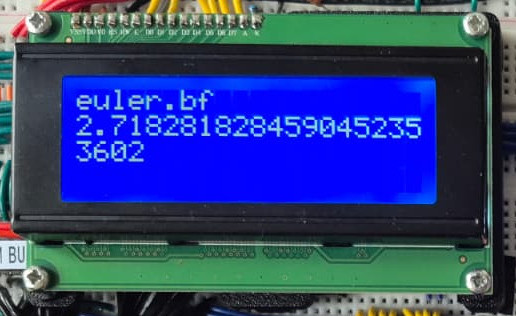
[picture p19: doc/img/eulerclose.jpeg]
  
  \caption{\emph{Calculating Euler's Number}}
  \label{fig:euler}
\end{figure}

The Euler number ($e$) is an irrational number, so calculating its digits is an infinite process; the \texttt{euler.bf} program (written by the notorious BF developer Daniel Cristofani \cite{euler}) never ends. Running this program for a long time exposes a weakness of the system; sometimes the system gets into some erroneous state and goes haywire. It is still not fully understood what causes this to happen; based on qualitative observations, it seems as if the probability of failure increases with time and persists afterwards even after a reset. Shorting the power rails (after power has been disconnected) seems to stabilize the system again, so maybe the instability stems from charge buildup due to bad connections to power. Such bad connections have been found throughout the build process, so there may still be subtle bad connections present around the board.

Since this program runs indefinitely, there is no bound to the number of runtime instructions. The number of memory cells required also keeps growing with time; it was found to grow proportionally to the square root of the number of BF instructions that had been executed up to that point according to $M = 0.36\sqrt{N}$. A quick back-of-the-envelope calculation shows that for our case, with 65,280 data cells available (the first 256 addresses are reserved for the stack), we'd be able to execute $\left(\frac{65{,}280}{0.36}\right)^2 = 3.3\times10^{10}$ BF instructions, which would take $1.1\times 10^{11}$ cycles to complete (using the measured value of 3.4 cycles per instruction), or $4.5\times 10^5$ seconds at 250 kHz (over 124 hours). It's probably safe to assume that those limits won't be reached any time soon.

\begin{table}[H]
  \centering
  \begin{tabular}{r|c}
    Program Size & 1424 \\
    Stack Size Required & 11 \\
    Memory Cells Required & $\sim\sqrt{N}$ \\
    Runtime Instructions & $\infty$ \\
    Runtime Clock Cycles & $\infty$ \\
    Cycles per Instruction & 3.4 \\
  \end{tabular}
  \caption{Properties of \texttt{euler.bf}, see Appendix \ref{sec:appendix:testsuite:euler}}
  \label{tab:euler}
\end{table}

\subsection{\texttt{phi.bf}}

\begin{figure}[H]
  \centering
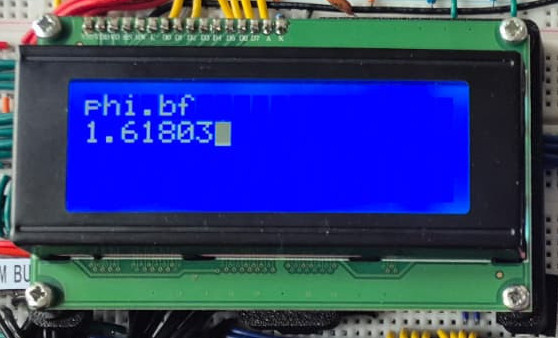
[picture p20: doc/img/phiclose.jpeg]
  
  \caption{\emph{Calculating $\phi$}}
  \label{fig:phi}
\end{figure}

Like $e$, the Golden Ratio $\phi = \frac{1+\sqrt{5}}{2}$ is irrational and thus has infinitely many digits. The \texttt{phi.bf} program \cite{phi} runs indefinitely and has growing memory demands when it runs for a longer amount of time. Again, the number of memory cells required grows as the square root of the number of BF commands executed according to $M=71+0.033\sqrt{N}$. This number grows even more slowly than that required to calculate Euler's number, so there won't be any memory issues here either.

\begin{table}[H]
  \centering
  \begin{tabular}{r|c}
    Program Size & 1950 \\ 
    Stack Size Required & 17 \\
    Memory Cells Required & $\sim\sqrt{N}$ \\
    Runtime Instructions & $\infty$ \\
    Runtime Clock Cycles & $\infty$ \\
    Cycles per Instruction & 3.6 \\
  \end{tabular}
  \caption{Properties of \texttt{phi.bf}, see Appendix \ref{sec:appendix:testsuite:phi}}
  \label{tab:phi}
\end{table}

\subsection{\texttt{factorial.bf}}

\begin{figure}[H]
  \centering
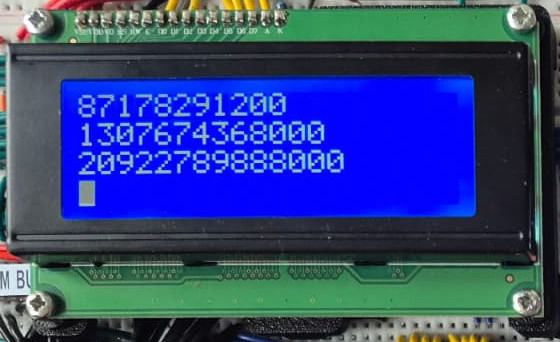
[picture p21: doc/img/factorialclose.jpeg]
  
  \caption{\emph{Calculating increasingly larger factorials}}
  \label{fig:factorial}
\end{figure}

Another program that runs indefinitely is \texttt{factorial.bf}; it calculates $n!$ for ever increasing $n$ ad infinitum. Unfortunately, this program was found and downloaded long before this report ever needed to mention it; we were unable to trace and credit its source at the time of writing. The memory requirement grows according to a cube root, so this program can run for an even longer time compared to \texttt{phi.bf} and indeed \texttt{euler.bf} before memory runs out (provided it runs without issue): $M = 12.5 \sqrt[3]{N}$.

\begin{table}[H]
  \centering
  \begin{tabular}{r|c}
    Program Size & 964 \\
    Stack Size Required & 15 \\
    Memory Cells Required & $\sim\sqrt[3]{N}$ \\
    Runtime Instructions & $\infty$ \\
    Runtime Clock Cycles & $\infty$ \\
    Cycles per Instruction & 3.6 \\
  \end{tabular}
  \caption{Properties of \texttt{factorial.bf}, see Appendix \ref{sec:appendix:testsuite:factorial}}
  \label{tab:factorial}
\end{table}

\subsection{\texttt{primes.bf}}

\begin{figure}[H]
  \centering
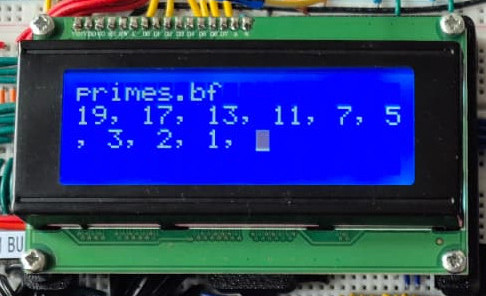
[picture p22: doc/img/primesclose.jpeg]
  
  \caption{\emph{Calculating primes $<20$.}}
  \label{fig:primes}
\end{figure}

Found on Reddit by the user Troemax \cite{primes}, this program checks primality for all numbers $\le 20$ (this value can be adjusted by changing the number of \texttt{+} commands at the very start of the program). It runs stable at all tested clock speeds up to 250 kHz. The algorithm reuses memory very efficiently during the course of its execution, requiring only 18 cells.

\begin{table}[H]
  \centering
  \begin{tabular}{r|c}
    Program Size & 790 \\
    Stack Size Required & 7 \\
    Memory Cells Required & 18 \\
    Runtime Instructions & 3.6M \\
    Runtime Clock Cycles & 12M \\
    Cycles per Instruction & 3.3 \\
  \end{tabular}
  \caption{Properties of \texttt{primes.bf}, see Appendix \ref{sec:appendix:testsuite:primes}}
  \label{tab:primes}
\end{table}

\subsection{\texttt{primes2.bf}}

\begin{figure}[H]
  \centering
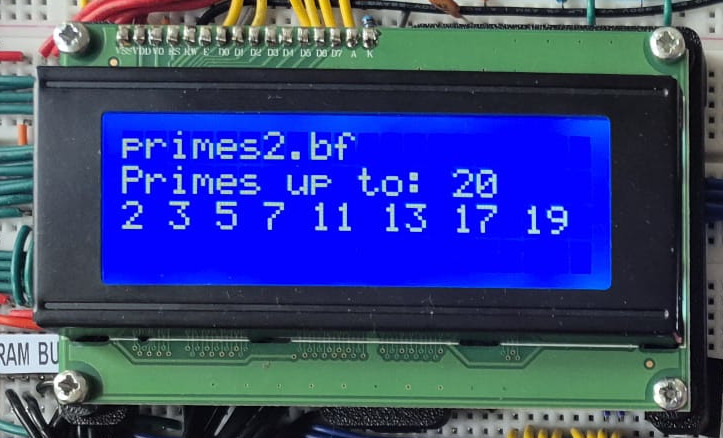
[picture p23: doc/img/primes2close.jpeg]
  
  \caption{\emph{Calculating primes $<20$ (entered at runtime).}}
  \label{fig:primes2}
\end{figure}

Like the former prime-generating program, this program calculates all primes below 20. The difference between \texttt{primes.bf} and \texttt{primes2.bf} is that the latter asks for the upper bound at runtime (expecting keyboard input). The program was posted on the Code Golf section of Stack Exchange by user Alexandru, challenging other users to implement small interpreters that can successfully run it.

\begin{table}[H]
  \centering
  \begin{tabular}{r|c}
    Program Size & 3880 \\
    Stack Size Required & 6 \\
    Memory Cells Required & 10 \\
    Runtime Instructions & 5K \\
    Runtime Clock Cycles & 1.8M \\
    Cycles per Instruction & 3.5 \\
  \end{tabular}
  \caption{Properties of \texttt{primes2.bf}, see Appendix \ref{sec:appendix:testsuite:primes2}}
  \label{tab:primes2}
\end{table}

\subsection{\texttt{tictactoe.bf}}

\begin{figure}[H]
  \centering
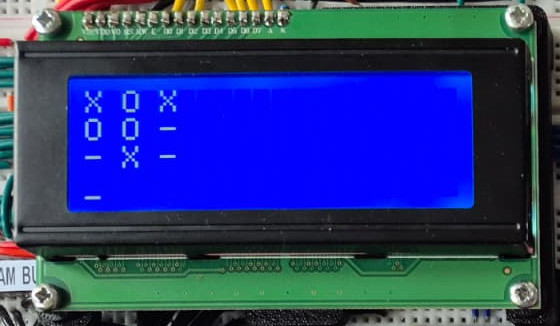
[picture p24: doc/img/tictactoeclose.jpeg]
  
  \caption{\emph{Playing Tic Tac Toe against Synapse-191.}}
  \label{fig:tictactoe}
\end{figure}

Found on GitHub \cite{tictactoe}, from a developer by the username Mixtela \cite{tictactoe}, we found a BF program that actually implements a game of Tic Tac Toe, including a very capable `AI' opponent. The statistics in Table \ref{tab:tictactoe} have been gathered by playing a single game (which ended in a draw).

\begin{table}[H]
  \centering
  \begin{tabular}{r|c}
    Program Size & 6880 \\
    Stack Size Required & 12 \\
    Memory Cells Required & 72 \\
    Runtime Instructions & 224K \\
    Runtime Clock Cycles & 774K \\
    Cycles per Instruction & 3.5 \\
  \end{tabular}
  \caption{Properties of \texttt{tictactoe.bf}, see Appendix \ref{sec:appendix:testsuite:tictactoe}}
  \label{tab:tictactoe}
\end{table}

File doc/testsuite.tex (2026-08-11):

\chapter{BF Test Suite} \label{sec:appendix:testsuite}

\section{Hello World} \label{sec:appendix:testsuite:hello}
\begin{lstfloat}[H]
  \lstinputlisting{../src/bf/testsuite/hello.bf}  
\caption{hello.bf, \cite{hello}}
\label{lst:hello}
\end{lstfloat}

\section{Factorial} \label{sec:appendix:testsuite:factorial}
\begin{lstfloat}[H]
  \lstinputlisting{../src/bf/testsuite/factorial.bf}  
\caption{factorial.bf}
\label{lst:factorial}
\end{lstfloat}

\section{Euler's Number} \label{sec:appendix:testsuite:euler}
\begin{lstfloat}[H]
  \lstinputlisting{../src/bf/testsuite/euler.bf}  
\caption{euler.bf, \cite{euler}}
\label{lst:euler}
\end{lstfloat}

\section{Golden Ratio} \label{sec:appendix:testsuite:phi}
\begin{lstfloat}[H]
  \lstinputlisting{../src/bf/testsuite/phi.bf}  
\caption{phi.bf, \cite{phi}}
\label{lst:phi}
\end{lstfloat}

\section{Primes} \label{sec:appendix:testsuite:primes}
\begin{lstfloat}[H]
  \lstinputlisting{../src/bf/testsuite/primes.bf}  
\caption{primes.bf, \cite{primes}}
\label{lst:primes}
\end{lstfloat}

\section{Primes 2} \label{sec:appendix:testsuite:primes2}
\begin{lstfloat}[H]
  \lstinputlisting{../src/bf/testsuite/primes2.bf}  
\caption{primes2.bf, \cite{primes2}}
\label{lst:primes2}
\end{lstfloat}

\section{Tic Tac Toe} \label{sec:appendix:testsuite:tictactoe}
\begin{lstfloat}[H]
\lstinputlisting{../src/bf/testsuite/tictactoe.bf}
\caption{tictactoe.bf, \cite{tictactoe}}
\label{lst:tictactoe}
\end{lstfloat}

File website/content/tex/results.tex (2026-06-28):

\chapter{Runtime Results} \label{sec:results}
In this section we show snapshots of the output during the execution of each of the BF programs listed in Appendix \ref{sec:appendix:testsuite}. Each of these programs was able to run successfully at the maximum clock speed of around 250kHz ($5\times256=1280$ bytes of memory were initialized to 0). For each program, the following statistics have been collected in a modified version of the interpreter shown in Listing \ref{lst:bfint}:

\begin{itemize}
\item \emph{Program Size} - the number of BF commands in the program, i.e.~the number of bytes in the \texttt{.bf} file, not counting non-BF characters.
\item \emph{Stack Size Required} - size of the stack required to run the program, i.e.~the maximum nesting depth encountered while executing loops.
\item \emph{Memory Cells Required} - the minimum number of memory cells required to execute the program. In our case, this corresponds to the minimal amount of cells that needs to be zero-initialized at startup in order for the program to execute correctly.
\item \emph{Runtime Instructions} - the number of BF instructions that are executed when the program is run. Due to the existence of loops, this number differs (for most programs) from the program size.
\item \emph{Runtime Clock Cycles} - the number of clock cycles that elapsed over the course of execution.
\item \emph{Cycles per Instruction} - the average number of clock cycles needed to execute a single BF instruction. This value changes from program to program and depends on the structure of the program, the number of skipped loops, commonality of command sequences that leverage the A and V flags, etc. These values have been measured in the interpreter and have been (roughly) verified on the physical hardware.
\end{itemize}

\section{Stability}
Throughout development, the system was plagued by instablilities. At first, these could be traced back to bugs in the microcode, subtle architectural issues or even wrong connections that only sometimes cause problems. Then, the clock speed and overall stability was highly influenced by bad IO design. The IO module was connected to the system clock and expected to run its interrupt routine (ISR) within the time between two ticks; this left the module unresponsive on high clocks (there was near to no time between calls to the ISR to manage other functionality like polling the keyboard) and would sometimes cause bus contention if it could not reset its outputs in time. With a proper handshake implemented using the K-flag and a completely asynchronous setup where the IO module only polls its input at a very low frequency, leaving the rest of the microcontroller's capacity to handling the user interface, all these problems went away. New clock speeds were achieved to the point that it became stable up to the limits of the clock module itself. It has not been pushed any further at the time of writing, though that may very well be possible.

\section{Test Suite}
\subsection{\texttt{hello.bf}}

\begin{figure}[H]
  \centering
  
  \caption{\emph{Hello World}}
  \label{fig:hello}
\end{figure}

It should be obvious why \emph{Hello World} is the first program to test. The output is simply the string \emph{``Hello World!''} followed by a newline. This program performed as expected on any selected clock frequency within the supported range (and maybe even beyond). This program was taken straight from the Wikipedia page on Brainfuck \cite{hello}.

\begin{table}[H]
  \centering
  \begin{tabular}{r|c}
    Program Size & 112 \\
    Stack Size Required & 1 \\
    Memory Cells Required & 4 \\
    Runtime Instructions & 390 \\
    Runtime Clock Cycles & 1273 \\
    Cycles per Instruction & 3.3 \\
  \end{tabular}
  \caption{Properties of \texttt{hello.bf}, see Appendix \ref{sec:appendix:testsuite:hello}}
  \label{tab:hello}
\end{table}

\subsection{\texttt{euler.bf}}

\begin{figure}[H]
  \centering
  
  \caption{\emph{Calculating Euler's Number}}
  \label{fig:euler}
\end{figure}

The Euler number ($e$) is an irrational number, so calculating its digits is an infinite process; the \texttt{euler.bf} program (written by the notorious BF developer Daniel Cristofani \cite{euler}) never ends. Running this program for a long time exposes a weakness of the system; sometimes the system get into some erroneous state and go haywire. It is still not fully understood what causes this to happen; based on qualitative observations, it seems as if the probability of failure increases with time and persists afterwards even after a reset. Shorting the power rails (after power has been disconnected) seems to stabilize the system again, so maybe the instability stems from charge buildup due to bad connections to power. Such bad connections have been found throughout the build process, so there may still be subtle bad connections present around the board. 

Since this programs runs indefinitely, there was no bound to the number of runtime instructions. The number of memory cells required also keeps growing with time; it was found to grow proportional to the square root of the number of BF instructions that had been executed up to that point according to $M = 0.36\sqrt{N}$. A quick back-of-the-envelope calculation shows that for our case, with 64K ($2^{16}$ cells) of RAM available (the stack is negligible in comparison), we'd be able to execute $\left(\frac{2^{16}}{0.36}\right)^2 = 3.3\times10^{10}$ BF instructions, which would take $1.1\times 10^{11}$ cycles to complete (using the measured value of 3.4 cycles per instruction), or $4.5\times 10^5$ seconds at 250 kHz (over 124 hours). It's probably safe to assume that those limits won't be reached any time soon.

\begin{table}[H]
  \centering
  \begin{tabular}{r|c}
    Program Size & 1424 \\
    Stack Size Required & 11 \\
    Memory Required & $\sim\sqrt{N}$ \\
    Runtime Instructions & $\infty$ \\
    Runtime Clock Cycles & $\infty$ \\
    Cycles per Instruction & 3.4 \\
  \end{tabular}
  \caption{Properties of \texttt{euler.bf}, see Appendix \ref{sec:appendix:testsuite:euler}}
  \label{tab:euler}
\end{table}

\subsection{\texttt{phi.bf}}

\begin{figure}[H]
  \centering
  
  \caption{\emph{Calculating $\phi$}}
  \label{fig:euler}
\end{figure}

Like $e$, the Golden Ration $\phi = \frac{1+\sqrt{5}}{2}$ is irrational and thus has infinitely many digits. The \texttt{phi.bf} program \cite{phi} runs indefinitely and has growing memory demands when it runs for a longer amount of time. Again, the number of memory cells requires grows as the square root of the number of BF commands executed according to $M=71+0.033\sqrt{N}$. This number grows even slower than that required to calculate Euler's number, so there won't be any memory issues here neither.

\begin{table}[H]
  \centering
  \begin{tabular}{r|c}
    Program Size & 1950 \\ 
    Stack Size Required & 17 \\
    Memory Required & $\sim\sqrt{N}$ \\
    Runtime Instructions & $\infty$ \\
    Runtime Clock Cycles & $\infty$ \\
    Cycles per Instruction & 3.6 \\
  \end{tabular}
  \caption{Properties of \texttt{phi.bf}, see Appendix \ref{sec:appendix:testsuite:phi}}
  \label{tab:phi}
\end{table}

\subsection{\texttt{factorial.bf}}

\begin{figure}[H]
  \centering
  
  \caption{\emph{Calculating increasingly larger factorials}}
  \label{fig:euler}
\end{figure}

Another program that runs indefinitely is \texttt{factorial.bf}; it calculates $n!$ for ever increasing $n$ ad infinitum. Unfortunately, this program was found and downloaded long before this report ever needed to mention it; we were unable to trace and credit its source at the time of writing. The memory requirement grows according to a cube root, so this program can run for an even longer time compared to \texttt{phi.bf} and indeed \texttt{euler.bf} before memory runs out (provided it runs without issue): $M = 12.5 \sqrt[3]{N}$.

\begin{table}[H]
  \centering
  \begin{tabular}{r|c}
    Program Size & 964 \\
    Stack Size Required & 15 \\
    Memory Required & $\sim\sqrt[3]{N}$ \\
    Runtime Instructions & $\infty$ \\
    Runtime Clock Cycles & $\infty$ \\
    Cycles per Instruction & 3.6 \\
  \end{tabular}
  \caption{Properties of \texttt{factorial.bf}, see Appendix \ref{sec:appendix:testsuite:factorial}}
  \label{tab:factorial}
\end{table}

\subsection{\texttt{primes.bf}}

\begin{figure}[H]
  \centering
  
  \caption{\emph{Calculating primes $<20$.}}
  \label{fig:euler}
\end{figure}

Found on Reddit by the user Troemax \cite{primes}, this program checks primality for all numbers $\le 20$ (this value can be adjusted by changing the number of \texttt{+} commands at the very start of the program). It runs stable at all tested clock speeds up to 250 kHz. The algorithm reuses memory very efficiently during the course of its execution, requiring only 18 cells.

\begin{table}[H]
  \centering
  \begin{tabular}{r|c}
    Program Size & 790 \\
    Stack Size Required & 7 \\
    Memory Required & 18 \\
    Runtime Instructions & 3.6M \\
    Runtime Clock Cycles & 12M \\
    Cycles per Instruction & 3.3 \\
  \end{tabular}
  \caption{Properties of \texttt{primes.bf}, see Appendix \ref{sec:appendix:testsuite:primes}}
  \label{tab:primes}
\end{table}

\subsection{\texttt{primes2.bf}}

\begin{figure}[H]
  \centering
  
  \caption{\emph{Calculating primes $<20$ (entered at runtime).}}
  \label{fig:euler}
\end{figure}

Like the former prime generating program, this program calculates all primes below 20. The difference between between \texttt{primes.bf} and \texttt{primes2.bf} is that the latter asks for the upper bound at runtime (expecting keyboard input). The program was posted on the codegolf section of Stackexchange by user Alexandru, challenging other users to implement small interpreters that can successfully run it. 

\begin{table}[H]
  \centering
  \begin{tabular}{r|c}
    Program Size & 3880 \\
    Stack Size Required & 6 \\
    Memory Required & 10 \\
    Runtime Instructions & 5K \\
    Runtime Clock Cycles & 1.8M \\
    Cycles per Instruction & 3.5 \\
  \end{tabular}
  \caption{Properties of \texttt{primes.bf}, see Appendix \ref{sec:appendix:testsuite:primes2}}{tab:primes2}
\end{table}

\subsection{\texttt{tictactoe.bf}}

\begin{figure}[H]
  \centering
  
  \caption{\emph{Playing Tic Tac Toe against Synapse-191.}}
  \label{fig:tictactoe}
\end{figure}

Found on Github \cite{tictactoe}, from a developer by the username Mixtela \cite{tictactoe}, we found a BF program that actually implements a game of Tic Tac Toe, including a very capable `AI' opponent. The statistics in Table \ref{tab:tictactoe} have been gathered by playing a single game (which ended in a draw).

\begin{table}[H]
  \centering
  \begin{tabular}{r|c}
    Program Size & 6880 \\
    Stack Size Required & 12 \\
    Memory Required & 72 \\
    Runtime Instructions & 224K \\
    Runtime Clock Cycles & 774K \\
    Cycles per Instruction & 3.5 \\
  \end{tabular}
  \caption{Properties of \texttt{tictactoe.bf}, see Appendix \ref{sec:appendix:testsuite:tictactoe}}
  \label{tab:tictactoe}
\end{table}

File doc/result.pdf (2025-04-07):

### BFCPU 1.0

Joren Heit, Arthur Topal

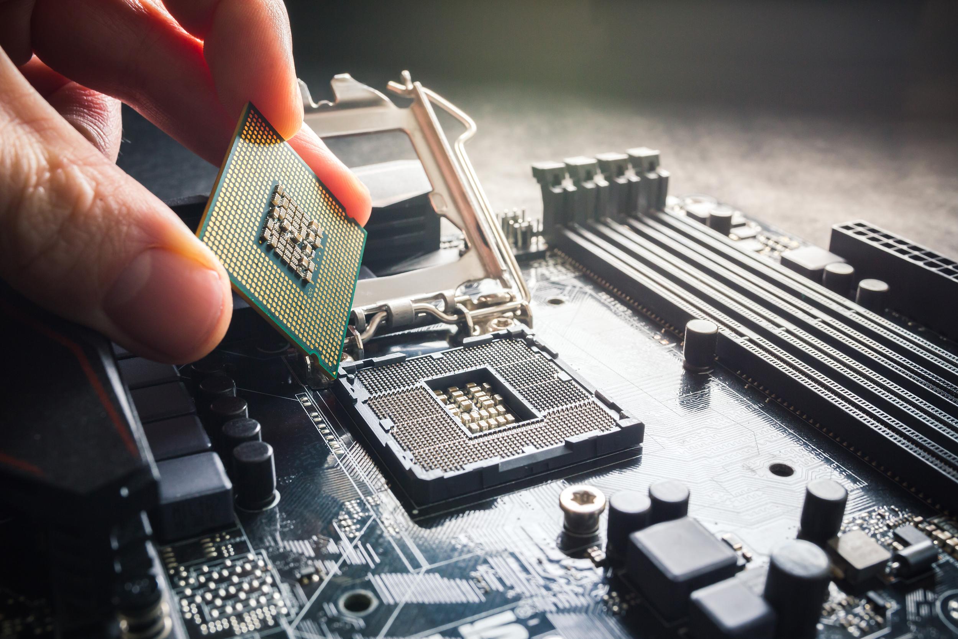
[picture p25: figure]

## Contents

1 Introduction | 4
2 Brainf*ck | 5
3 Architecture | 9
4 Control Sequences | 16
5 Implementation | 21

2

6 Utilities | 48

3

## 1 Introduction

The Brainf*ck¹
(BF) programming language is an esoteric programming language that is basically impossible, or at least very unpractical, to actually write useful programs in. Even if you would become a very skilled programmer in this language, the resulting programs would be incredibly slow to execute. Despite this, many programmers have challenged themselves to write stunning pieces of code just for fun, or for the learning experience it offers. In doing so, it teaches us about computer architecture, compilers/interpreters, memory, pointers and much more. For more information on the language itself, see chapter 2.
The goal of this project is to build a computer that can actually run BF code natively. Normally, after having written some new piece of BF, the programmer must run this code in another program to either compile or interpret it to see whether it works. However, when looking more closely at the language, it seems a lot like an instruction set for a (not yet) existing processor. This is what we aim to do in this project: build that thing.
The aim is to build a Brainf*ck CPU without making use of any programmable chips. We will only use discrete logic and relatively simple integrated circuits like registers, buffers and (de)multiplexers. The computer will be built on breadboards, as it was inspired by Ben Eater’s 8-bit breadboard computer [4]. This report will document the design and implementation of the BFCPU.

1The asterisk was inserted by the authors and is not part of the official name.

4

## 2 Brainf*ck

Brainf*ck is a popular esoteric programming language. Just like any other programming language, it allows the programmer to write programs consisting of commands that are executed in order. The catch is that there is a total of only 8 commands available to the programmer, all written as a single character: “+-<>[].,”. Each of these commands corresponds to an operation on an array of memory or a pointer, pointing to some location within this memory. At the start of the program, every cell in (an infinite amount of) memory is initialized to 0 and the pointer is pointing to the very first element (index 0, see Figure 1).

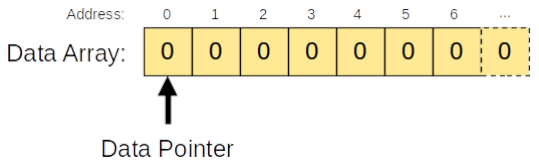
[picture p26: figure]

Figure 1: Initial state of the BF machine.

The commands then modify the contents of memory and the pointer as follows:

- + : add 1 to the current cell;
- - : subtract 1 from the current cell;
- < : move the pointer 1 cell to its left;
- > : move the pointer 1 cell to its right;
- [ : if the current cell is nonzero, continue. Otherwise, skip to the matching closing ];
- ] : if the current cell is zero, continue. Otherwise, loop back to its matching opening [;
- . : send the value in the current cell to the output;
- , : read a value from the input and store it into the current cell.

Although this might seem like a very limited set of instructions, it has been proven to be sufficient for performing any possible computation or program, also known as Turing-completeness [2]. The catch is that this requires an unbounded (or infinite) amount of memory, which is obviously impossible. However, the same caveat holds for traditional (von Neumann architecture) systems, so we should be safe to assume that BF is Turing complete for all practical purposes.
To run a BF program, one usually feeds these commands into an interpreter written in a more common language. These interpreters are very straightforward to write. Listing 1 shows a very simple implementation (about 40 lines) of such a program in C. This implementation initializes a block of memory to zero and defines a pointer to its first element. This pointer can be incremented or decremented to move along the array, increment/decrement value it’s pointing or print it to standard output. The most complexity is embedded in the handling of the loop-operatores. When an opening bracket is encountered, the index of this instruction is stored in a jump-table. When the matching closing bracket is encountered and it is determined that flow should loop back, this stored index is reloaded. When a loop is being skipped, all commands within it are being skipped until the matching closing brace is found.
When the Hello World program from Wikipedia [1] is fed into this program, it prints out the string Hello World!, as expected.
1 | $ ./ bfint "++++++++[ >++++[ >++ >+++ >+++ >+ < < < < -] >+ >+ > - > >+[ <] < -] \
2 | > >. > - - -.+++++++..+++. > >. < -. <.+++. - - - - - -. - - - - - - - -. > >+. >++."
3 | Hello World !

5

// ---------- bfint_begin - - - - - - - - - -void bfint ( char const * program ) { unsigned char mem [ MEM_SIZE ]; memset ( mem , 0 , MEM_SIZE ) ; unsigned char * ptr = mem ;

int jmp_table [ JMP_TABLE_SIZE ];
int jmp_index = 0;

int program_size = strlen ( program ) ; int index = 0;

while ( index < program_size ) { switch ( program [ index ]) { case ’+ ’: ++(* ptr ) ; break ; case ’ - ’: - -(* ptr ) ; break ;
case ’ < ’: -- ptr ; break ;
case ’ > ’: ++ ptr ; break ;
case ’. ’: putchar (* ptr ) ; break ;
case ’ , ’: (* ptr ) = getchar () ; break ;
case ’[ ’: {
if (* ptr ) jmp_table [ jmp_index ++] = index ; else {
int count = 1;
while ( count != 0) {
switch ( program [++ index ]) { case ’[ ’: ++ count ; break ; case ’] ’: -- count ; break ;

}

}

}
break ;

}
case ’] ’: {
-- jmp_index ;
if (* ptr ) index = jmp_table [ jmp_index ++]; break ;

}}
++ index ;

}

}
// ---------- bfint_end - - - - - - - - - -

Listing 1: Very basic implementation of a BF interpreter in C.

### 2.1 Architectures

### 2.1.1 Von Neumann

Modern computers are built according to the von Neumann architecture [3], which specifies a CPU (containing registers and an ALU), a single unit of memory and input/output devices (Figure 2). The registers of the CPU can be loaded with data from the memory unit and operated on by the ALU (Arithmetic and Logic Unit). Typical about this kind of architecture is the fact that not only data, but also the instructions (the program) are stored in memory. The program is therefore just as much part of the data as the data itself and can even be modified by itself.

6

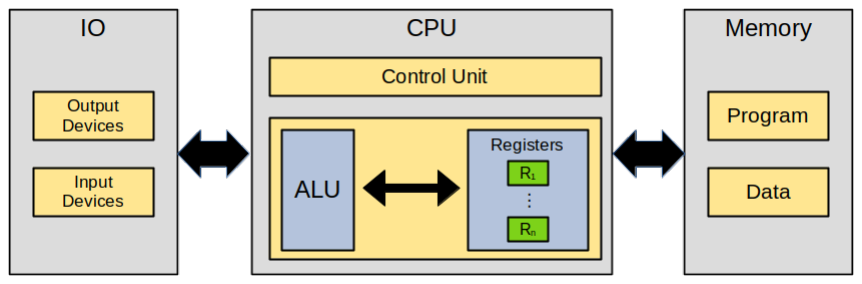
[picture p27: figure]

Figure 2: Schematic overview of the Von Neumann architecture.

### 2.1.2 Harvard

Unlike within the Von Neumann architecture, the Harvard architecture specifies two kinds of memory: program memory and data memory (Figure 3). The program memory contains only the instructions to be carried out and cannot be modified at runtime. Other than that, the architecture is similar to Von Neumann, in that it consists of a CPU (again containing registers and an ALU), memory (program and data) and input/output devices.


Figure 3: Schematic overview of the Harvard architecture.

The architecture assumed by the BF language is similar to the Harvard architecture, in that the memory does not contain the program itself. This implies that the program is stored somewhere else and cannot be addressed by the pointer, like in Listing 1, where the program was stored in a seperate array to the data. The ALU is very limited and can only perform increment, decrement and comparison to zero.

### 2.2 BF as an Instruction Set

Instead of viewing BF as a language that needs to be compiled or interpreted on a traditional machine, it can also be seen as an instruction set to a processor, built according to the BF architecture described above. An instruction set of size 8 is truly tiny compared to more traditional instruction sets such as those implemented by modern processors or even microcontrollers and older 8-bit systems. Broadly speaking, Complex Instruction Set Computers (CISC) are designed to do as much work as possible in the least number of clock cycles, whereas Reduced Instruction Set Computers (RISC) focus on having a small instruction set with basic operations. For comparison, the x86 instruction set is massive with over 1500 instructions implemented in hardware, whereas RISC processors only need to implement 50 to 100 instuctions. Even compared to RISC, the BF instruction set (BFISC from hereon) is tiny even compared to the smallest

7

instruction sets in use today. This isn’t necessarily a good thing; a smaller number of instructions simply means you need more of them to perform meaningful computations, which is reflected by the fact that complex BF programs are typically very large in size.

8

## 3 Architecture

### 3.1 Overview

In simple terms, a BF machine consists of an array of memory-cells, together with a pointer pointing to one of these cells. The pointer can move along the array while modifying its contents one step at a time. An example of this representation in some intermediate state is shown in Figure 4. Consider the BF program “>>>>>+.”, applied to the initial conditions shown in the example. The pointer would take 5 steps to the right, landing on cell 9 which contains the number 41. It will then increment and output this value, displaying 42 on the screen (assuming a screen of some sort is used as the output device and it is displaying numbers directly rather than interpreting them as ASCII).


Figure 4: Example state of a BF machine.

The processor consists of three basic building blocks: registers, memory and a control unit. The ALU is missing from this list because the only operations that it needs to perform are addition and subtraction of the value 1, which can be done directly at the register-level when using up/down binary counters like the 74LS193 integrated circuit. The program (a sequence of BF instructions) is stored into Read Only Memory (ROM), whereas the data is stored in Random Access Memory (RAM). Instructions (4-bits) are fed from ROM into the control unit (CU) together with four flags (A, V, S and Z) that encode the state of the machine. Depending on the state and current instruction, the CU sets the appropriate control signals for each of the modules in order for the system to perform the next computation. Figure 5 shows how each of the modules is communicating with other modules. In the sections below, each of these connections will be clarified further. The actual implementation on the logic/hardware level is described in section 5.


Figure 5: Connections between modules in the BF processor.

9

### 3.2 Data Pointer Register (DP)

The data-pointer corresponds to the pointer as specified in the BF-language. It points to some value in memory beyond the stack (≥ 0x0100) and can be either incremented (moved right) or decremented (moved left) using the > and < instructions. Whenever the value pointed to by DP is modified by + or -, it is loaded into the D-register (3.3), where it can be modified before being stored back into RAM.

Inputs

The DP should be able to increment and decrement (corresponding to the < and > commands), and should be able to be enabled/disabled because of its connection to the address bus of the RAM (the Stack Pointer (SP, see 3.5, is also connected to this bus). Therefore, the DP has 3 control inputs:

- EN - Enable - when high, its value is sent to the address bus;
- INC - Increment - when high, the stored value is incremented on the next clock cycle;
- DEC - Decrement - when high, the stored value is decremented on the next clock cycle;
- R - Reset - While all other modules have the ability to be reset, this is the only module where this signal is listed as it is the only module that needs to be reset during runtime (at initialization, see 4.8).

Outputs

- DP OUT - 16 bits, connected to the address bus when enabled (EN high).

### 3.3 Data Register (D)

The data register holds a representation of the value currently pointed to by the DP and can be incremented and decremented (corresponding to + and -). This leads to a synchronization issue D and RAM, which is handled by the control unit as described in Section 4. This register provides the Z flag to indicate that its current value is 0. Among other things, this flag can be used to determine whether or not to enter a loop.

Inputs

- D IN - 8 bits - connected to the data bus;
- EN - Enable - when high, its value is sent to the data bus;
- LD - Load - when high, the data on the data bus is loaded into the register on the next clock cycle;
- INC - Increment - when high, the stored value is incremented on the next clock cycle;
- DEC - Decrement - when high, the stored value is decremented on the next clock cycle.

Outputs

- D OUT - 8 bits - connected to the data bus;
- Z - Zero Flag - high when the register contains all zero’s (0x00).

### 3.4 Instruction Pointer Register (IP)

The IP Register stores the instruction pointer (16-bits), which keeps track of the instruction that is currently being executed. It points to a certain address in ROM (which stores the program) and is usually incremented after each instruction has finished executing, in order to move to the next instruction. However, when the processor encounters the [-instruction (and a loop is entered), its value is stored in RAM at the location pointed to by the stack pointer (SP, see 3.5). When the matching ]-instruction is encountered, this value can be loaded back into the IP in order to jump back to the start of the loop if needed.

10

Inputs

- IP IN - 16 bits - connected to the data bus (for loading a stored address off the stack);
- EN - Enable - when high, its value is sent to the databus (for storing an address on the stack);
- LD - Load - when high, the value on the databus is loaded into the register on the next clock cycle;
- INC - Increment - when high, the stored value is incremented on the next clock cycle.

Outputs

- IP OUT - 16 bits - connected to the Data Bus and the address inputs of program-ROM;

### 3.5 Stack Pointer Register (SP)

The stack is the first part of RAM (addresses 0x0000 - 0x00ff) and is reserved to keep track of addresses that might need to be jumped to. The stack-pointer (SP) points to an address in this space; it is incremented whenever a new value is pushed to the stack and decremented whenever a value is popped off the stack. In this implementation, the SP is an 8-bit value, which means that at most 256 different values can be stored onto the stack before it the SP overflows (wraps around back to 0) and starts overwriting previous values. This would happen if a BF program was loaded that has more than 256 nested []-pairs. Although possible, it is very unlikely to happen for the simple programs we intend to run.

Inputs

- EN - Enable - when high, its value is sent to the address bus;
- INC - Increment - when high, the stored value is incremented on the next clock cycle;
- DEC - Decrement - when high, the stored value is decremented on the next clock cycle.

Outputs

- SP OUT - 8 bits - connected to the address bus of RAM.

### 3.6 Loop Skip Register (LS)

The Loop Skip (LS) register is a counter that indicates whether or not we’re in the process of skipping a loop. In BF, a loop ([) is only entered when the value currently pointed to is nonzero. In the case that it is zero, execution resumes beyond its matching ]. When it is determined that a loop must be skipped (based on the Z-flag of the D-register), the LS register is incremented from 0 to 1 and the S-flag is set.. Subsequent instructions are then skipped until either another (nested) loop opening [ or a closing ] is encountered. On the former, the LS is incremented again while on the latter the LS is decremented. This has the effect that the LS becomes 0 again after the ] that matches the original [ which led to the skip. Normal execution occurs as soon as LS has become 0 again and the S-flag is reset back to 0.

Inputs

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

Outputs

- S - Skip flag - set when it value is nonzero.

11
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

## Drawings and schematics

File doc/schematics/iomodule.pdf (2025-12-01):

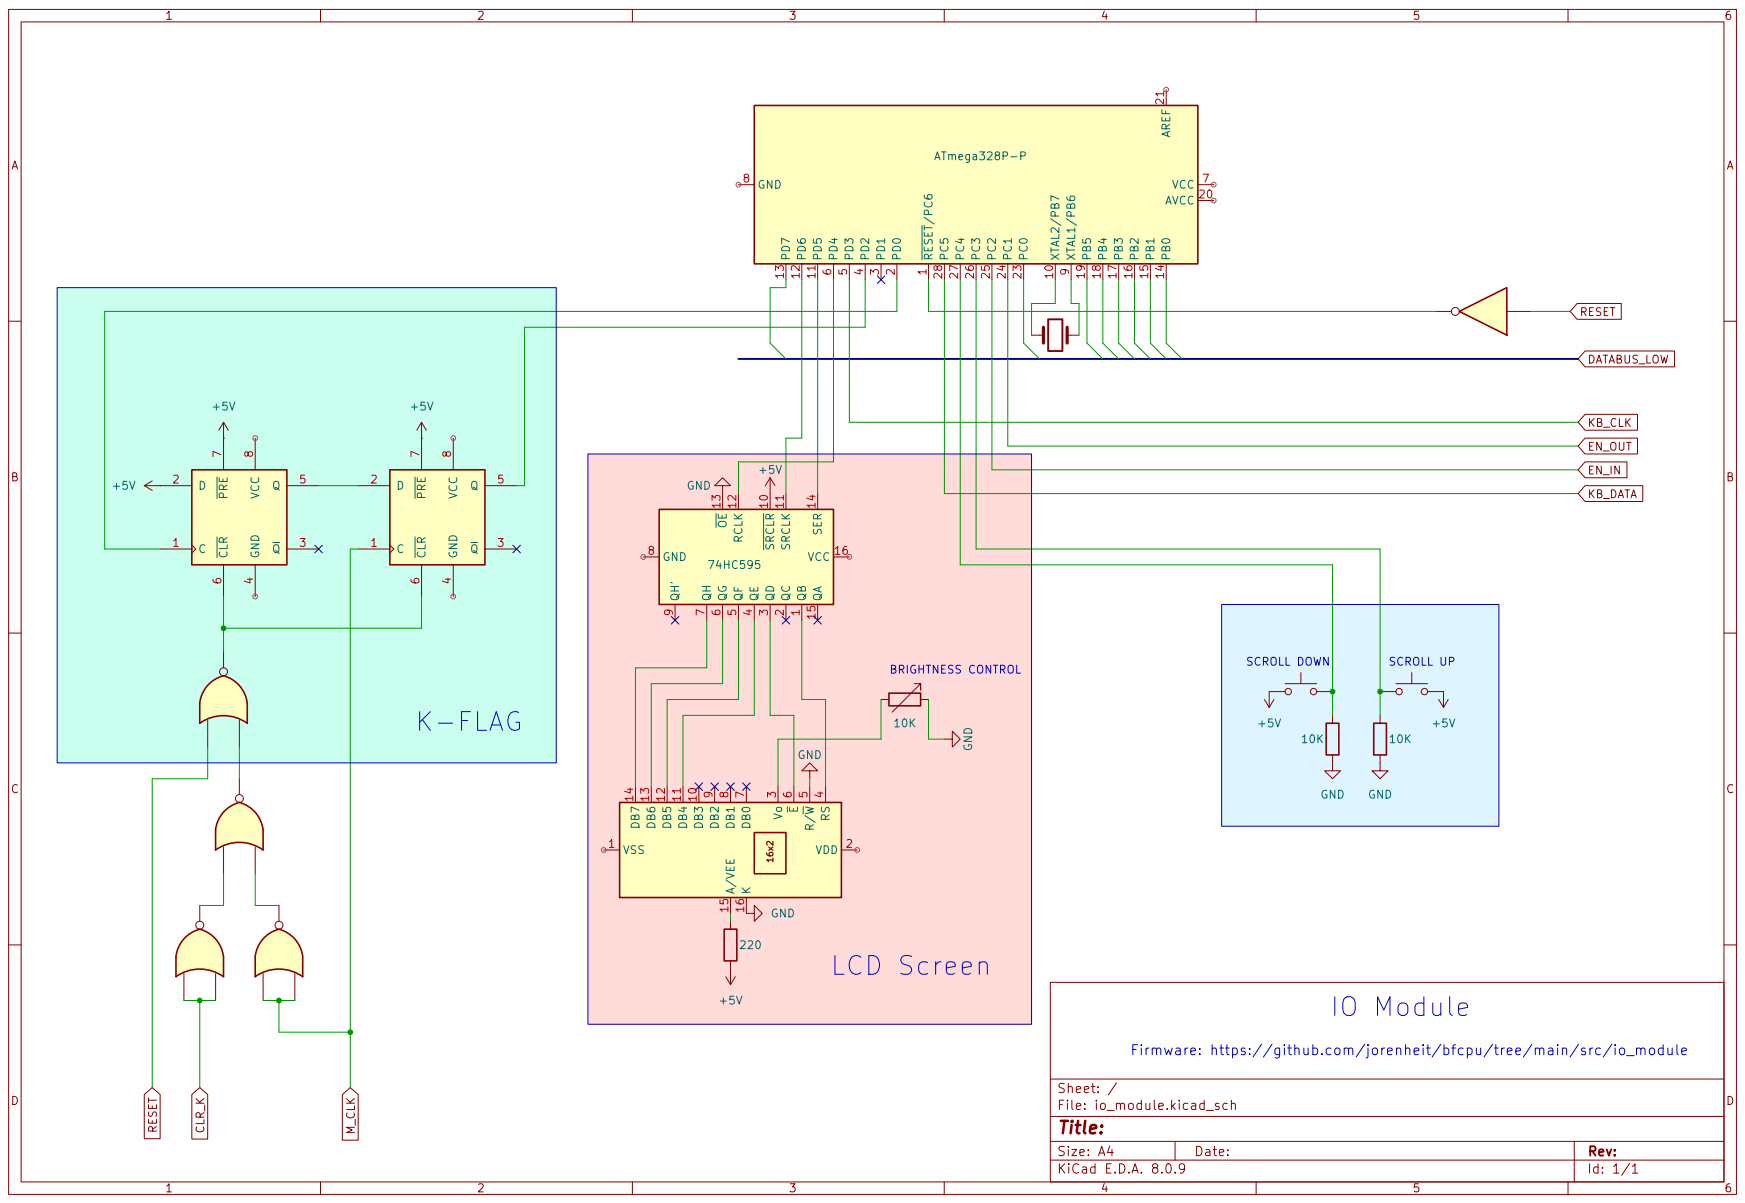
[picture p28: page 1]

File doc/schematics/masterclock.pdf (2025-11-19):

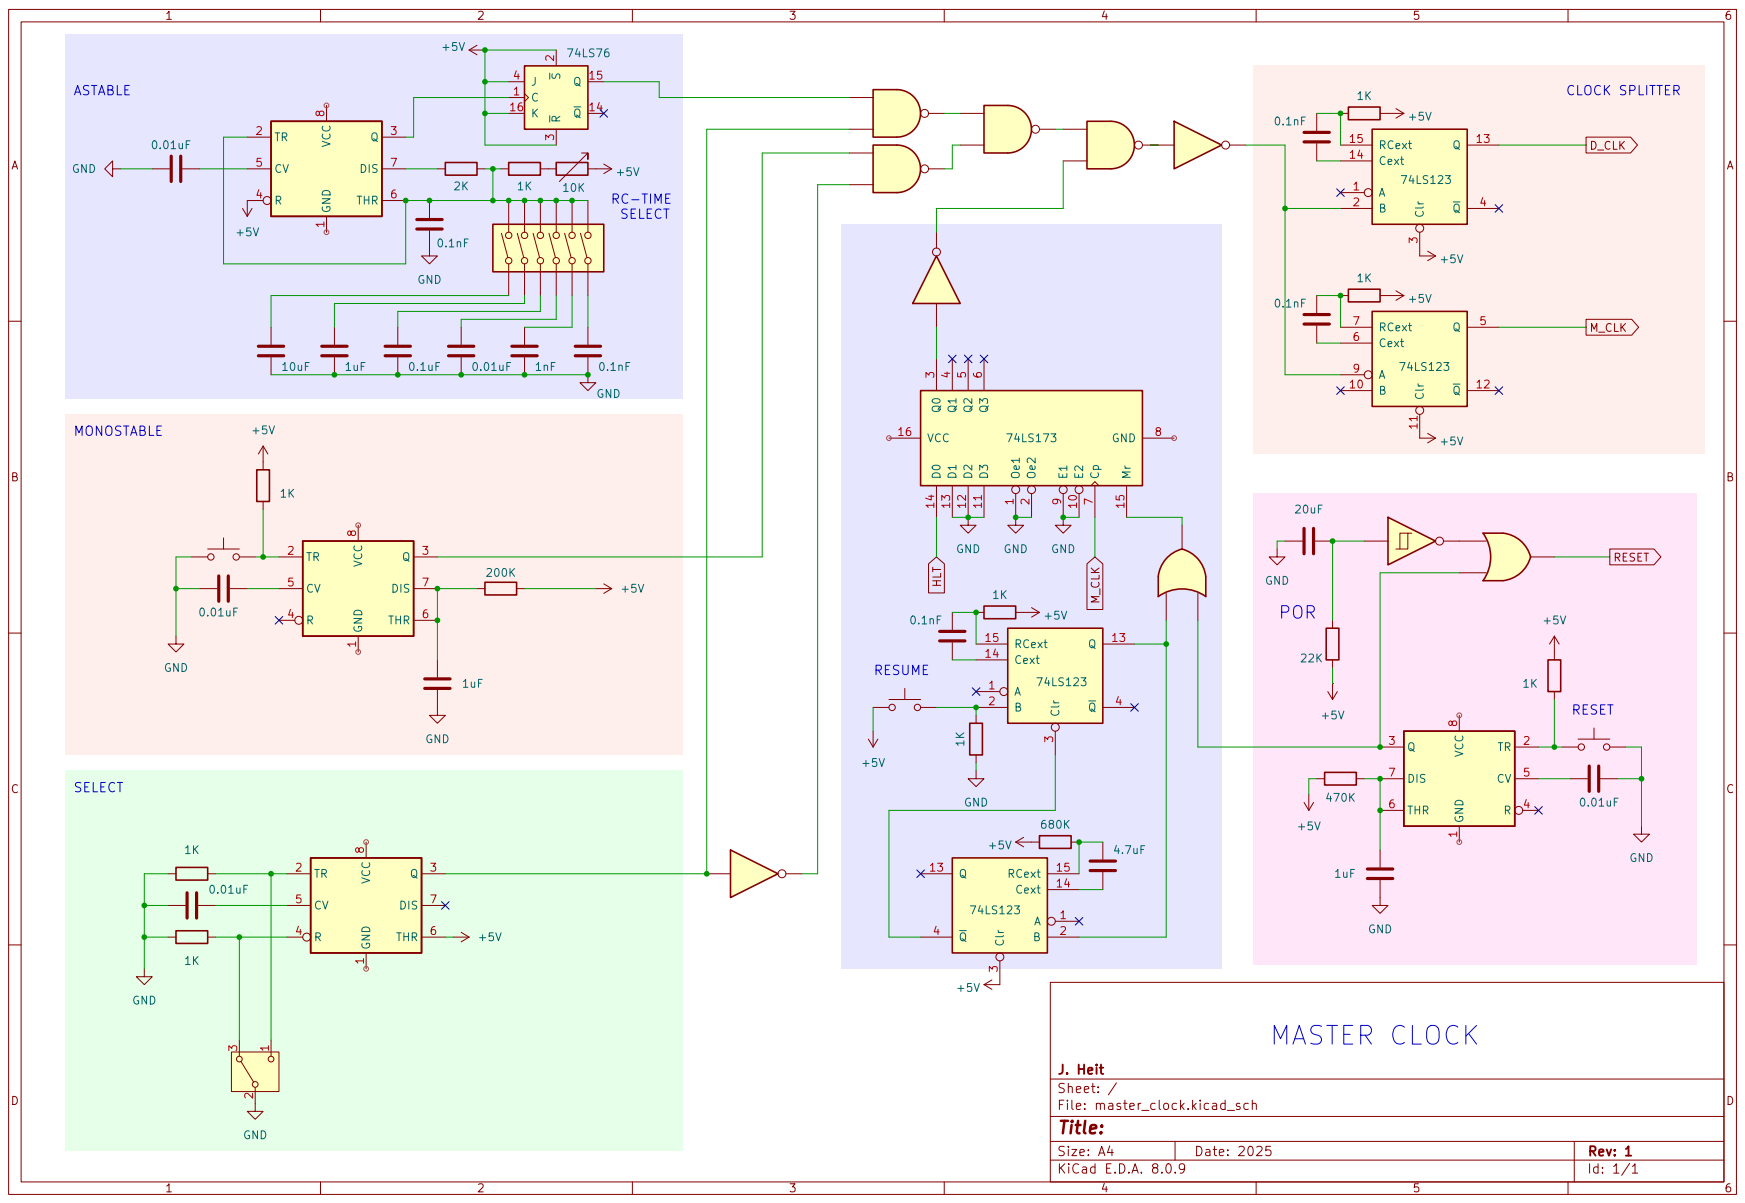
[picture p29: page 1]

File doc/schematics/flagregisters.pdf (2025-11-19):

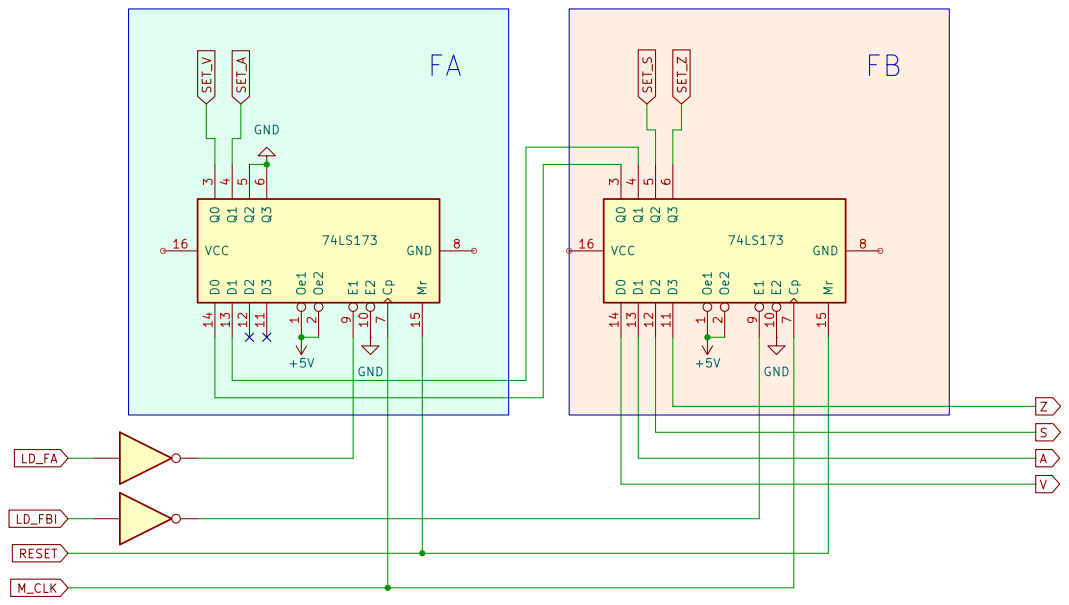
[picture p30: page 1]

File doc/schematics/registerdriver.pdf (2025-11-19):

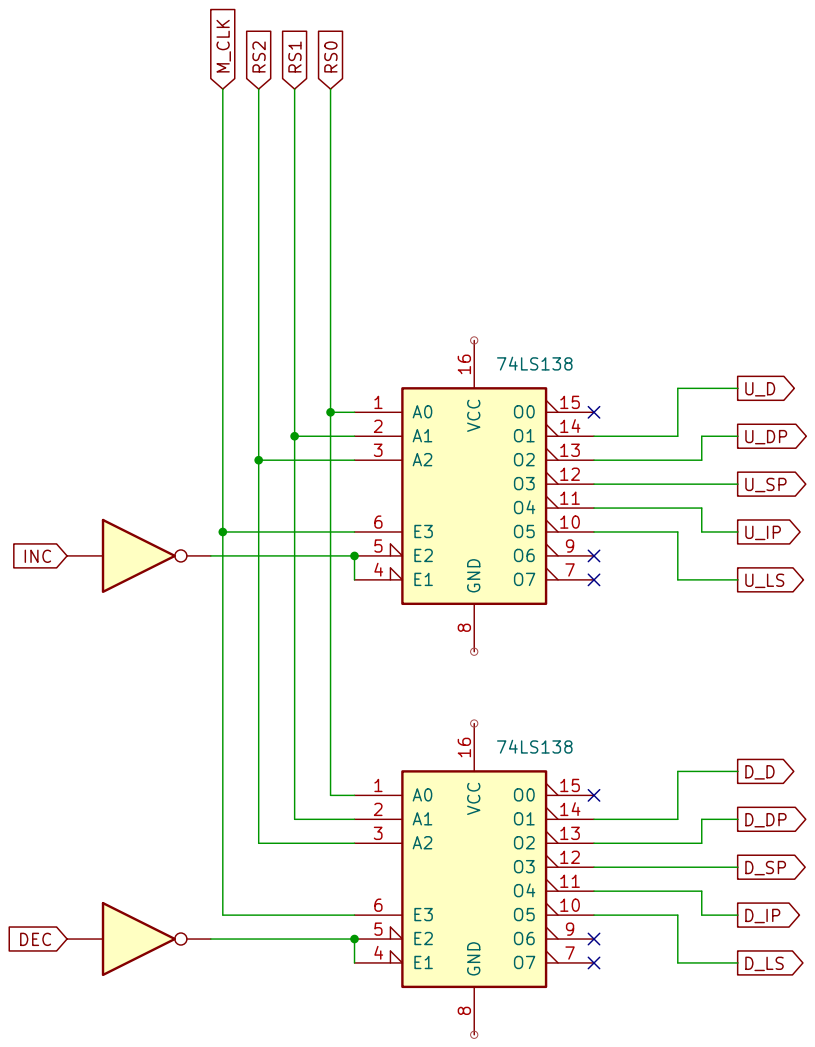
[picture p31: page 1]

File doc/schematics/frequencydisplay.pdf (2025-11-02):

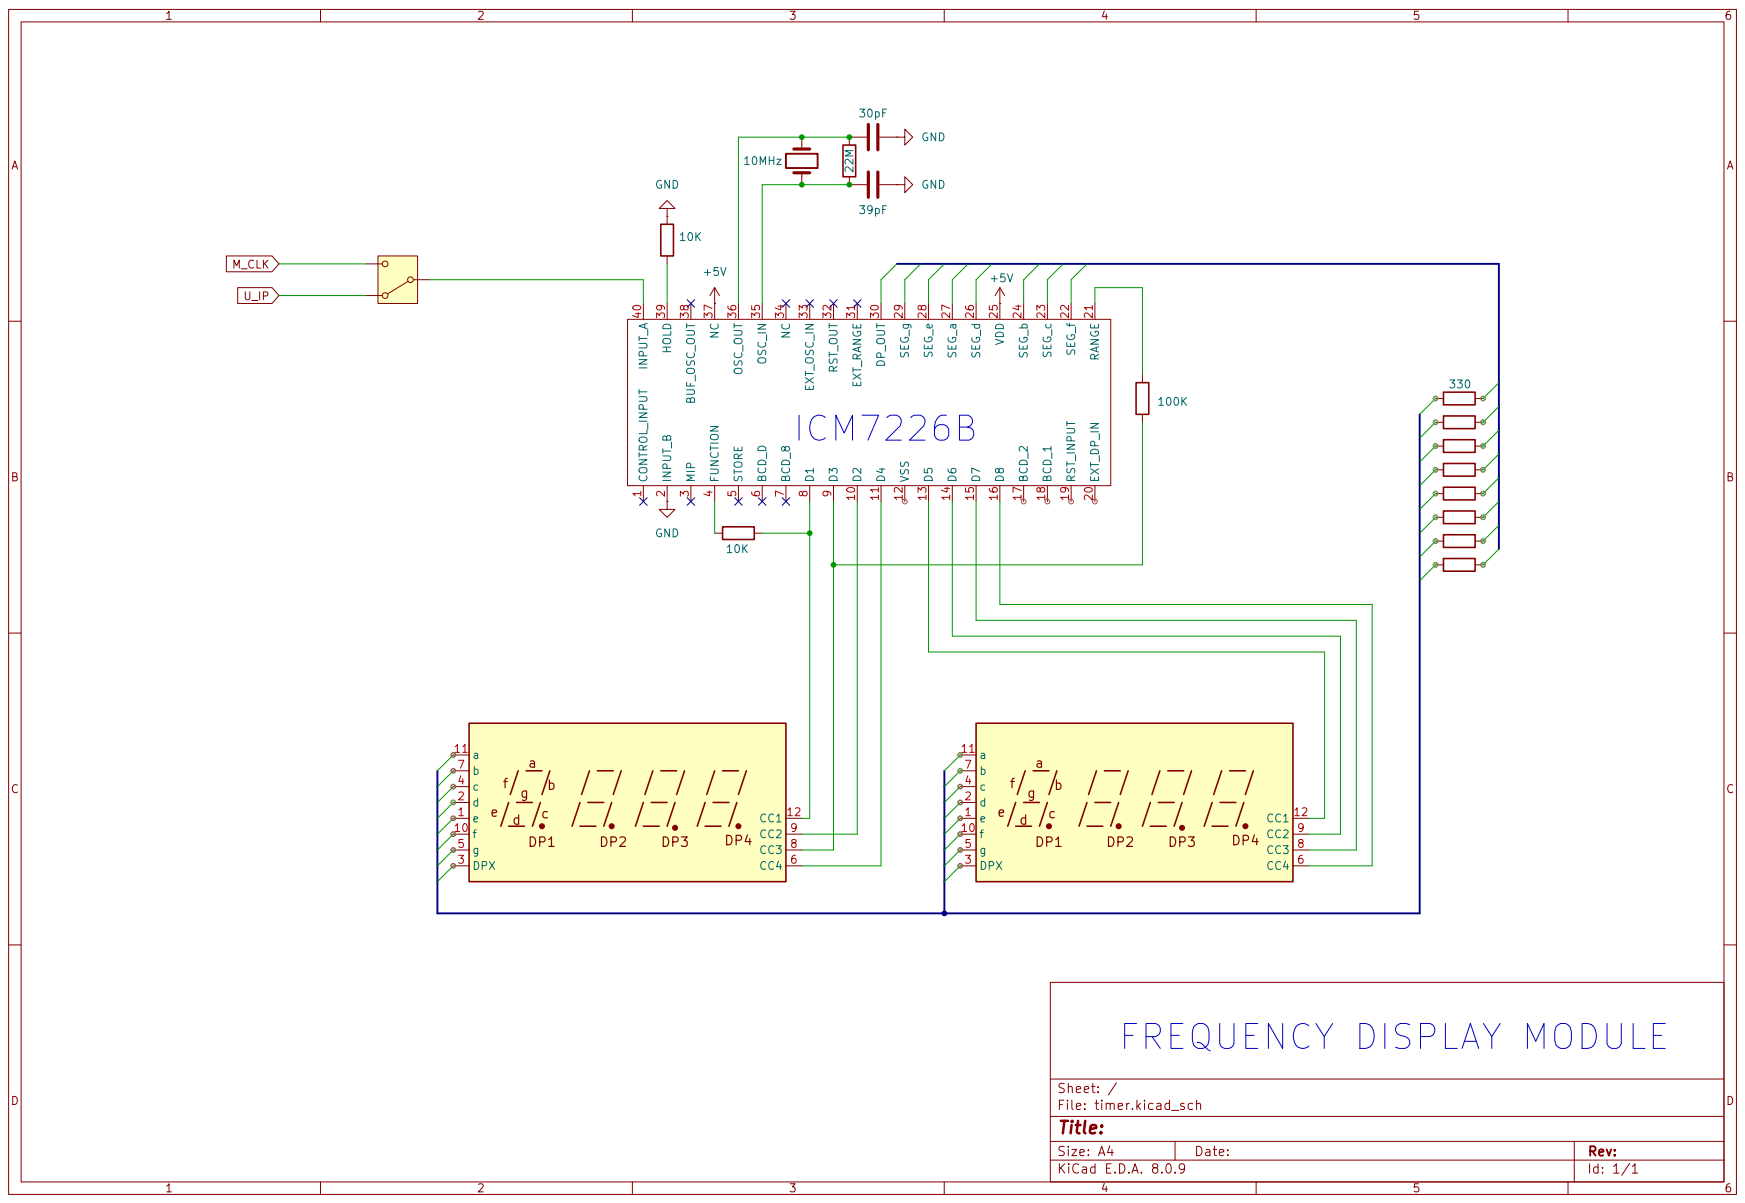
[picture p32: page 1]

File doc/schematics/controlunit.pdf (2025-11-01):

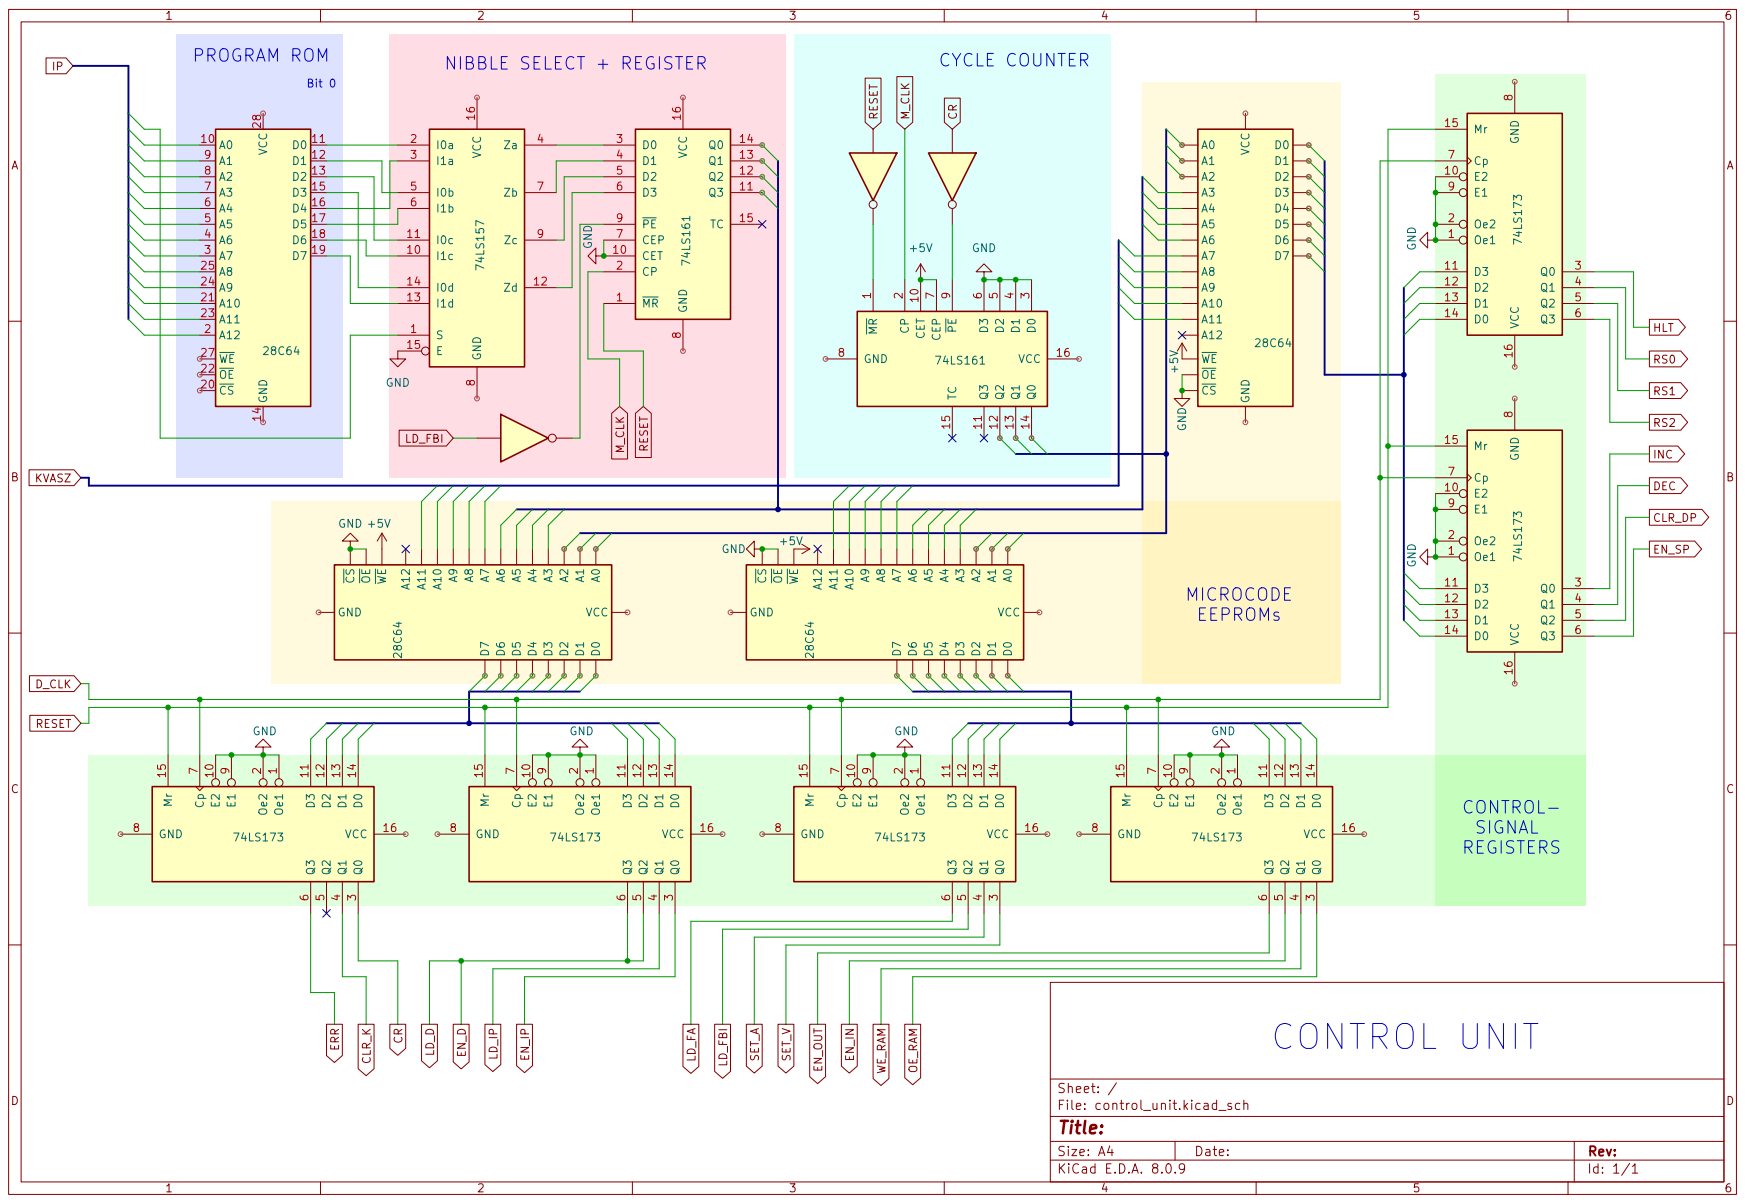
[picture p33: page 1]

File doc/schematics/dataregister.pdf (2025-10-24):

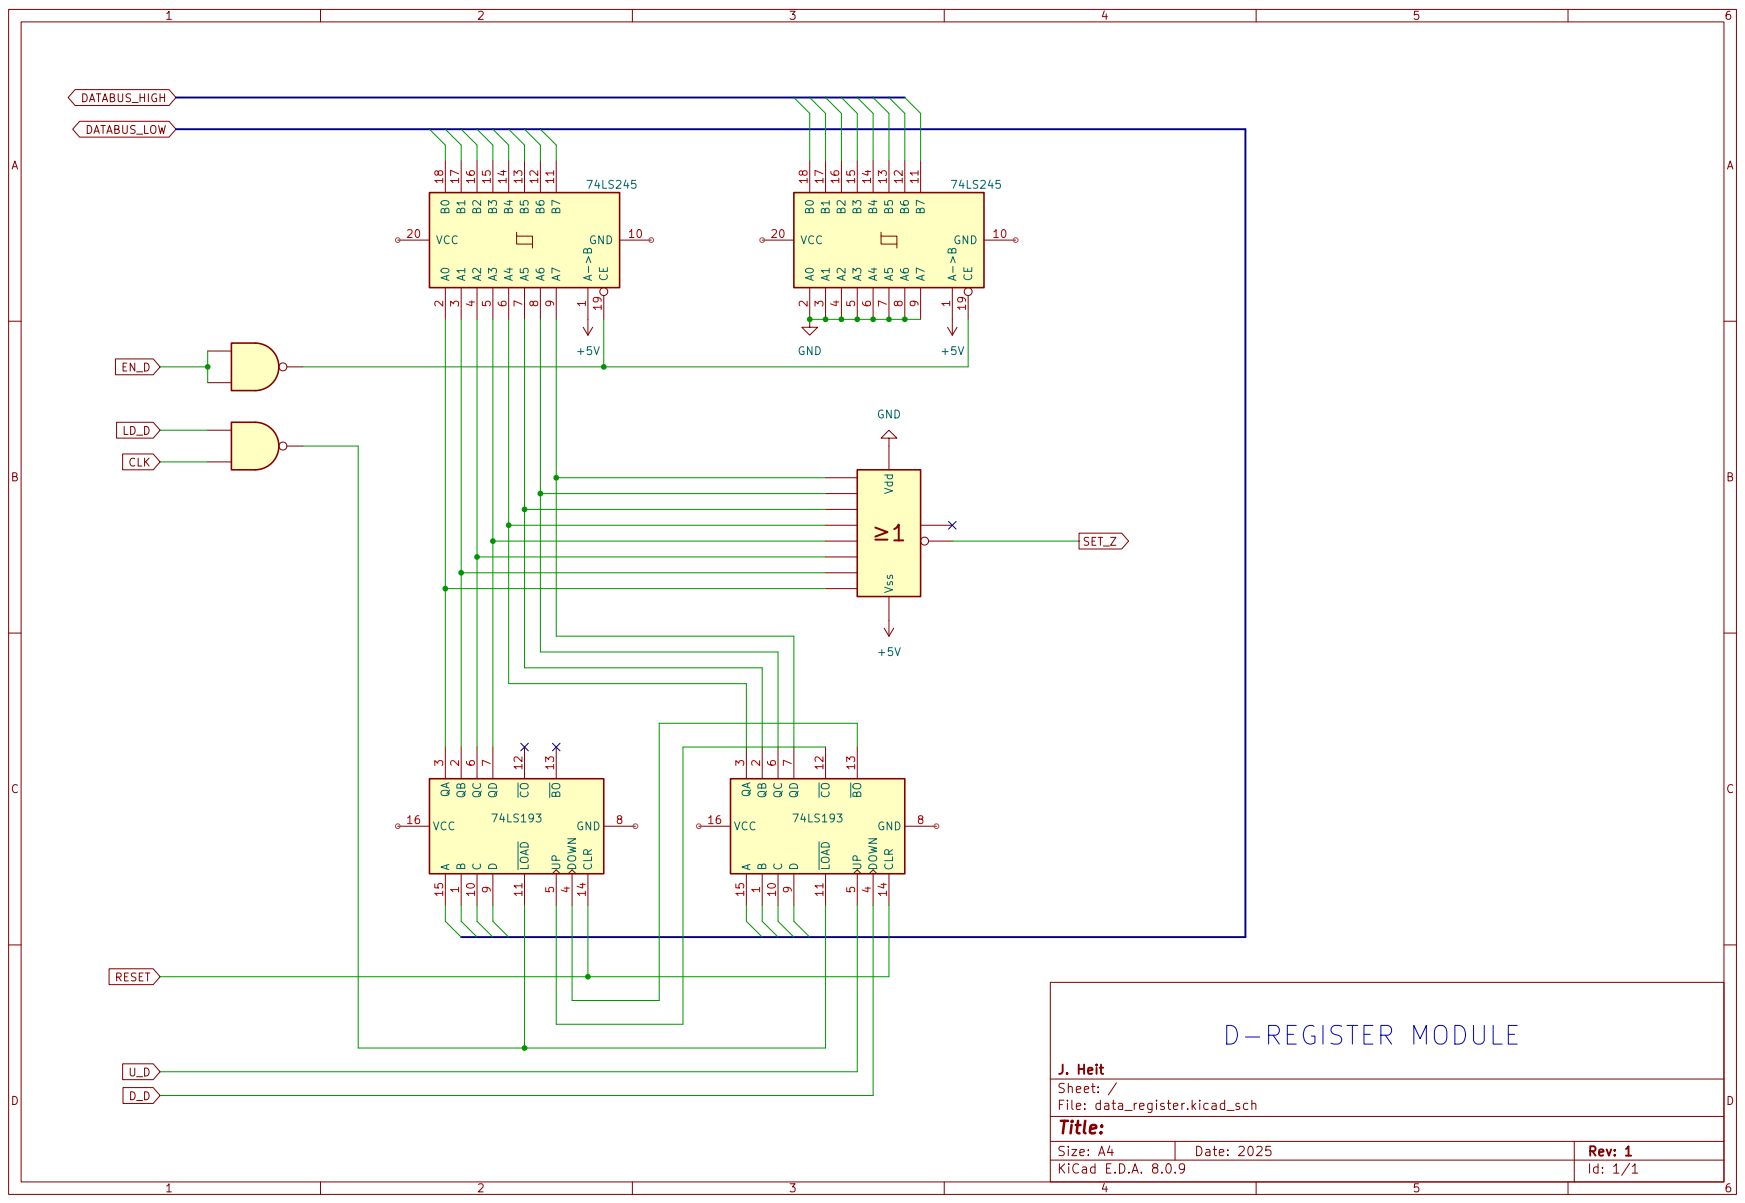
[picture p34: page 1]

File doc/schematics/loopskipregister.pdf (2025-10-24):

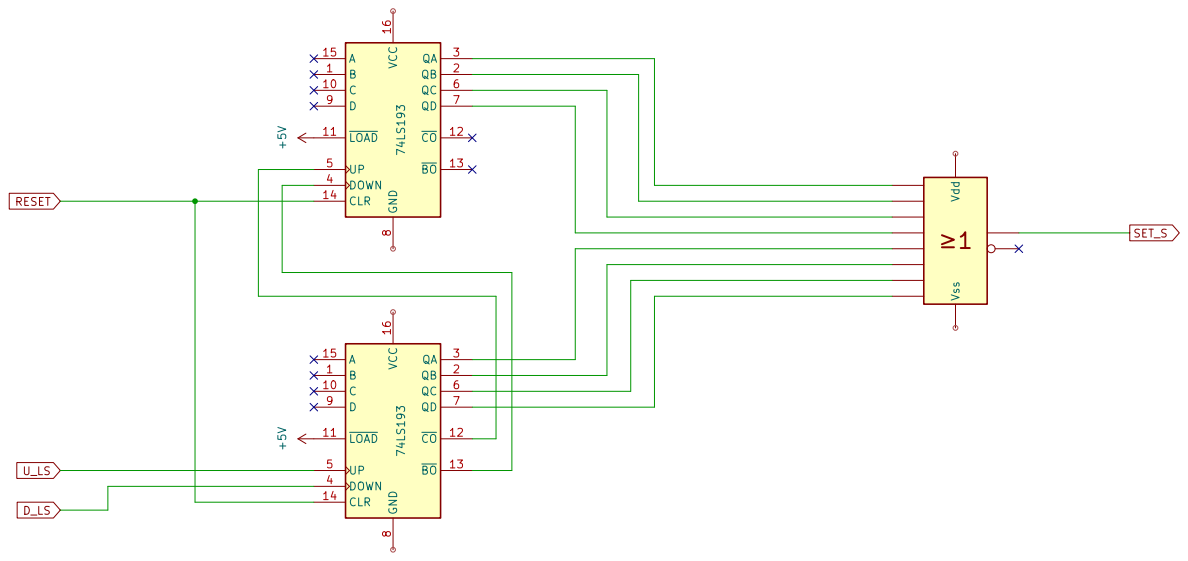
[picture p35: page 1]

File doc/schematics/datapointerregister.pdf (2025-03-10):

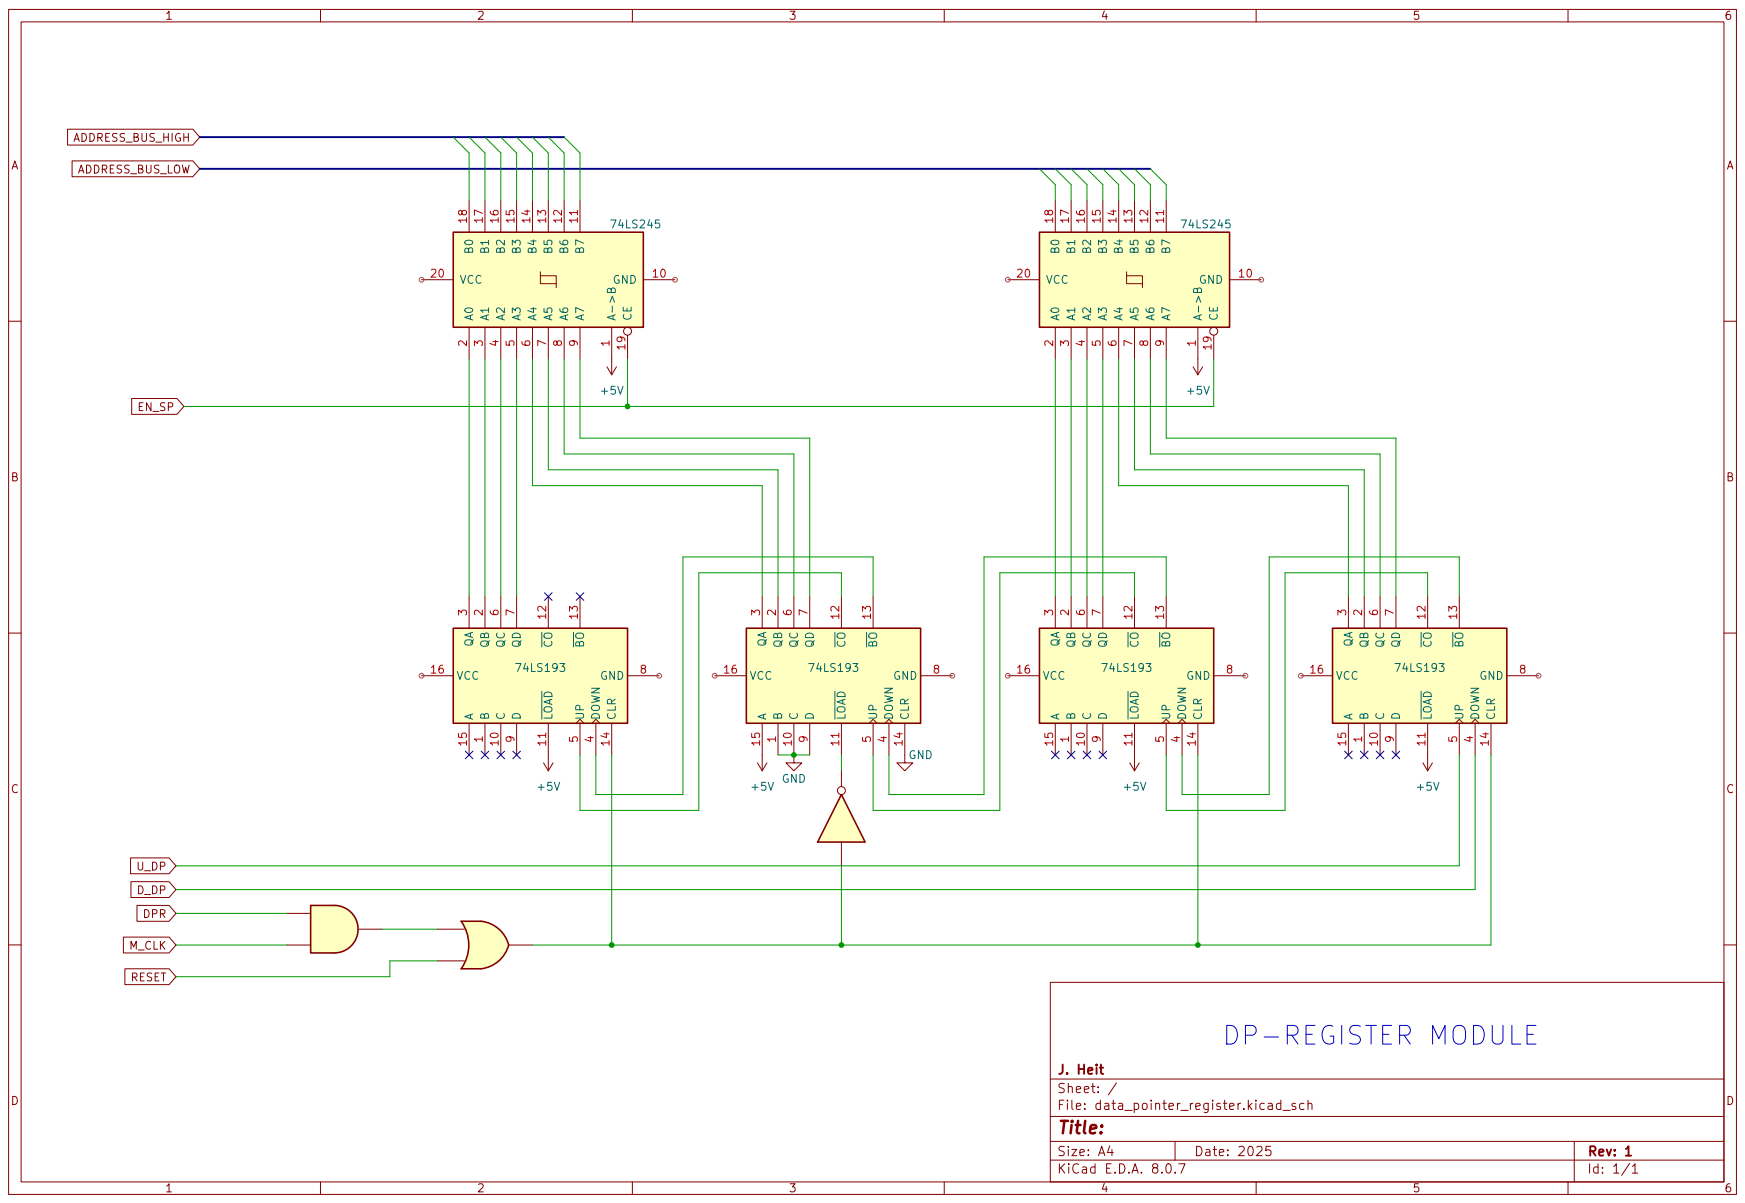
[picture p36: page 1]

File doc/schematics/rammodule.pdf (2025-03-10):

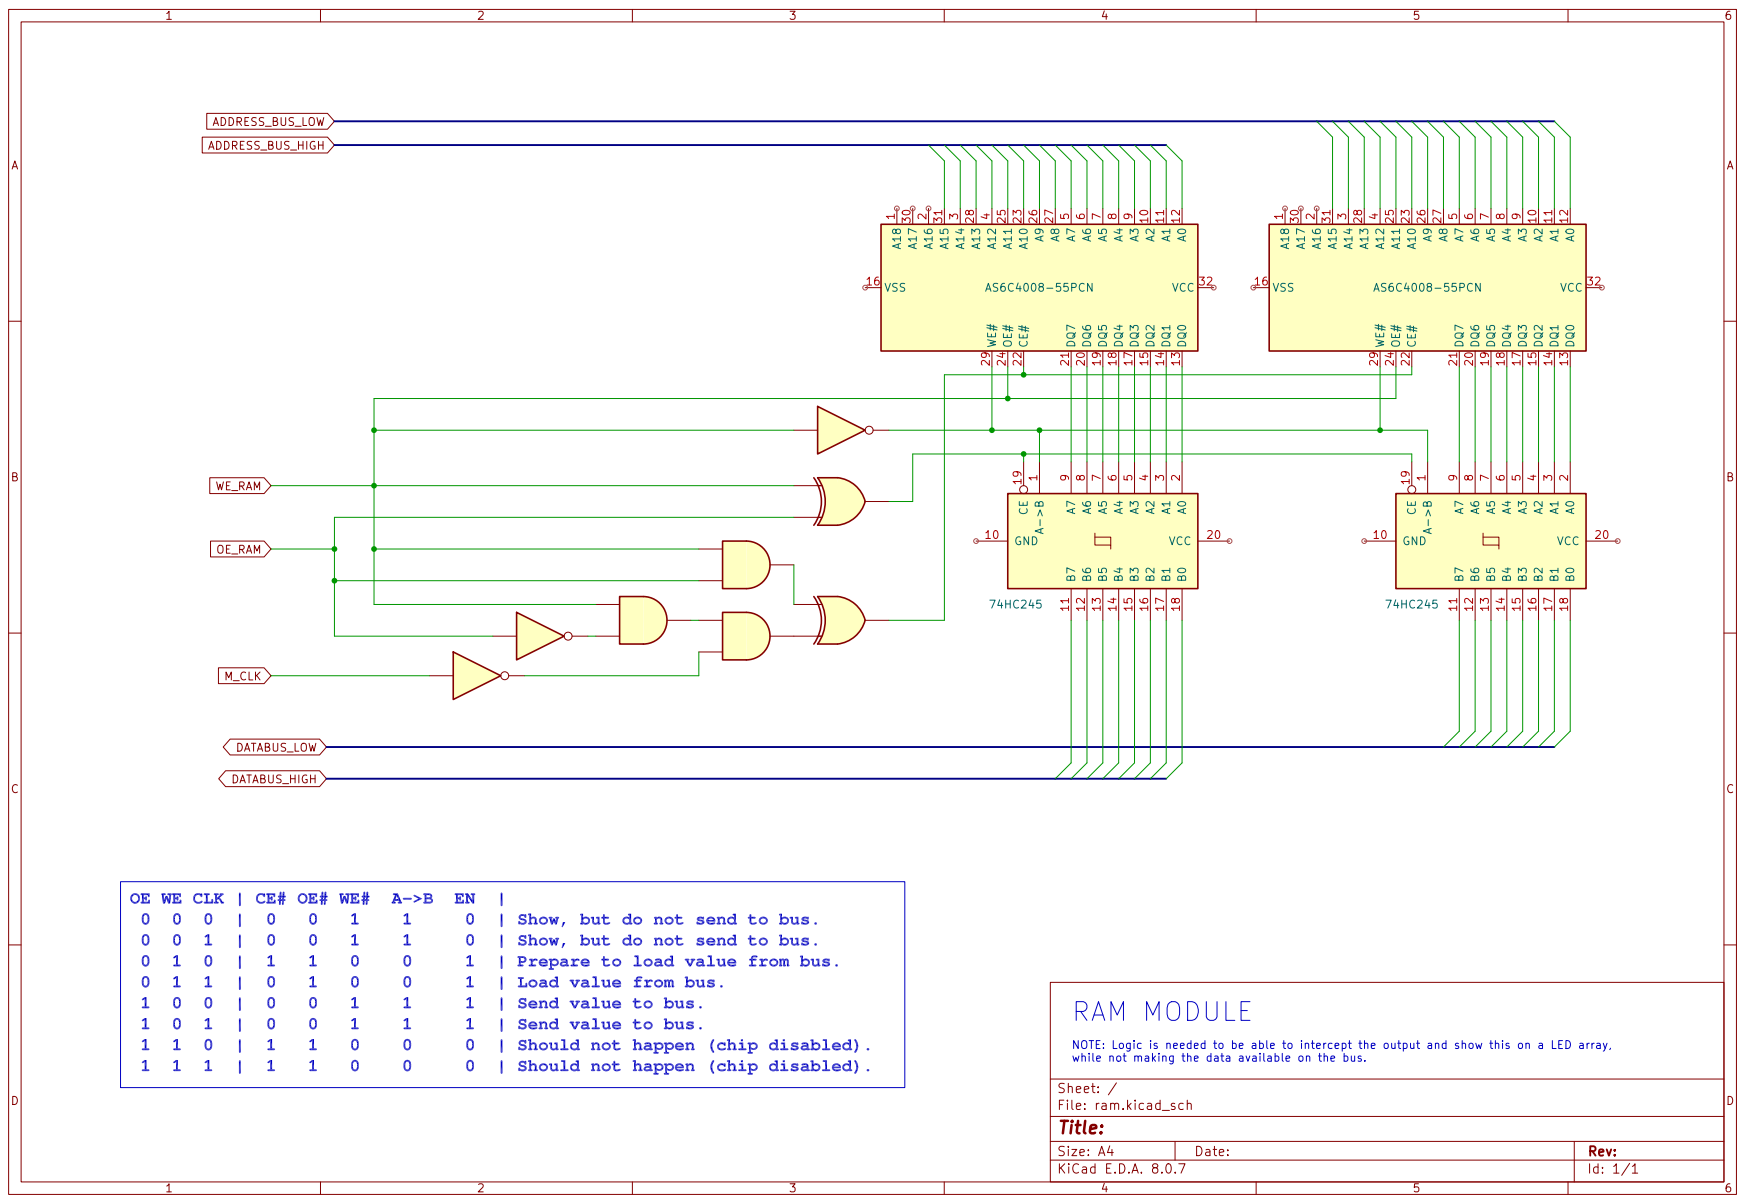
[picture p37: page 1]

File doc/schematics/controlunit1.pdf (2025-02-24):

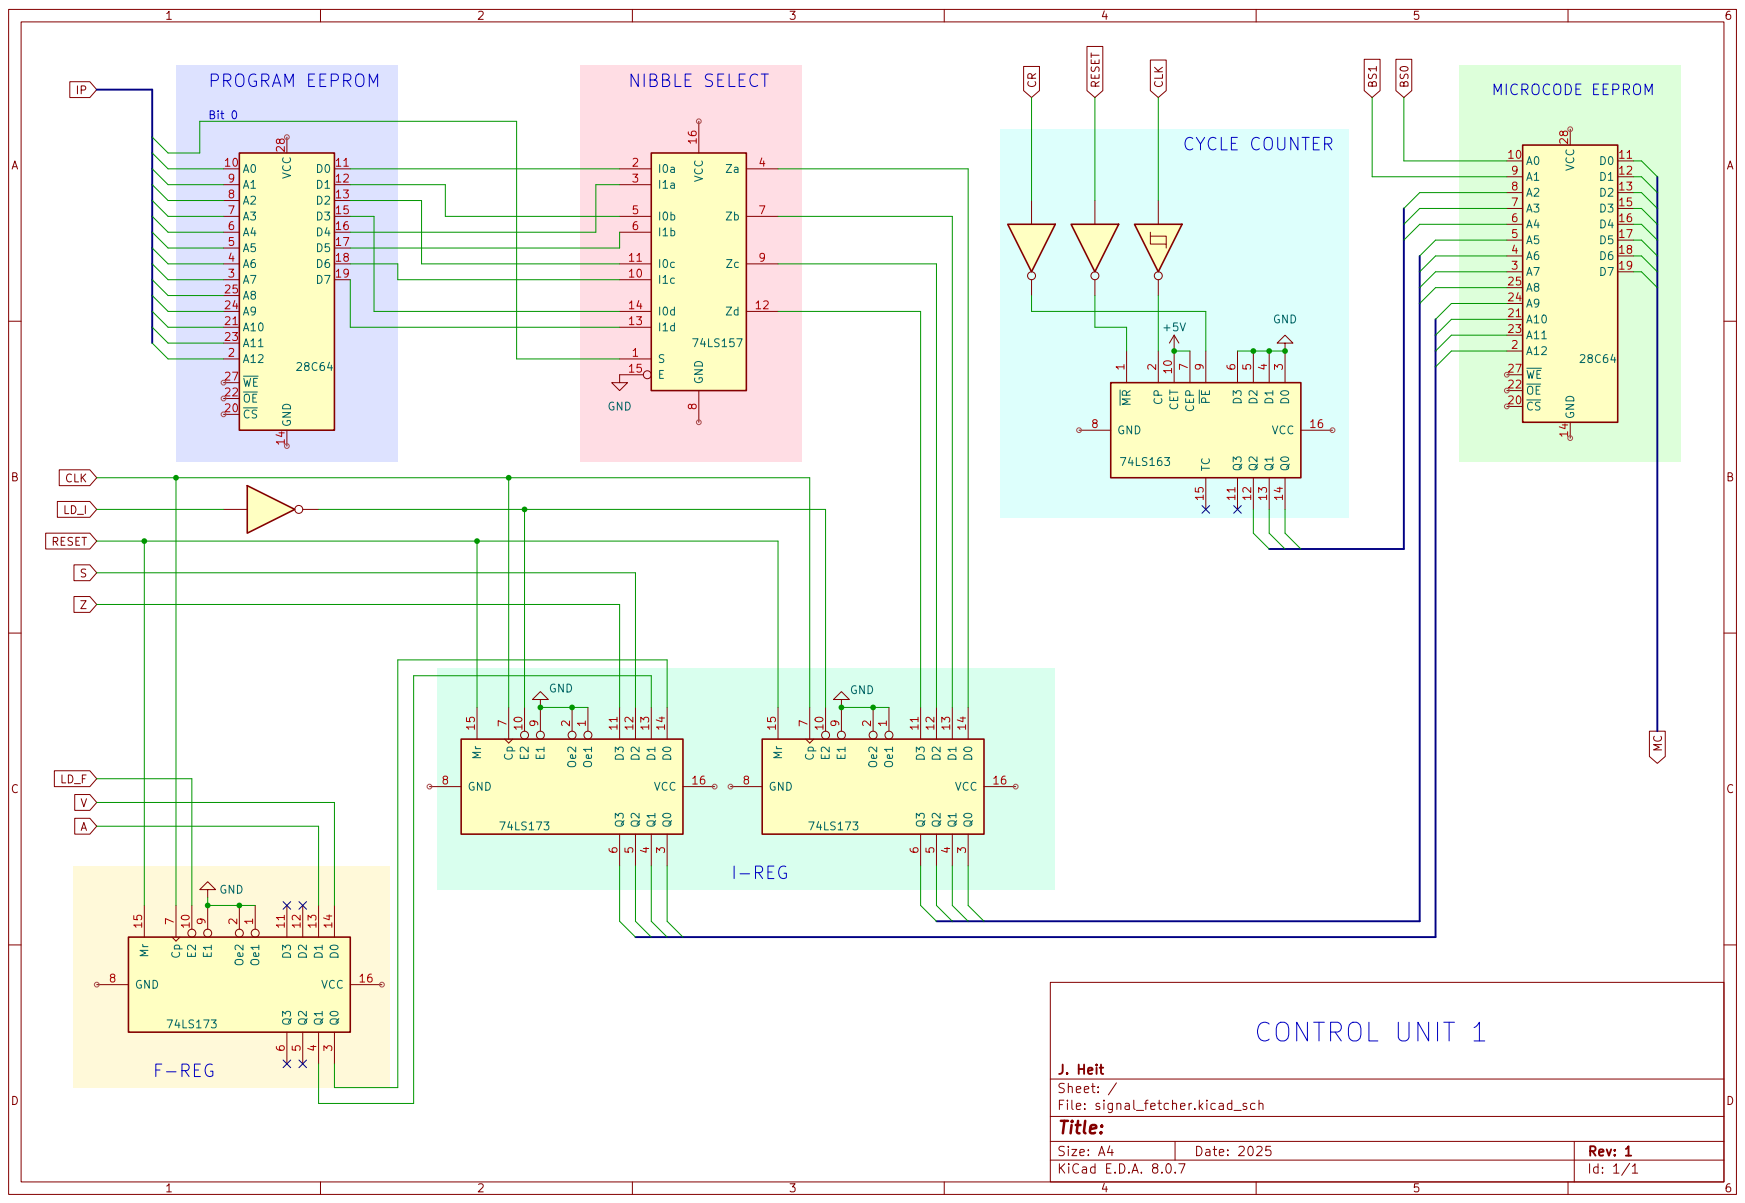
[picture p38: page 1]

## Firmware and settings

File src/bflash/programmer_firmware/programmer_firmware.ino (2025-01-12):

#define MAX_ROM_SIZE (1 << 13)
#define BAUD_RATE 115200
#define CHUNK_SIZE 50

enum Pins {
  SHIFT_DATA = 13,  // SER (pin 14)
  SHIFT_LATCH = 11, // RCLK (pin 12)
  SHIFT_CLOCK = 12, // SRCLK (pin 11)
  SHIFT_OE = A0,
  
  CE = 2,

  STATUS_LED = A1,
};

int IO_PINS[8] = {
  3, 4, 5, 6, 7, 8, 9, 10
};

enum ReadWrite {
  READ,
  WRITE,
  NONE
};

enum Signals {
  DUMP_REQUEST = 0,
  FLASH_REQUEST = 1,
  PROGRAMMER_READY = 2,
  PROGRAMMER_FINISHED = 3
};

void setShiftRegisters(int const addr, ReadWrite const RW) {
  //      |   Shift Register 1 (msb)  |  Shift Register 0 (lsb) |
  // Bit: | 15 14 13  12  11 10 09 08 | 07 06 05 04 03 02 01 00 |
  //      | OE WE -- A12 A11  ...  A8 | A7 ...           ... A0 |
  //        SHIFT DIRECTION -->    -->   -->


  // Disable output
  digitalWrite(SHIFT_OE, HIGH);

  // Set bits 13, 14, 15 (OR with 0xE000 = 0b1110...0) and clear either bit 14 or 15 depending 
  // on if we're reading or writing:
  int value16 = (addr | 0xE000);
  if (RW != NONE) {
    value16 &= (RW == WRITE) ? ~(1 << 14) : ~(1 << 15);
  }

  shiftOut(SHIFT_DATA, SHIFT_CLOCK, LSBFIRST, (value16 >> 0) & 0xff); 
  shiftOut(SHIFT_DATA, SHIFT_CLOCK, LSBFIRST, (value16 >> 8) & 0xff);

  // Latch result onto the pins
  digitalWrite(SHIFT_LATCH, LOW);
  delayMicroseconds(10);
  digitalWrite(SHIFT_LATCH, HIGH);
  delayMicroseconds(10);
  digitalWrite(SHIFT_LATCH, LOW);

  // Enable output
  digitalWrite(SHIFT_OE, LOW);
  delay(1);
}

void setOutput(byte const value) {
  setIOPinsAs(OUTPUT);
  for (int i = 0; i != 8; ++i) {
    int const state = (value >> i) & 1 ? HIGH : LOW;
    digitalWrite(IO_PINS[i], state);
  }
}

void setIOPinsAs(int mode) {
  for (int i = 0; i != 8; ++i) {
    pinMode(IO_PINS[i], mode);
  }
}

void enableEEPROM() {
  digitalWrite(CE, LOW);
}

void disableEEPROM() {
  digitalWrite(CE, HIGH);
}

byte readEEPROM(int addr) {
  // Make {address, OE = 1, WE = 0} available on pins of the EEPROM
  setIOPinsAs(INPUT);
  disableEEPROM();
  setShiftRegisters(addr, READ);
  enableEEPROM();

  // Read data into return variable 
  byte data = 0;
  for (int i = 0; i != 8; ++i) {
    data |= (digitalRead(IO_PINS[i]) << i);
  }

  disableEEPROM();
  return data;
}

void writeEEPROM(int addr, byte value) {

  // Make sure EEPROM is disabled while setting the outputs of the arduino
  disableEEPROM();

  // set output to value
  setOutput(value);

  // Make {address, OE = 1, WE = 0} available on pins of the EEPROM (OE and WE are active low)
  setShiftRegisters(addr, WRITE);

  // Pulse CE of the EEPROM to write the value into it
  enableEEPROM();
  delayMicroseconds(1); // CE needs to be held low at least 100ns
  disableEEPROM();
  delay(10); // It needs a rather big delay... if not, subsequent writes do not work for some reason.

  // set IO back to input to prevent accidental writes
  setIOPinsAs(INPUT);
}

void showPercentage(int p) {
      Serial.print("PROGRAMMER: ");
      Serial.print(p);
      Serial.println("%");
}

int showPercentage(float current, float total, int previous) {
    int newPercentage = current / total * 100;
    if (newPercentage - previous >= 5) {
      showPercentage(newPercentage);
      return newPercentage;
    }
    return previous;
}

void flash() {
  Serial.println("PROGRAMMER: Waiting for data transfer");
  while (!Serial.available()) {} // wait
  digitalWrite(STATUS_LED, LOW);
  Serial.println("PROGRAMMER: Receiving data ...");

  uint32_t dataLength = 0;
  Serial.readBytes(reinterpret_cast<byte*>(&dataLength), 4);
  dataLength = (dataLength <= MAX_ROM_SIZE) ? dataLength : MAX_ROM_SIZE;

  Serial.print("PROGRAMMER: writing ");
  Serial.print(dataLength);
  Serial.println(" bytes to EEPROM");

  int percentage = 0;
  int chunks = dataLength / CHUNK_SIZE + (dataLength % CHUNK_SIZE != 0);
  byte chunkBuffer[CHUNK_SIZE]{};
  int bytesRead = 0;
  for (int i = 0; i != chunks; ++i) {
    size_t n = (dataLength - bytesRead > CHUNK_SIZE) ? CHUNK_SIZE : (dataLength - bytesRead);
    Serial.readBytes(chunkBuffer, n);
    for (int j = 0; j != n; ++j) {
      writeEEPROM(i * CHUNK_SIZE + j, chunkBuffer[j]);
      percentage = showPercentage(bytesRead, dataLength, percentage);      
    }
    Serial.write(PROGRAMMER_READY);
    bytesRead += n;
  }
}

void dump() {
  digitalWrite(STATUS_LED, LOW);
  static constexpr uint32_t dataLength = MAX_ROM_SIZE;
  Serial.write(reinterpret_cast<byte const*>(&dataLength), sizeof(dataLength));
  for (int i = 0; i != MAX_ROM_SIZE; ++i) {
    byte b = readEEPROM(i);
    Serial.write(b);
  }
}

void setup() {
  pinMode(SHIFT_DATA, OUTPUT);
  pinMode(SHIFT_LATCH, OUTPUT);
  pinMode(SHIFT_CLOCK, OUTPUT);
  pinMode(SHIFT_OE, OUTPUT);
  setShiftRegisters(0, NONE); // make sure we're not accidentally writing, before setting the pinmode of CE to output
  pinMode(CE, OUTPUT);
  disableEEPROM();
  pinMode(STATUS_LED, OUTPUT);

  Serial.begin(BAUD_RATE);
  Serial.write(PROGRAMMER_READY); // let computer know we're ready
  digitalWrite(STATUS_LED, HIGH);

  while (true) { 
    byte c = Serial.read();
    if (c == DUMP_REQUEST) {
      dump(); 
      break;
    }
    else if (c == FLASH_REQUEST) {
      flash();
      break;
    }
  }

  Serial.write(PROGRAMMER_FINISHED);
  setIOPinsAs(INPUT);
  setShiftRegisters(0, NONE);
  disableEEPROM();
}

void loop() {
  // Blink to indicate done/idle
  digitalWrite(STATUS_LED, HIGH);
  delay(500);
  digitalWrite(STATUS_LED, LOW);
  delay(500);
}

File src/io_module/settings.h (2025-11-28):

#pragma once

// ============================  Static Settings ================================= //

enum LCDDriverPins: uint8_t {
  // Connections from Shift Register to Arduino
  SH_CP = 6, // SRCLK
  DS    = 5, // SER
  ST_CP = 4, // RCLK

  // Connections from LCD panel to Shift Register
  RS_595 = 1,
  E_595  = 3,
  D0_595 = 4,
  D1_595 = 5,
  D2_595 = 6,
  D3_595 = 7
};

enum ModuleDriverPins: uint8_t {
  K_OUT_PIN = 0,
  K_IN_PIN = 2,
  //SYSTEM_CLOCK_INTERRUPT_PIN = 2,
  KEYBOARD_CLOCK_INTERRUPT_PIN = 3,
  DISPLAY_ENABLE_PIN = A1,
  KEYBOARD_ENABLE_PIN = A2,
  SCROLL_UP_PIN = A3,
  SCROLL_DOWN_PIN = A4,
  KEYBOARD_DATA_PIN = A5

/*
  // Data Pins (not used directly but here for documentation purposes):
  D0 = 7,
  D1 = 8,
  D2 = 9,
  D3 = 10,
  D4 = 11, 
  D5 = 12,
  D6 = 13,
  D7 = A0
*/
};

enum DisplayMode: uint8_t {
  ASCII,
  DECIMAL,
  HEXADECIMAL,
  N_MODES
};

enum InputMode: uint8_t {
  BUFFERED,
  IMMEDIATE
};

enum ButtonPrams: int {
  BUTTON_DEBOUNCE_DELAY = 200,
  BUTTON_HOLD_TIME = 1000
};

enum RNGParams: int {
  RNG_DEFAULT_SEED = 69,
  RNG_MIN_SEED = 0,
  RNG_MAX_SEED = 100
};

enum ProgramSlots: uint8_t {
  N_SLOTS = 10
};

enum LCDParams: int {
  VISIBLE_LINES = 4,
  LINE_SIZE = 20,
  TOTAL_LINES = 20,
  TAB_WIDTH = 4,
  NO_SCROLL_DELAY = 200,
  BOOT_MESSAGE_DELAY = 500,
  MENU_TIMEOUT = 5000,
  TEMP_MESSAGE_TIMEOUT = 1000,
  MENU_SELECT_CHARACTER = 0x7E, // rightarrow
  MENU_LABEL_OFFSET = 2,
  LCD_COMMAND_EXECUTION_MICROS = 40,
  DISPLAY_FPS = 10,
  DISPLAY_FRAMETIME_MILLIS = 1000 / DISPLAY_FPS,

  AUTOSCROLL_DEFAULT_SETTING = true,
  ECHO_DEFAULT_SETTING = true,
  DISPLAY_MODE_DEFAULT_SETTING = ASCII,
  INPUT_MODE_DEFAULT_SETTING = BUFFERED,
  DELIMITER_DEFAULT_SETTING = ','
};

enum FrequencyParams: int { 
  // Frequency Measurements
  FREQUENCY_TIMEOUT = 2000,          // How many ms the frequency stays displayed after buttons released.
  FREQUENCY_UPDATE_INTERVAL = 1000,  // How many ms have to pass before a new frequency is measured.
  FREQUENCY_MEASUREMENT_TIME = 500,  // How many ms the ticks are sampled to calculate the frequency.
  FREQUENCY_DISPLAY_PRECISION = 3    // Number of decimals used to display the frequency.
};

enum KeyboardParams: int {
  KEYBOARD_TIMEOUT = 250
};

enum IOBuffers: uint8_t {
  KB_RING1 = 16,
  KB_RING2 = 16,
  LCD_RING = 64
};

enum EEPROMStorageParams: uint8_t {
  EEPROM_VALID_FLAG_VALUE = 0xbf,
  EEPROM_VALID_FLAG_ADDRESS = 0,
  EEPROM_STRUCT_SIZE_ADDRESS = 1,
  EEPROM_SETTINGS_ADDRESS = 2
};

enum GeneralParams: uint32_t {
  MCU_FREQUENCY = 16000000,
  ISR_FREQUENCY = 200,
  HANDSHAKE_STARTUP_DELAY_MILLIS = 500
};

// ============================  Dynamic Settings ================================= //

struct Settings {
  DisplayMode displayMode = static_cast<DisplayMode>(DISPLAY_MODE_DEFAULT_SETTING);
  InputMode inputMode = static_cast<InputMode>(INPUT_MODE_DEFAULT_SETTING);
  bool autoscrollEnabled = AUTOSCROLL_DEFAULT_SETTING;
  bool echoEnabled = ECHO_DEFAULT_SETTING;
  char delimiter = DELIMITER_DEFAULT_SETTING;
  int rngSeed = RNG_DEFAULT_SEED;
  int programSlot = 0; 

  bool operator==(Settings const &other) const {
    return (displayMode == other.displayMode) &&
           (inputMode == other.inputMode) &&
           (autoscrollEnabled == other.autoscrollEnabled) &&
           (echoEnabled == other.echoEnabled) &&
           (delimiter == other.delimiter) && 
           (rngSeed == other.rngSeed) && 
           (programSlot == other.programSlot);
  }

  bool operator!=(Settings const &other) const {
    return !(*this == other);
  }
};

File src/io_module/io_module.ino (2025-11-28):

#include "settings.h"
#include "common.h"
#include "lcdbuffer.h"
#include "lcdscreen.h"
#include "keyboardbuffer.h"
#include "button.h"
#include "lcdmenu.h"
#include "random.h"
#include "timer1.h"

// Global objects
Settings settings;
KeyboardBuffer kbBuffer(settings);
LCDBuffer lcdBuffer(settings);
LCDScreen lcdScreen(settings);
LCDMenu lcdMenu(lcdScreen, settings, lcdBuffer, kbBuffer);
Random rng;

// Pointer to RNG seed value needed to update from menu
int *rngSeedPtr = &settings.rngSeed;
int *slotPtr = &settings.programSlot;

// Errors
namespace Error {
  volatile enum ErrorType : uint8_t { 
    NONE,
    REACHED_DEFAULT_1,
    REACHED_DEFAULT_2,
    REACHED_DEFAULT_3
  } errno = NONE;

  void assert(ErrorType err = Error::NONE) {
    if (Error::errno == err) return;
    lcdScreen.displayTemp(-1, "I/O Error: %d", Error::errno);
    while (true) {};
  }
}

// Buttons
auto scrollUpButton = Button::create<SCROLL_UP_PIN>();
auto scrollDownButton = Button::create<SCROLL_DOWN_PIN>();
auto menuButton = ButtonPair::create(scrollUpButton, scrollDownButton);

namespace ISR {
  void onTimer();
  void onKCleared();
}

void setup() {
  // Setup for the pins
  pinMode(DISPLAY_ENABLE_PIN, INPUT);
  pinMode(KEYBOARD_ENABLE_PIN, INPUT);
  pinMode(K_OUT_PIN, OUTPUT);
  pinMode(K_IN_PIN, INPUT);
  digitalWrite<K_OUT_PIN, LOW>();
  setIOPinsToInput();

  // Initialize buttons
  scrollUpButton.begin();
  scrollDownButton.begin();
  menuButton.begin();

  // Initialize buffers
  kbBuffer.begin();
  lcdBuffer.begin();

  // Load settings from EEPROM
  lcdMenu.loadSettings();

  // Initialize RNG using loaded seed value
  rng.begin(settings.rngSeed);

  // Initialize screen
  lcdScreen.begin();

  // Block until the handshake has been completed
  handshake();

  // Start ISR timer and attach K-flag interrupt
  attachInterrupt(digitalPinToInterrupt(K_IN_PIN), ISR::onKCleared, FALLING);
  Timer1::start<ISR_FREQUENCY, ISR::onTimer>();
}

void loop() {
  Error::assert();

  // Process raw data in the first ringbuffer of the keyboard. This
  // data will become available as ASCII characters through kbBuffer.get().
  kbBuffer.update();

  // Process raw data in the LCD ringbuffer and put it into the screen-buffer.
  lcdBuffer.update();

  // Send the view (visible window of the screen-buffer) to the screen.
  lcdScreen.display(lcdBuffer.view());

  // Handle buttons for scrolling, accessing the menu or displaying the frequency.
  handleButtons();
}

void handleButtons() {
  // Update button-states
  scrollUpButton.update();
  scrollDownButton.update();
  menuButton.update();

  // If in the menu, forward button-states to the menu
  if (lcdMenu.active()) return lcdMenu.handleButtons(scrollUpButton.state(),
                                                     scrollDownButton.state(),
                                                     menuButton.state());

  if (menuButton.isJustPressed()) return lcdMenu.enter();
  if (menuButton.isHold())        return /* no effect */;

  // No menu or frequency stuff going on -> buttons are used for scrolling the buffer
  scroll();
}

void scroll() {
  // assumes buttons have been updated recently
  unsigned long currentTime = millis();
  static unsigned long previousScrollTime = 0;
  bool const scrollingAllowed = (currentTime - previousScrollTime) > NO_SCROLL_DELAY;

  if (scrollingAllowed && scrollUpButton.isDown()) {
    lcdBuffer.scrollUp();
    previousScrollTime = currentTime;
  } else if (scrollingAllowed && scrollDownButton.isDown()) {
    lcdBuffer.scrollDown();
    previousScrollTime = currentTime;
  }
}

void echo(char const c) {
  lcdBuffer.enqueue(c);
}

void setK() {
  digitalWrite<K_OUT_PIN, HIGH>();
  __asm__ __volatile__("nop\n\t");
  digitalWrite<K_OUT_PIN, LOW>();
  __asm__ __volatile__("nop\n\t");
}

void handshake() {
  delay(HANDSHAKE_STARTUP_DELAY_MILLIS); // TODO: check if necessary

  // Phase 1: wait for CPU to finish initialization (cannot claim the bus while it is still at INIT)
  setK();
  while(digitalRead<K_IN_PIN>()) {}

  // Phase 2: CPU has cleared K -> it is waiting for the program slot
  setIOPinsToOutput();
  writeByteToBus(settings.programSlot);
  setK();
  while(digitalRead<K_IN_PIN>()) {}

  // Phase 3: CPU has cleared K again -> done
  setIOPinsToInput();
}


//----------isr_begin----------
namespace ISR {
  void panic(Error::ErrorType err) {
    Timer1::stop();
    detachInterrupt(digitalPinToInterrupt(K_IN_PIN));
    Error::errno = err;
  }

  static volatile enum : uint8_t {
    IDLE,
    WAIT_FOR_KEYBOARD,
    WAIT_AFTER_WRITE,
    WAIT_AFTER_READ
  } state = IDLE;

  void onKCleared() {
    switch (state) {
      case IDLE: return;
      case WAIT_AFTER_WRITE: setIOPinsToInput(); break;
      case WAIT_AFTER_READ:  break;
      default: return panic(Error::REACHED_DEFAULT_1);
    }
    state = IDLE;
    Timer1::restart();
  }

  void writeByteToBusAndWait(uint8_t const value) {
    Timer1::stop();
    setIOPinsToOutput();
    writeByteToBus(value);
    setK();
    state = WAIT_AFTER_WRITE;
  };

  void enqueueByteFromBusAndWait() {
    Timer1::stop();
    lcdBuffer.enqueue(readByteFromBus());
    setK();
    state = WAIT_AFTER_READ;
  };

  void onTimer() {
    switch (state) {
      case IDLE: break;
      case WAIT_FOR_KEYBOARD: {
        if (kbBuffer.available()) {
          writeByteToBusAndWait(kbBuffer.get());
        }
        return;     
      }
      default: return panic(Error::REACHED_DEFAULT_2);
    }

    bool const EN_OUT = digitalRead<DISPLAY_ENABLE_PIN>();
    bool const EN_IN = digitalRead<KEYBOARD_ENABLE_PIN>();

    switch (EN_IN << 1 | EN_OUT) {
      case 0b00: return;
      case 0b01: return enqueueByteFromBusAndWait();
      case 0b10: {
        if (settings.inputMode == IMMEDIATE || kbBuffer.available()) {
          return writeByteToBusAndWait(kbBuffer.get());  
        } else {
          state = WAIT_FOR_KEYBOARD;
          return;
        }
      }
      case 0b11: return writeByteToBusAndWait(rng.get());
      default:   return panic(Error::REACHED_DEFAULT_3);
    }
  }
} // namespace ISR
//----------isr_end----------

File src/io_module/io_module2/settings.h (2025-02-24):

#pragma once

#define LCD_COMMAND_EXECUTION_MICROS 40

enum LCDDriverPins: uint8_t {
  // Connections frp, Shift Register to Arduino
  SH_CP = 6, // SRCLK
  DS    = 5, // SER
  ST_CP = 4, // RCLK

  // Connections from LCD panel to Shift Register
  RS_595 = 1,
  E_595  = 3,
  D0_595 = 4,
  D1_595 = 5,
  D2_595 = 6,
  D3_595 = 7
};

enum ModuleDriverPins: uint8_t {
  SYSTEM_CLOCK_INTERRUPT_PIN = 2,
  KEYBOARD_CLOCK_INTERRUPT_PIN = 3,
  DISPLAY_ENABLE_PIN = A1,
  KEYBOARD_ENABLE_PIN = A2,
  SCROLL_UP_PIN = A3,
  SCROLL_DOWN_PIN = A4,
  KEYBOARD_DATA_PIN = A5,

  D0 = 7,
  D1 = 8,
  D2 = 9,
  D3 = 10,
  D4 = 11, 
  D5 = 12,
  D6 = 13,
  D7 = A0
};

static constexpr uint8_t DATA_PINS[] = {D0, D1, D2, D3, D4, D5, D6, D7};

enum DisplayMode: uint8_t {
  ASCII,
  DECIMAL,
  HEXADECIMAL,
  N_MODES
};

static constexpr char const *displayModeString[N_MODES] = {
  "Text",
  "Decimal",
  "Hexadecimal"
};


enum LCDParams: int {
  VISIBLE_LINES = 2,
  TOTAL_LINES = 20,
  LINE_SIZE = 16,
  TAB_WIDTH = 4,
  NUMBER_MODE = HEXADECIMAL,
  NUMBER_SEPARATOR = '|',
  BUTTON_DEBOUNCE_DELAY = 200,
  BOOT_MESSAGE_DELAY = 500,
  NO_SCROLL_DELAY = 200,
  DIRECT_MESSAGE_TIME = 1000,
  HOLD_TO_CLEAR_TIME = 2000
};

static_assert((int)NUMBER_MODE == (int)HEXADECIMAL || (int)NUMBER_MODE == (int)DECIMAL, 
  "NUMBER_MODE must be either DECIMAL or HEXADECIMAL");

static_assert(NUMBER_SEPARATOR >= 32 && NUMBER_SEPARATOR <= 126, 
  "NUMBER_SEPARATOR must be printable (32 - 126).");

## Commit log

2023-09-21 Switch 74161 with 74193
2023-10-18 lcd driver (nano)
2023-10-18 Updated driver: scrolling
2023-10-21 moved lcd driver into separate folder
2023-10-25 used grammerly for Implementation/Registers, and started making circuit diagrams
2023-10-28 Circuit: D-R, DP-R, and Driver Module
2023-10-28 created driver module and 4 bit counting register in logisim. Problem discovered: I thought it would be handy to drive all the signals through the driver (EN, LD, CE, DEC) but that would mean we can 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
2023-11-01 wrote docs about new driver module, moved the old driver module to appendix A
2023-11-02 Magister werkte niet
    [voorbeeld_data_beweging.xlsx]
2023-11-15 bflash firmware and driver
2023-11-18 fixed bug in firmware
    [programmer_firmware.ino]
2024-01-10 added elong_wire_ram.png and counters circuit in logisim
2024-03-14 english script for PWS, python venv and Manim init
    [pyvenv.cfg]
2024-12-27 started building schematics in kicad (not yet included in docs)
    [decoder.kicad_sch]
2024-12-30 Built circuits in Kicad to be used in documentation later
    [data_pointer_register.kicad_sch, data_register.kicad_sch, decoder.kicad_sch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]
2024-12-30 deleted Arturs PWS stuff
    [pyvenv.cfg]
2024-12-30 removed kicad support files
2024-12-30 simple arduino clock for debugging
2024-12-30 lcd circuit
    [lcd_module.kicad_sch]
2025-01-10 fixed bug in programmer where the output was enabled all the time
    [programmer_firmware.ino]
2025-01-10 reworked lcd module to be io module that accepts keyboard input
    [io_module.ino, lcdbuffer.ino, settings.h]
2025-01-10 Updated schematics
    [data_pointer_register.kicad_sch, instruction_pointer_register.kicad_sch, io_module.kicad_sch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]
2025-01-10 documented master clock
    [master_clock.kicad_sch]
2025-01-11 documented data and datapointer registers
    [data_pointer_register.kicad_sch, data_register.kicad_sch, master_clock.kicad_sch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]
2025-01-12 More documentation done
    [eeprom_programmer.kicad_sch, instruction_pointer_register.kicad_sch, io_module.kicad_sch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]
2025-01-12 added pin numbers of the HC595 which I can never remember
2025-02-22 switched to other liquidcrystal library and modified to use fast digitalwrite
2025-02-22 fixed whoopsie in button.h (INPUT instead of OUTPUT)
2025-02-24 worked on docs a bit
    [loop_skip_register.kicad_sch, signal_distributor.kicad_sch, signal_fetcher.kicad_sch]
2025-02-24 io module directory tree was wrong
    [LiquidCrystal_74HC595.ino, io_module.ino]
2025-02-25 buttonpair was changing the state, now peekable
2025-03-01 switched to compiletime version of building the menu-tree
2025-03-10 more documentation
    [control_unit.kicad_sch, data_pointer_register.kicad_sch, master_clock.kicad_sch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]
2025-03-16 fixed bug in ringbuffer
    [LiquidCrystal_74HC595.ino, io_module.ino]
2025-03-19 updated button class to be fully static (no virtuals anymore)
2025-03-23 made the menu work nicely on bigger/smaller screens and fixed cursor bug
    [io_module.ino, keyboardbuffer.ino, lcdbuffer.ino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]
2025-10-13 random number generator (fixed seed)
    [io_module.ino]
2025-10-18 handshake with IO at boot; big bugfix inside mu-spec where LS was incremented instead of IP at the end of a loop
    [LiquidCrystal_74HC595.ino, io_module.ino, lcdbuffer.ino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]
2025-11-01 document restructuring
    [control_unit.kicad_sch]
2025-11-02 updated timer schematic
2025-11-19 implemented program slots and updated docs
    [register_driver.kicad_sch]
2025-11-19 more doc
    [master_clock.kicad_sch]
2025-11-22 bfasm can now add BF code before each program that prints the filename at runtime
2025-11-28 improved IO, documentation updated
    [io_module.kicad_sch]
2026-08-09 added download button to home page
